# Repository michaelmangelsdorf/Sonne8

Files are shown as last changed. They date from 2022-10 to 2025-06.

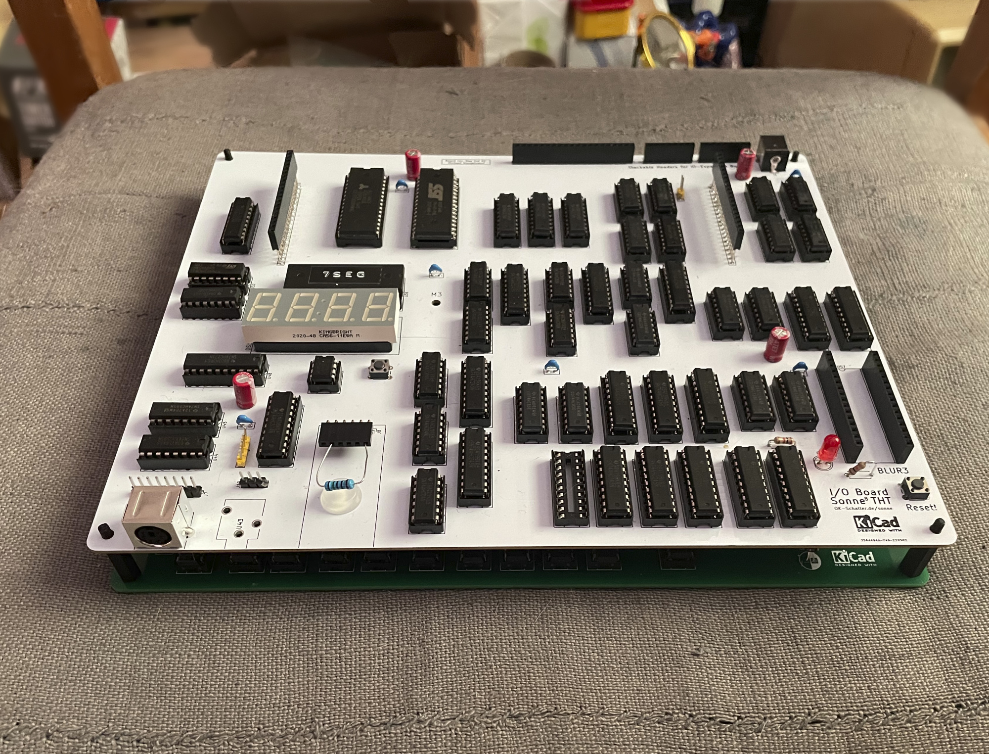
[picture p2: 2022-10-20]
Prototype/board_ready.jpg

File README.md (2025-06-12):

UPDATE: There is now a [successor project](https://github.com/michaelmangelsdorf/myth).

Computer project around an 8-bit microcontroller I've designed.

There are design files for a working single-board computer built around it in the 'Prototype' folder. I've had the PCB for it manufactured by JLCPCB during various revisions. The computer now works fine at 8 MHz system clock, which corresponds to around 1 million instructions per second. The main components are all 74HC-series CMOS chips. I basically wanted to design a CPU I could actually build from parts, not just inside an FPGA like [my previous](https://github.com/Dosflange/Paver) 16-bit machine.

The current reference schematics I'm using are [here](https://github.com/Dosflange/Myth/blob/main/docs/static/myth.pdf).
If I were to build another board, it would probably be based on the KiCad files in the 'Schematics' folder, where I
separated the schematics into functional modules.

So what this image shows is not an application board with an Arduino or anything, it is the actual microcontroller. The current version
has exactly 100 chips.

CPU board

There are two software emulators I've written for this system. The code is very small, hopefully it's a good reference for finding out about the CPU.
The decoder-based [implementation](https://github.com/Dosflange/Myth/blob/main/Dev/src/clox/myth.h) is more high-level, and
the [dispatch table](https://github.com/Dosflange/Myth/blob/main/Dev/src/clox/vtable.c) version better suited to finding out about particular instructions.

[Documentation WIP](https://michaelmangelsdorf.github.io/Sonne8/)

__Update Sep.24__:

I've written a new assembler for this machine in Go(lang). The first thing I ported from the old format was
this multiplication routine. It multiplies two unsigned 8-bit numbers and returns a 16-bit result.
You can try it out with the tools in the 'Dev' folder.

```
Goldie/LOX assembly log
Page.Offset  Object code  Lid Line# Source text

                        048 0062  ;****** ***************************************************************
                        048 0063  P[Mul8]+  (Multiplies R by O, result in R and O)
                        048 0064  ;****** ***************************************************************
                        048 0065  
21.00:  07 5E           043 0066        OWN i6        (Save return pointer in L7/L6)
21.02:  79              043 0067        o1            (Multiplicand into L1, turns into low order result)
21.03:  68              043 0068        r0            (Multiplier into L0)
21.04:  10 6A           043 0069        CLR r2        (Clear high-order result, copy to L2)
21.06:  85 07           043 0070        ni 07h        (Initialise loop counter, 8 bits)
                        043 0071  
                        043 0072      O[Mul8Loop]
                        043 0073   
21.08:  80 01           043 0074        no 01h        (Bit mask for LSB)
21.0A:  61 18           043 0075        1r AND        (Check if multiplicand has LSB set)
21.0C:  8E 12           043 0076        nf >Mul8Skip  (Skip if not)
21.0E:  60 72 1B 6A     043 0077        0r 2o ADD r2  (Add multiplier to high order result)
                        043 0078  
                        043 0079      O[Mul8Skip]
                        043 0080  
21.12:  80 01           043 0081        no 01h        (Bit mask for LSB)
21.14:  62 18 6B        043 0082        2r AND r3     (Prepare flag of whether high order LSB is set)
21.17:  61 16 69        043 0083        1r SRR r1      (Shift low-order result right)
21.1A:  62 16 6A        043 0084        2r SRR r2       (Shift high-order result right)
                        043 0085  
21.1D:  63 8E 25        043 0086        3r nf >Mul8Done  (Check flag from earlier - HO LSB set?)
21.20:  84 80           043 0087        nr 80h          (Bit mask for MSB)
21.22:  71 19 69        043 0088        1o IOR r1     (Handle shift-result carry bit into MSB)
                        043 0089  
                        043 0090      O[Mul8Done]
                        043 0091  
21.25:  8C 08           043 0092        nw <Mul8Loop
21.27:  71              043 0093        1o            (Result low-order)
21.28:  62              043 0094        2r            (Result high-order)
21.29:  56 05           043 0095        6i RET        (Restore return pointer from L7/L6)
```

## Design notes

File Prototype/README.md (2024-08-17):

Welcome to this project!

/* Update: I've presented this at CrashSpace in Culver City (Los Angeles) on October 10th, 2023 and donated my build of the controller, including two spare PCBs. So if you're in the area and would like to work on it / have questions, ask anytime. Thanks to all who where there, physically and online, and for the tour of your premises! */

This repo contains all files you need to build and program an 8-bit CPU that I have designed und built.

It's not even micro-coded, so it's very simple, although I wanted it to be sane and fun to code for instead of minimal. It's easy to create custom instructions, it's got single-cycle trap calls that don't appear different from inbuilt opcodes.

You would need to have the two PCBs fabricated: Firstly, there's the CPU board itself.
It is actually a micro-controller, in that this board implements RAM and an IO interface.
Then secondly, there is an IO expansion board, that fits on top of the CPU board via Arduino type stackable headers.

What can it do? Well, the demo program computes 7 x 13 and shows the result (5B in hexadecimal) on a 7-segment display (see the mul16 movie in the repo)... Behind the scenes, it reads the code for doing that by bit-banging the SPI interface of a serial EEPROM on the IO board. So it's a micro-controller alright.

The two KiCad boards work fine!, I've had them manufactured by JLCPCB. The project files in the repo correspond to what I sent them. The screenshots (jpeg) of the boards show details. I've soldered sockets for all chips to be safe. The quartz oscillator I used is 8MHz, which corresponds to roughly 1 Million instructions per second.

The CPU board looks like this (this is an older version, notice the wire patch):

CPU board

These plastic spacers go between the CPU board and the IO board. The distance/length of the spacer part (without the protruding thread) is 2 cm.

CPU board

Both modules go together like so:

CPU board

The assembled development kit i.e. hardware portion of this project:

CPU board

The entire lower right quarter of the IO board doesn't really need to be populated, but you can of course. The large chip socket on the right
is just a place-holder that connects straight through to the identical EEPROM socket just below it on the CPU board.
That EEPROM is actually the ALU of the CPU. It does via simple look-up tables, what the discrete version on the IO board does with logic chips.

## Address space

The address space of this CPU is unusual. Eight bits give you 256 address places. The first 128 places form a segment, which can be switched to point to another memory segment ("bank switching"). The next 64 places after that are fixed (for global variables). The remaining 64 places form a segment again, which can be switched out to point to another memory segment (for local variables).

### Global segment

This 64 byte segment serves as a global (i.e. persistent during subroutine calls) data repository.
The first eight addresses (128-135) of it are referred to as G0-G7 (G for global) and there are special single-cycle instructions for transfering these values to and from the two accumulator registers. These locations are essentially additional registers.

### Local segment

This 64 byte segment serves as a stack frame, which can be swapped out by the following two instructions.
The first eight addresses (192-199) of it are referred to as L0-L7 (L for local) and there are special single-cycle instructions for transfering these values to and from the two accumulator registers. These locations are essentially additional registers local to the current subroutine!

#### Leave and Enter

The LEAVE signal increments an internal address prefix. This causes the final 64-bytes ("local" segment) of the address space to point to the previous stack frame. The ENTER signal decrements the internal address prefix, causing a new stack frame to appear in the "local" segment.

## Binary Instruction Format

There are four types of instructions. The format is completely regular and you would have no problem hand-coding these opcodes!

SIGNAL
If bit 7 is clear, and bits 0-3 are all zero, the instruction is of type SIGNAL. There are sixteen such instructions, corresponding to each combination of bits 4-6. These instructions trigger internal signals.

RCOPY
If bit 7 is clear, and bits 0-3 are *not* all zero, the instruction is of type RCOPY. In this case, bits 0-3 encode one of eight possible source registers, and bits 4-6 encode one of sixteen possible target registers. Each instruction of type RCOPY copies the value of its source register into its target register.

TRAP
If bit 7 is set, but bit 6 is clear, the instruction is of type TRAP, and bits 0-5 encode the memory bank address of a trap handler function. Each TRAP instruction performs a function call to the first byte of its trap handler bank.

GETPUT
If bits 6-7 are both set, the instruction is of type GETPUT. These instructions copy values between the first eight bytes (G0-G7) of the global segment or the first eight bytes (L0-L7) of the local segment and registers A or B.
Bits 0-5 encode the operation of each such instruction in the following way.
Bit 5 encodes the source or destination register: 0=A, 1=B
Bit 4 encodes the segment: 0=Global, 1=Local
Bit 3 encodes the operation: 0=Read (Get), 1=Write (Put)
Bits 0-2 encode the byte offset within the segment
Example:
The mnemonic "aG3g" ("a G3 get") would mean:
"a": Register A is the target of the operation. "G": Global memory is being used. "3": The third location in global memory is being accessed. "g": Get operation, the value from the specified memory location is being read and loaded into register A. So, "aG3g" instruction gets the value from the third location of global memory and loads it into register A.

### Signal instructions

These are used to trigger specific operations that don't require explicit arguments, such as IO operations or creating/destroying stack frames.

### Register-to-register transfers ("RCOPY")

These instructions copy the content of one register into another. GA for instance copies the value of G into A. Some registers are pseudo registers, such as B (Branch) -- copying a source register into B branches to the location stored in the source register. See the descriptions of individual registers below. 

#### Scrounge instructions

Instructions such as MM or SS that would essentially do nothing ("NOP"), and instructions such as LM which would conflict with the timing requirements and the complexity of the hardware required, are detected (preselected) by a logic module called the scrounger, and they are treated as entirely different instructions -- their opcode is "repurposed". For instance, the opcode with regular mnemonic LM is scrounged and repurposed as opcode for the RET instruction.

Not all such "NOP" opcodes are "scrounged" and could potentially be used as CPU instruction set extensions in future versions.

### Trap calls ("TRAP")

When a TRAP instruction is encountered during program execution, it triggers a transparent subroutine call to a user-defined TRAP handler routine. This handler routine acts as the implementation of the custom instruction, enabling the execution of specialized operations that go beyond the capabilities of the standard built-in instructions.

User-defined instructions implemented through trap handlers are indistinguishable from pre-existing built-in instructions. They allow developers to create new instructions that appear and behave just like native instructions to the processor.

Flexible Byte Lengths:
Custom instructions defined through trap calls can have variable byte lengths. The PULL instruction facilitates this. It allows the custom instruction's handler routine to access subsequent bytes in the instruction stream, enabling the retrieval of data or parameters specific to the functionality of the custom instruction. This flexibility opens up possibilities for instructions with different byte lengths tailored to specific requirements, such as immediate addressing.

In this way, the TRAP mechanism in Sonne architecture allows you to effectively "extend" the instruction set with your own custom operations. By strategically writing and calling these trap handlers, you can enhance the functionality of the processor in ways that go beyond the capabilities of the built-in instructions. 

### Memory-Register-Memory transfers ("GETPUT")

These instructions copy values between the 8 bytes G0-G7 of the global segment or the 8 bytes L0-L7 of the local segment and registers A or Q.

#### Examples

The mnemonic "aG3g" ("a G3 get") would mean:

"a": Register A is the target of the operation.
"G": Global memory is being used.
"3": The third location in global memory is being accessed.
"g": Get operation, the value from the specified memory location is being read and loaded into register A.
So, "aG3g" instruction gets the value from the third location of global memory and loads it into register A.

"aL7p": This instruction would put the value from register A into the seventh location of local memory.
q: Indicates that the data (Q) register is the source or target of the operation.
"qG2g": This instruction would get the value from the second location of global memory and load it into register Q.
"qL5p": This instruction would put the value from register Q into the fifth location of local memory.
Remember that in these mnemonics, the first character ("a" or "q") denotes the register being operated upon, the second character ("G" or "L") specifies the scope of the memory being accessed (Global or Local), the third character (a digit from 0-7) specifies the location in the specified memory, and the last character ("g" or "p") specifies the operation (Get or Put).

## Fetch mechanism

The X register holds the byte offset for instruction fetches. It represents the byte offset within the code branch (frame) from which the next instruction will be fetched.
The X register is incremented by 1 after each instruction, so that the next instruction is pointed to.
Jump instructions reset the X register to 0 (!), jumps are made to first bytes (offset 0) of a target bank.

The Y register holds the pending code branch (high order portion or "bank"). The value stored in the Y register represents the code branch that will be resumed upon executing a RET instruction.

The LID instruction (LID stands for the English word "lid") resets the byte offset for instruction fetches to 0, and increments the current frame by 1.
LID is called "LID" because it effectively closes ("puts a lid on") the currently executed frame.

In the assembler code I provided, a "." assembles to a LID opcode. So a dot in an assembler listing closes the current frame and begins at the next frame, byte offset 0. It is just a shorthand for explicitly writing LID.

## Groups of registers

### L

L stands for literal. It's a pseudo-register that can only be a source in register-register transfers. The value transfered is the next byte in the instruction stream, which is then skipped.

### A, B and M

M is a pseudo-register. Reading or writing it transfers between memory and a register operand.
The last recently used ALU register - A or B - is the implied offset address register that combines with a bank register to give the effective address.

### R

The R register holds the bank prefix of the 128 byte "row" region from 0-127 of the address space. Changing R switches all 128 bytes simultaneously by address mapping.

### J, E, T

These are pseudo-registers, that can only occur as register-targets in transfers. Transfering a value to B does an unconditional jump to that "branch". You can't jump to a byte offset, only to the first byte offset (0) of a branch. E means Else - the branch is taken when the ALU result is zero. T means Then - the branch is taken when the ALU result is not zero.

### C, X, Y

The C register is a pseudo register, that can only occur as a register-target in transfers. Transfering a value to C executes a subroutine call. The "branch" get's stored in Y, the byte offset for instruction fetches within that "branch" gets stored in X. By writing values into X and Y, the return address can be redirected. The RET signal returns from the subroutine, by restoring the "branch" and byte offset from X and Y. The PULL signal transfers the current X into A, and the current Y into R.

### A, B, F

A and B are two accumulator registers. These are the two input operands connected to the ALU (Arithmetic-Logic Unit). F stands for Function. Writing an ALU opcode to F computes the respective function. Reading from F yields the result.

A and B are not readable directly. The intended way is to execute one of the identity functions of the ALU, IDA or IDB.

To prepare ALU input values, program the ALU, and retrieve the result, the following steps are typically involved:

Load Operand Values: The input values for the ALU operation need to be loaded into the A and B registers. This can be done by transferring values from memory or other registers to the A and B registers using appropriate transfer instructions.
Set ALU Opcode: Determine the specific ALU operation you want to perform and set the corresponding ALU opcode. The ALU opcode is written to the F register, which programs the ALU to perform the desired operation.
Execute ALU Operation: Trigger the execution of the ALU operation by performing an ALU instruction that uses the A and B registers as source operands and the F register as the target. The ALU will perform the specified operation on the input operands and store the result in the F register.
Retrieve Result: After the ALU operation is executed, the result will be stored in the F register. Retrieve the result from the F register for further processing or storing in memory if needed.
These steps ensure that the input values are properly prepared, the ALU is programmed with the desired operation, the ALU operation is executed, and the result is retrieved for subsequent use or storage.

In Sonne, the F register functions differently depending on whether it is used as an input register or when it is read from. This distinction is important and can be easily overlooked.

When the F register is used as an input register, it serves as a parameter to program the ALU's operation. The value written to the F register determines the specific ALU opcode, which in turn determines the arithmetic or logical operation to be performed. It essentially configures the ALU's behavior for the subsequent operation.

On the other hand, when the F register is read from, it holds the most recent result produced by the ALU. This result reflects the outcome of the operation executed using the previously programmed ALU opcode. In this context, the F register acts as a storage location for the ALU result, allowing it to be accessed by subsequent instructions or transferred to other registers.

This distinction highlights the dual role of the F register in Sonne: as a configuration parameter for the ALU when written to, and as a storage location for the ALU result when read from. It is important to understand this behavior to properly utilize the ALU and interpret the effects of instructions involving the F register.

### ALU instructions

ALU instruction words (to be written to the F register) are bytes. The low order 4 bits encode the following 16 instructions:

```
|--- | --- | --- |--- |
| 0 |   IDA | Identity A | F := A |
| 1 |   IDB | Identity B | F := B |
| 2 |   OCA | Ones Complement A | F := ~A |
| 3 |  OCB | Ones Complement B | F := ~B |
| 4 |   SLA | Shift left A | F := A<<1 |
| 5 |   SLB | Shift left B | F := B<<1 |
| 6 |   SRA | Shift right A | F := A>>1 |
| 7 |   SRB | Shift right B | F := B>>1 |
| 8 |   AND | Logical A AND B | F := A&B |
| 9 |   IOR | Logical A OR B | F := A\|B |
| 10 |  EOR | Logical A XOR B | F := A\^B |
| 11 |  ADD | Bits 0-7 of A+B | F := (A+B)&255 (ignore carry) |
| 12 |  CYB | Carry bit of A+B | F := A+B; F := (F>255)?1:0 |
| 13 |  ALB | A less than B | F := (A<B)? 0xFF:0 |
| 14 |  AEB |A equals B | F := (A==B)? 0xFF:0 |
| 15 |  AGB |A greater than B | F:= (A>B)? 0xFF:0 |
```

The high order 4 bits hold a signed 3 bit offset which is added to the ALU result. In the assembly language, these mnemonics can be followed by an optional number term, such as IDA+2, SLB+1 etc. The default ALU operation on reset is "IDA+0".
Read ALU results from the F register.

## IO

### D, S, P

The D register selects IO bus devices in an implementation specific way (for example SPI device select etc). Writing to P (Parallel) transfers a byte onto the tri-state IO bus. Reading from P transfers a byte from the IO-bus. Use the OFF signal to tri-state the bus. Writing to P also removes the tri-state.

Writing to the S (Serial) register puts that byte into a shift-register for serialization. The CSO signal ("clock serial out") shifts out one bit on the MOSI line. Reading from S yields the currently deserialized byte in the shift-register. The CSI signal ("clock serial in") shifts in one bit from the MISO line. The SCH and SCL signals respectively toggle the serial master clock high or low.

The serial interface facilitates serial communication between the CPU and external devices.
The S (Serial) register acts as a shift register, allowing data to be transmitted or received bit by bit.
The CSI (Clock Serial In) instruction clocks the serial input shift register, reading in data.
The CSO (Clock Serial Out) instruction clocks the serial output shift register, sending out data.
Device Selection:
The D register is involved in device selection for serial or parallel communication.
By setting specific bit patterns in the D register, the CPU can select specific devices connected to the bus for communication.

### Parallel IO

Parallel Interface:
The parallel interface enables communication between the CPU and external devices using a parallel bus.
The P (Parallel) register is used for data transfer. Reading from the P register retrieves a byte value from the parallel bus, and writing to it sends a byte value onto the bus.
The OFF instruction can be used to tristate the parallel bus, disabling its output when necessary.

### Serial IO

The Serial Peripheral Interface (SPI) protocol can be implemented using the Sonne processor's instructions, including SCL, SCH, CSI, and CSO, along with proper configuration of control signals. Here's a description of how the SPI protocol can be implemented with the Sonne instructions:

In addition to the serial input and output shift registers, the Sonne processor utilizes the U and V registers for device selection and deselection in serial communication.

Here's an expanded summary of the serial communication capabilities of Sonne, including the roles of U and V:

Device Selection: Before communicating with a specific device connected to the serial bus, the corresponding bit pattern representing the device must be set in either the D register. This selection process ensures that the desired device is enabled for communication.
Data Transmission: To transmit data to the selected device, the processor loads the data to be sent into a register or memory location. The CSO (Clock Serial Out) instruction is then executed, which clocks the serial output shift register. As each bit is shifted out, it is sent to the selected device through the serial bus.
Device Deselection: After data transmission is complete, the selected device needs to be deselected to allow other devices to communicate on the bus. This is done by clearing the bit pattern in the D register corresponding to the device. Deselecting the device prevents further communication with it.
Data Reception: To receive data from an external device, the CSI (Clock Serial In) instruction is used. It clocks the serial input shift register, allowing the processor to receive one bit of data at a time from the selected device. The received data can then be processed or stored in registers or memory.
By utilizing the D registers for device selection and deselection, the Sonne processor can communicate with different devices connected to the serial bus in a controlled and synchronized manner. It allows for flexible communication with multiple devices using a serial interface such as SPI, ensuring proper device selection and enabling reliable data transmission and reception.

CPOL (Clock Polarity):
The CPOL parameter determines the idle state of the clock signal.
In Sonne, the SCL (Set Clock Low) and SCH (Set Clock High) instructions can be used to control the clock signal's state.
To configure CPOL=0 (clock idles low), execute SCL to set the clock signal low during the idle state.
To configure CPOL=1 (clock idles high), execute SCH to set the clock signal high during the idle state.
CPHA (Clock Phase):
The CPHA parameter determines the edge of the clock signal where data is captured or changed.
In Sonne, the CSI (Clock Serial In) and CSO (Clock Serial Out) instructions can be used to control data transfer on each clock transition.
To configure CPHA=0 (data captured on the leading edge), execute CSI before the clock transition to capture the incoming data.
To configure CPHA=1 (data captured on the trailing edge), execute CSI after the clock transition to capture the incoming data.
Similarly, to transmit data on the leading or trailing edge, execute CSO before or after the clock transition, respectively.
Slave Select (SS) Signal:
In SPI, a Slave Select signal is used to enable/disable specific devices on the bus during communication.
In Sonne, the U and V registers can be utilized to control the Slave Select (SS) signal.
Before initiating communication with a specific device, set the corresponding bit pattern in the D register to select the device.
After communication, clear the bit pattern in the D register to deselect the device.
By combining the SCL, SCH, CSI, and CSO instructions along with appropriate configuration of the control signals, the Sonne processor can effectively implement the SPI protocol. This allows for synchronized and controlled data transfer with SPI-compatible devices, including the flexibility to configure CPOL, CPHA, and SS signals to meet the specific requirements of the SPI interface.

### Parallel Interface
The P (Parallel) Register: Writing to the P register sends a byte of data onto the parallel bus, and reading from the P register receives a byte of data from the parallel bus.
The OFF instruction: This is used to tristate the parallel bus, disabling its output when necessary.

### Serial Interface
The S (Serial) Register: Writing to this register puts a byte into a shift-register for serialization. Reading from this register yields the currently deserialized byte in the shift register.
The CSO Instruction (Clock Serial Out): This instruction shifts out one bit on the MOSI (Master Out Slave In) line from the byte currently held in the shift register.
The CSI Instruction (Clock Serial In): This instruction shifts in one bit from the MISO (Master In Slave Out) line to the shift register.
The SCH and SCL Instructions: These are used to toggle the serial master clock high or low respectively.

### Device Selection
The D register: Each bit in this register selects a specific I/O device, like an SPI device select. This allows for specific device communication during parallel or serial transmission.
 
### Implementing SPI protocol
Through the appropriate use of the S Register and the CSO, CSI, SCH and SCL instructions, the Sonne CPU can implement Serial Peripheral Interface (SPI) communication with external devices.

# Alternative Write-up

## Sonne Programmer's Overview
## Register Model and Instruction Set

## Preliminaries

Bits are numbered starting from 0 (least significant bit) to 7 (most significant bit). Clearing a bit means setting it to zero. Setting a bit (without giving the explicit value 0) means setting it to 1. A byte is an 8-bit number. A nybble is a 4-bit number. A signed binary number means a number in twos-complement notation, its most significant bit representing the numerical sign.

### Assembler Notation

Comments are introduced by a semicolon (";"). Everything on the same line after the semicolon is ignored.

Commas (",") can be used for grouping "phrases" of instructions that logically belong together. They don't generate code and are just for visual clarity.

A dot (".") is shorthand notation for and produces the same output as the "LID" instruction. The assembler will insert the LID-count at offset 127 of the current bank, and place subsequent code into the next bank at offset 0. The dot can be added after other elements without separating space.

#### Number Literals

Decimal numbers from 0-255 can be included the source text as literals, and be prefixed by an optional minus sign. Hexadecimal numbers must be in two uppercase digits and marked with the suffix "h", for instance: "80h" for 128. Binary numbers must be formatted as two 4-bit groups separated by a dot (".") and have the suffix "b", for instance: "0010.0000b" for 32.

#### Code Labels

Code labels are alphanumeric identifiers, preceded with an at-sign ("@") instead of the conventional colon (":") at the end. Code labels mark the beginning of banks (offset=0), and only one label is allowed per bank. This reflects the fact, that branches or calls are made to banks, rather than offsets.

Code labels that mark the beginning of TRAP handler functions must be unique  and referenced by prefixing their identifier by an asterisk ("*").

Such label references will generate an opcode that will trigger a TRAP and call the handler function referenced by the label.
Other labels are referenced by prefixing their identifier with "<" (for backward references, i.e. the label is defined earlier in the source code than the reference to it), or with ">" (forward reference, i.e. the label is defined later than the reference to it in the source code). If a label is not unique, the reference goes to the nearest occurrence of it.

#### Instruction Mnemonics

Mnemonics for Signal PAIR and ALU instructions generate the opcode they map to, for instance "ENTER" generates opcode 112. For ALU instructions, the signed offset can be omitted and defaults to 0 ("SLA+1", "ADD" = "ADD+0", etc.)

Mnemonics for transfer PAIR instructions are two-letter uppercase words such as "FA" (take F into A). Mnemonics of the form ("Nx") for transferring a literal embedded in the code stream into a target register, must be followed by that number, ALU mnemonic or other value to be transferred. For instance "NF SLA" transfers the ALU opcode corresponding to SLS into the function selector register F. "NA 80h" transfers the number 128 into register A.

#### Get-Put Mnemonics

The format for these mnemonics is register + memory location + offset + operation with no intervening space. Register must be lower case "a" or "b". Memory location is upper case G or L. Offset is in the range 0-7. Operation is lower case "g" (get) or "p" (put). 
So, "aG3g" instruction gets the value from the fourth location of global memory (same as bank G, offset 83h) and loads it into register A.

# Part A. Computation

This part explains the core features of the CPU, and for brevity and clarity is limited in scope to those that are intended for computation and addressing internal memory. Part B explains additional, structurally equivalent features that are dedicated to communication with peripherals and can be listed as  mere extensions to what has already been said.

## Addressing

In Sonne, the primary means of addressing memory are 8-bit numbers called offsets, ranging from 0-255. This offset range is partitioned into three segments. As further explained below, the segment in which a particular offset is located determines, which 8-bit bank prefix register is used in generating the effective address. The notation for this is [bank,offset]. This segmentation mechanism achieves, that an 8-bit offset carries a fully implied bank register, considerably extending the addressable range in an intuitive way.

### Banks

Bank numbers are stored in dedicated bank registers. Which bank register is used in accessing memory depends on the segment (see below) in which a given offset address is located, and also depends on whether the memory access is fetching (reading the code stream), or instead reading or writing other data.

This is much simpler in practice than how it sounds in full technical detail, much like the engineering details of a car can seem overwhelming when in reality driving is quite easy.

As has been said, the 256 offset places are partitioned into three segments. A given offset is located in exactly one of the three segments, and a given offset thus uniquely implies the bank prefix register used to create the effective address used.

#### ROW/EXIT segment

If the offset is in the range 0-127, bank register R (Row) is used during data access and bank register E (EXIT) is used when fetching (reading the code stream).

#### GLOBAL and LOCAL segment

The remaining two offset ranges apply for both data access and instruction fetch.

##### Global segment

If the offset is in the range 128-191, bank register G (Global) is used.

This 64 byte segment serves as a global (i.e. persistent during subroutine calls) data repository. The first eight addresses (128-135) of it are referred to as G0-G7 (G for global) and there are special single-cycle instructions for transferring these values to and from the two accumulator registers. These locations are essentially additional registers.

##### Local segment

If the offset is in the range 192-255, bank register L (Local) is used.

This 64 byte segment serves as a stack frame, which can be swapped out by the ENTER and LEAVE instruction. The first eight addresses (192-199) of this segment are referred to as L0-L7 (L for local) and there are special single-cycle instructions for transferring these values to and from the two accumulator registers. These locations are essentially additional registers local to the current subroutine!

#### CPU Internal Addressing

You may have noticed that, since the ROW segment (and also the GLOBAL+LOCAL segments combined) span only 128 bytes instead of the full range of 256 bytes, incrementing a bank register seems to leave 128 bytes of each bank unused.

In order to utilise all of the memory, only the first 7 bits of the offsets are appended to the bank number. The high order bit is actually used as an indicator of LOCAL/GLOBAL access and *prefixed* to the bank number.

In other words, the ROW/EXIT segment and the combined GLOBAL+LOCAL segments live in two adjacent memory blocks of 256 banks each with only 128 bytes per bank instead of 256.

Please see the schematics of the CPU to see how this works in detail to avoid "holes" in the address space.

### Offsets

During instruction fetch, the implied offset is retrieved from the program counter (PC).

During data access, the implied offset is retrieved from the working register W. W is a construct that refers to the last recently written-to accumulator register, A or B. Rather than being a separate register, W is simply a mechanism to point to either of the two accumulator registers.

Whenever a transfer instruction is executed to load data into A or B, "W" is updated to point to that register. For example, if the instruction xA is executed, then the source value is transferred into register A, and W is set to A. Similarly, if the instruction xB is executed, the source value is transferred into register B, and W is set to B.

### Memory access

During instruction fetch, an instruction is fetched from [E, PC].

All other memory operations are achieved by transferring register values into or out of the M (Memory) pseudo-register. The implied memory location is always [R/G/L, W]. In this notation, R/G/L stands for the bank prefix register corresponding to the offset segment in which the offset stored in the working register W is located.

For example, if A is the working register and contains the number 20, the effective address will be the concatenation of the bank address prefix in register R (since the offset 20 lies in that segment) and the offset 20 itself. Therefore, the instruction FM for instance will store the ALU result F into [R, 20].

There is also a dedicated instruction type (Get-Put) which allows transferring values in and out of the accumulator registers into the first 8 locations of the global and local segment, respectively. This is identical to addressing offsets 80-87h (first 8 bytes of global segment) and C0-C7h (first 8 bytes of local segment) but requires only a single instruction and no overhead for setting up address offsets.

## Arithmetic-Logic Computations

The Sonne model includes an Arithmetic-Logic Unit (ALU) connected to the two accumulator registers A and B. The ALU can perform a set of 16 operations on the contents of A and B, controlled by writing an ALU opcode to the function register (F). Results are retrieved by reading from register F. A zero flag used in conditional branching (see below) is computed together with the result. Writing an ALU opcode to F computes the respective function. Reading from F yields the result.

Writing into registers A or B sets that register to be the new working register (W), and sets a HOLD flag (H) which freezes the result in F, until another ALU opcode is written into F which frees the hold (resets H).

This mechanism is required so that the working register (A or B) can be used as destination offset for storing the ALU result. Without it, altering A or B to contain an address offset for storing the ALU result, would generally trigger an additional ALU operation that could modify the result, which is still in F, before it's even stored. By activating HOLD, the ALU freezes its current state, allowing for modifications to A or B for addressing purposes without triggering a new, potentially result-altering, ALU operation. The HOLD is released when the next ALU opcode is written, allowing for the resumption of regular ALU operations. In essence, HOLD ensures the proper sequence and integrity of computational and memory operations.

### ALU opcodes

An ALU opcode is a byte, in which bits 0-4 encode one of the following 16 instructions, and bits 5-7 encode a signed 3-bit binary number which is added to the result. 

Opcode bits 0-3 to the left, followed by mnemonic, description, and pseudo-code

|--- | --- | --- |--- |
| 0 |   IDA | Identity A | F := A |
| 1 |   IDB | Identity B | F := B |
| 2 |   OCA | Ones Complement A | F := ~A |
| 3 |  OCB | Ones Complement B | F := ~B |
| 4 |   SLA | Shift left A | F := A<<1 |
| 5 |   SLB | Shift left B | F := B<<1 |
| 6 |   SRA | Shift right A | F := A>>1 |
| 7 |   SRB | Shift right B | F := B>>1 |
| 8 |   AND | Logical A AND B | F := A&B |
| 9 |   IOR | Logical A OR B | F := A\|B |
| 10 |  EOR | Logical A XOR B | F := A\^B |
| 11 |  ADD | Bits 0-7 of A+B | F := (A+B)&255 (ignore carry) |
| 12 |  CYB | Carry bit of A+B | F := A+B; F := (F>255)?1:0 |
| 13 |  ALB | A less than B | F := (A<B)? 0xFF:0 |
| 14 |  AEB |A equals B | F := (A==B)? 0xFF:0 |
| 15 |  AGB |A greater than B | F:= (A>B)? 0xFF:0 |

## Exit Instructions

The term EXIT instruction refers to any instruction that overwrites register E (EXIT), which contains the currently active bank prefix for fetching instructions.  EXIT instructions are either transfer instructions into J, E, T (JUMPS) or into C (CALLS), the RET instruction (RETURN from subroutine) or TRAP instructions.

### Branching

Branching is done to banks, not offsets. During a branch, the program counter (PC) register holding the current instruction offset is set to zero, and the EXIT bank register is loaded with the target bank to which control control is transferred.

Even though it might seem limiting to only be able to branch to the start of a bank, this can actually lead to clean and well-structured code, as each bank can be thought of as a self-contained part of code that does one specific task within a function.

#### Registers J, E, T

These are pseudo-registers, that can only occur as register-targets in transfers. Transferring a value to J does an unconditional jump to that "branch". You can't jump to a byte offset, only to the first byte offset (0) of a branch. E means Else - the branch is taken when the ALU result is zero. T means Then - the branch is taken when the ALU result is not zero.

The LID instruction (see below) is an implicit jump to offset 0 of next bank. LID resets PC to 0 and increments the bank register by 1.

### Calling and TRAP mechanism

#### Registers C, X, Y

Transferring a value to C executes a subroutine call.  Executing a TRAP instruction has the same effect, except that with C, TRAP destinations can be calculated and provided by a source register at run-time.

During a call or TRAP (see below), the "branch" (register E) get's stored in Y, and the byte offset (register PC) of the instruction gets stored in X. Following that, register E is overwritten with the target bank number, and PC is set to zero.  By altering these values in X and Y, the return address can be redirected, for example in coding custom control-flow instructions.

Registers PC and E can be restored from X and Y by executing RET. This "undoes" the call and returns to the point just after the instruction which triggered the call. Unlike other CPU's, only one call-level is retained. Sonne does not manage a dedicated return stack, and you must save X and Y (see above) into the local segment yourself when implementing nested calls. These return coordinates then essentially become local variables.

#### Local Variables

The local segment can be used as a stack frame for local variables such as the subroutine return address. Executing ENTER decrements the L bank register, and LEAVE increments this register. Since bank registers are used implicitly, any subsequent memory access to the local offset segment will "see" whatever frame is mediated by L.

## TRAP instructions

TRAP instructions are otherwise indistinguishable from other instruction types, except they have bit 7 set and bit 6 cleared. The target bank number is encoded in the remaining lower 6 bits (0-5), hence banks 0-63 can be used to store trap handler functions. These are typically thought of as instruction set extensions stored in ROM.

## Get-Put Instructions

These instructions copy values between the first eight bytes (G0-G7) of the global segment or the first eight bytes (L0-L7) of the local segment and registers A or B.

Example:

The mnemonic "aG3g" ("a G3 get") would mean: "a": Register A is the target of the operation. "G": the global segment is being used. "3": The third location of the global segment is being accessed. "g": Get operation, the value from the specified memory location is being read and loaded into register A.

So, "aG3g" instruction gets the value from the third location of global memory and loads it into register A.

### Opcode Format

Get-Put instructions are those in which bits 6-7 are both set. Bits 0-5 encode the operation of each such instruction in the following way.
Bit 5 encodes the source or destination register: 0=A, 1=B.
Bit 4 encodes the segment: 0=Global, 1=Local.
Bit 3 encodes the operation: 0=Read (Get), 1=Write (Put).
Bits 0-2 encode the byte offset within the segment.

## PAIR Instructions

### Opcode Format

Instructions of type PAIR have bit 7 set to 0. There are two subtypes. If bits 0-3 are all zero, bits 4-6 encode a signal. If bits 0-3 are not all zero, the instruction is a register-to-register transfer, where bits 0-3 encode the target register and bits 4-6 encode the source register.

### Signals (bits 0-3 all zero)

These instructions trigger hardware functions.
NOP: No Operation

<Communication signals, see part B below>

LEAVE: Decrement bank register L
ENTER: Increment bank register L

### Register Transfers (bits 0-3 not all zero)

These instructions are mnemonically represented as "ST", where S represents one of the 8 source registers, and T represents one of the 15 target registers (target register 0 being SIG, a special case used only as a marker to identify SIGNAL instructions, see above). They copy the value of the source register into the target register, or in the case of pseudo-registers, interpreting the source value in a specific way for operations such as branching.

Note regarding register X and Y:  Once these registers are saved to local variables for instance, they can be used as a general purpose registers within the current function.

#### TARGET registers:

To name a target register without a source register attached in mnemonic form, prefix it with an "x" that stands for any source register.

xR (Set ROW bank prefix register)

xM (Store into [R/L/G, W])

xX (Set PC offset value that RET jumps to). If this register is saved to a local variable, for instance, it can be used as a general purpose register within the current function.

xY (Set EXIT bank value that RET jumps to)

<Communication target registers, see part B below>

xF (Set ALU opcode, deactivate ALU hold)

xA (Set accumulator register A, and set A as working register, activate ALU hold)

xB (Set accumulator register B, and set B as working register, activate ALU hold)

xJ (Unconditional jump, set EXIT bank register to the transferred value)

xT (Jump and set EXIT bank register to the transferred value, if ALU result not zero)

xE (Jump and set EXIT bank register to the transferred value, if ALU result zero)

xC (Call subroutine, save EXIT bank register to Y, save PC into X, set PC to 0, overwrite EXIT bank with transferred value)

xG (Set GLOBAL bank prefix register)

#### SOURCE registers:

To name a source register without any target register attached in mnemonic form, add an "x" to it that represents any target register.

Nx (Take number literal from [EXIT,PC], then increment PC)

Rx (Take value of ROW bank prefix register)

Mx (Load memory value from [R/L/G, W])

Xx (Take value of register X)

Yx (Take value of register Y)

Fx (Take ALU result value)

<Communication source registers, see part B below>

### Scrounging

Transfer instructions such as MM, XX, YY etc, which would essentially do nothing ("NOP") or conflict with the timing requirements and hardware complexity, are detected (preselected) by a logic module called the scrounger, and they are treated as entirely different instructions -- their opcode is "repurposed". For instance, the opcode with regular mnemonic NM is scrounged and repurposed as opcode for the RET instruction, because to allow fetching a byte from the code stream and storing it into memory within the same instruction cycle would unreasonably complicate the CPU hardware.

Not all such "NOP" opcodes are "scrounged", and the others could potentially be used as CPU instruction set extensions in future versions.

MM => LID (Close current bank): increment EXIT, set PC to 0
NM => RET (Return): restore PC, EXIT from registers X, Y respectively

# Part B. Communication

Sonne comes with a built-in communication subsystem that can handle both serial and parallel communication. These additional features are for controlling device selection, serial input/output, and parallel input/output.

For instance, there are additional SIGNAL instructions for controlling the serial clock line and putting the parallel bus into a tristate mode, and also dedicated registers for transferring data bytes into and out of the CPU in parallel or serial form.

## Communication Registers

On the hardware side, communication is done using the following implements:

### D

An 8-bit write-only device select register D. The bit pattern stored in this register is intended to be used for enabling/disabling devices attached to the serial/parallel buses. Writing a device select pattern is done by transferring values into register D.

In the reference implementation, the device select byte logically consists of two four-bit halves (nybbles). Each nybble selects one of 16 enable signals via an attached 4-bit decoder. For instance, the lower nybble could generate an enable signal for an input (listening) device on the bus, while the higher nybble could generate a similar signal that enables the transmitting output device required for a particular data bus transfer.

By convention, the value zero selects a null device (not connected), or some initialisation logic, since both nybbles of the D register will typically be zero upon power-up or reset.

### SOR

A write-only parallel-to-serial shift register for serialising an output byte (SOR, serial output register).

Writing an output value for serialisation is done by writing to register S.

### SIR

A read-only serial-to-parallel shift register for deserialising an input byte (SIR, serial input register).

Reading a deserialised input byte is done by reading register S.

### POR

A write-only tri-state register with 8-bit parallel output (POR, parallel output register)

Writing an output byte onto the parallel bus is done by writing to register P. If the parallel bus is in tri-state mode (OFF instruction), a write-operation will end tri-state mode.

### PIR

A read-only 8-bit parallel input register (PIR, parallel input register).

Reading the current 8-bit value on the parallel bus is done by reading register P.

## Communication Instructions

The following additional SIGNAL instructions (see part A above) operate on communication registers:

CSI: shift in one bit from serial data input line into SIR

CSO: shift out one bit from SOR onto serial data output line

SCL: set serial clock line high

SCH: set serial clock line low

OFF: put parallel bus into tristate mode

## Serial IO and implementing SPI

The Serial Peripheral Interface (SPI) protocol can be implemented using the Sonne processor's instructions, including SCL, SCH, CSI, and CSO, along with proper configuration of control signals. Here's a description of how the SPI protocol can be implemented with the Sonne instructions:

In addition to the serial input and output shift registers, the Sonne processor utilises the D register for device selection and deselection in serial communication.

Device Selection: Before communicating with a specific device connected to the serial bus, the corresponding bit pattern representing the device must be set in the D register. This selection process ensures that the desired device is enabled for communication. Data Transmission: To transmit data to the selected device, the processor loads the data to be sent into a register or memory location. The CSO (Clock Serial Out) instruction is then executed, which clocks the serial output shift register. As each bit is shifted out, it is sent to the selected device through the serial bus. Device Deselection: After data transmission is complete, the selected device needs to be deselected to allow other devices to communicate on the bus. This is done by clearing the bit pattern in the U or V register corresponding to the device. Deselecting the device prevents further communication with it. Data Reception: To receive data from an external device, the CSI (Clock Serial In) instruction is used. It clocks the serial input shift register, allowing the processor to receive one bit of data at a time from the selected device. The received data can then be processed or stored in registers or memory. By utilising the U and V registers for device selection and deselection, the Sonne processor can communicate with different devices connected to the serial bus in a controlled and synchronised manner. It allows for flexible communication with multiple devices using a serial interface such as SPI, ensuring proper device selection and enabling reliable data transmission and reception.

CPOL (Clock Polarity): The CPOL parameter determines the idle state of the clock signal. In Sonne, the SCL (Set Clock Low) and SCH (Set Clock High) instructions can be used to control the clock signal's state. To configure CPOL=0 (clock idles low), execute SCL to set the clock signal low during the idle state. To configure CPOL=1 (clock idles high), execute SCH to set the clock signal high during the idle state. CPHA (Clock Phase): The CPHA parameter determines the edge of the clock signal where data is captured or changed. In Sonne, the CSI (Clock Serial In) and CSO (Clock Serial Out) instructions can be used to control data transfer on each clock transition. To configure CPHA=0 (data captured on the leading edge), execute CSI before the clock transition to capture the incoming data. To configure CPHA=1 (data captured on the trailing edge), execute CSI after the clock transition to capture the incoming data. Similarly, to transmit data on the leading or trailing edge, execute CSO before or after the clock transition, respectively. Slave Select (SS) Signal: In SPI, a Slave Select signal is used to enable/disable specific devices on the bus during communication. In Sonne, the U and V registers can be utilised to control the Slave Select (SS) signal. Before initiating communication with a specific device, set the corresponding bit pattern in the U or V register to select the device. After communication, clear the bit pattern in the U or V register to deselect the device. By combining the SCL, SCH, CSI, and CSO instructions along with appropriate configuration of the control signals, the Sonne processor can effectively implement the SPI protocol. This allows for synchronised and controlled data transfer with SPI-compatible devices, including the flexibility to configure CPOL, CPHA, and SS signals to meet the specific requirements of the SPI interface.

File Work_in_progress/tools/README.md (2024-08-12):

This folder contains tools for creating a controller firmware.
The software is based on the KiCad schematics in the Schematics folder.

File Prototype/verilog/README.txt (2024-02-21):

The design has changed considerably, without changing hardware complexity too much. The attached KiCad schematics haven't been tested, but should be faithful to the new design, with few changes required for producing a working board.
The Verilog runs fine on a Terasic DE1Soc board at 50 MHz.

Sonne Microcontroller rev. Myth

This is a CPU design for an 8-bit microcontroller. Addresses are formed by concatenating an 8-bit "page" address prefix and a 7-bit address "offset" byte (of which the MSB selects a paging register), see below. The resulting memory layout consists of 256 pages of 128 bytes each, thus 32 kilobytes of memory.

For byte offsets below 128:
During fetch operations, the C (Code) register provides the page index. When in data context, the D register provides the page index.
For byte offsets above 127:
During instruction or literal fetch operations, the page index is in the G register (GLOBAL).
When in data context (not fetching), the L register provides the page index.

Special instructions called GET-PUT involve the G (GLOBAL) and L (Local) registers. These instructions allow register values A, B, R and I to be copied to and from a four-byte GET-PUT region in both the global and local page. Incrementing and decrementing the L register can be used to implement subroutine stack frames (each of one page).

Accumulator Registers

	There are three accumulator registers, A, B and R. A and B or the ALU input operands. R receives the result of all ALU instructions. R can also be incremented/decremented by small numbers.

Address Registers

	Accumulator registers A and B are address registers. Whenever one of these three is written to, it becomes the active one. The active address register provides the implied address offset for every memory load/store operation.

Register M

	The value in the active address register is the implied offset for all memory transfers. Reading from the M register (instructions of type Mx) combines the implied page index and the implied offset into an effective address.

	The memory value of that address is then copied into the target register of the instruction. For instance the instruction "MA" transfers the memory content stored at the implied address into the A register. Writing to the M register (instructions of type xM) does as before, put replaces the memory content at the effective address with the value of the source register of the instruction. For instance "RM" stores the ALU result into the implied effective memory address.

Instruction Word Format

(Starting from the most significant bit of the instruction opcode)

	Pair Instructions

	If bit 7 of the opcode is 1, the opcode represents a Pair instruction. This name indicates that the remaining low-order bits are composed of two logical bit groups, called Source (bits 4-6) and Target (bits 0-3). These instructions all copy register values from the source register to the target register.
	("Scrounge" instructions re-purpose redundant or impractical combinations such as MM or NM. The instruction NM is scrounged (does not exist) and its opcode gives RET, MM is scrounged and gives REA, RR is scrounged and gives REB, WW gives RER.)

	GET-PUT Instructions

	If bits 7-6 of the opcode are 01, the opcode represents a GET-PUT instruction. Opcodes for Get-Put instructions encode the Register in bits 0-1, mapped as follows: 00=A, 01=B, 10=R, 11=W. Bit 3 selects one of two page bytes. If bit 3 is 0, the global page (255) is used. If bit 3 is 1, the page byte in the L register is used. Bit 2 encodes whether the register value is retrieved from the Get-Put location (GET, bit=0), or written into it (PUT, bit=1).
	Bits 5-4 encode a numeric offset which is added to the page address to obtain the effective Get-Put location.

	Trap Instructions

	If bits 7-5 of the opcode are 001, the opcode represents a Trap instruction.
	The remaining bits 0-4 directly encode the destination address for the corresponding Trap call. When a Trap instruction is encountered during program execution, it triggers a transparent subroutine call to a user-defined Trap handler routine. Since they are single-byte, these calls are indistinguishable from built-in instruction opcodes.

	ALU Instructions

	If bits 7-4 of the opcode are 0001, the opcode represents an ALU instruction.
	There are 16 Function instructions, corresponding to the possible values of bits 0-3, mapped as follows: 0000=IDA, 0001=IDB, 0010=OCA, 0011=OCB, 0100=SLA, 0101=SLB, 0110=SRA, 0111=SRB, 1000=AND, 1001=IOR, 1010=EOR, 1011=ADD, 1100=CYF, 1101=ALB, 1110=AEB, 1111=AGB.

	Result adjustment instructions

	If bits 7-3 of the opcode are 0000_1, the opcode represents an adjustment instruction. The instructions add or subtract a small integer number from R. The mnemonic form is: "P" + decimal value for positive values, and "M" + decimal value for negative values.

	"SYSTEM" Instructions (SYS)

	If bits 7-2 of the  opcode are 0000_0, the opcode represents a SYS instruction. The SYS instructions are NOP, SSI, SSO, SCL, SCH, RDY, NEW, OLD.

Control Flow

In this architecture, calls and traps go to page heads (offset zero). Other branches (jumps) go to offsets within a page.

Branching

	Registers J, F, T, I

	These are pseudo-registers, that can only occur as target registers of transfer instructions. Transferring an offset value into J (Jump) does an unconditional branch to that offset within the current code page.
	F means FALSE: Transferring an offset value into F branches only if R is FALSE (zero).
	T means TRUE: Transferring an offset value into T branches only if R is TRUE (not zero).
	I means iterate: Transferring an offset value into I decrements the loop counter register, and then branches, if that register is zero.

Calling and TRAP mechanism

	Trap instructions jump to offset 0 of the page encoded in the opcode. They also save the return page index in D. The current address offset is saved into the W register, making it the active address register. The offset is then set to 0 and control is transferred to the new page. Storing a page index into pseudo register C has the same effect.

	The RET instruction ("Return") overwrites the current code page index by the value in D, and overwrites the current code offset by the value in W, conceptually reversing a preceding CALL or Trap instruction.

Arithmetic-Logic Unit (ALU)

The instructions compute mathematical functions using one or both of A and B as input arguments. The results are stored into R (Result). R can also be written using register transfers. R has an associated bias register. When reading R, the signed bias is transparently added to the result. The ALU instructions do the following, results are stored in R.

IDA Identity of A
IDB Identity of B
OCA One's complement of A
OCB One's complement of B
SLA Shift left A
SLB Shift left B
SRA Shift right logical A
SRB Shift right logical B
AND Bitwise AND between A and B
IOR Bitwise inclusive OR between A and B
EOR Bitwise exclusive OR between A and B
ADD 8-bit Addition result of A plus B
CAR Carry bit of addition result of A plus B, zero or one
ALB Logical flag (TRUE=255, FALSE=0) A less than B
AEB Logical flag (TRUE=255, FALSE=0) A equals B
AGB Logical flag (TRUE=255, FALSE=0) A greater than B

Review of Source and Target Registers

N (Number Literal as Nx)

Register N is a pseudo-register. When used as a source register, it copies then skips the following opcode into the target register. NM is scrounged, RET is executed instead. When used as a target register, the source register value is copied into the iteration register.

M (Memory)

Register M is a pseudo-register. It can be used as Source or Target of a Transfer instruction.
It is used to transfer values from/to an implied memory cell from/into a register.

I (Iteration register)

The iteration register can be accessed using Get-Put operations, and is used in the xX jump instruction: This instruction decrements I and branches, if I is not zero.

D (Data page index)

It can be used as Source or Target of a Transfer instruction. During Trap and Call instructions, the current code page index is saved into D, and during RET instructions, the current code page index is restored from D.

G (Global page index)

Register G contains the page index for byte indices above 127 during instruction or literal fetch.

L (Local page index)

Register L contains the page index for GET-PUT instructions, and also for byte indices above 127 during data access. The NEW instruction decrements L by 1. The OLD instruction increments L by 1.

S (Serial)

Register S is a pseudo-register. It can be used as Source or Target of a Transfer instruction.
Reading a deserialised input byte is done by reading register S as source.
Writing an output value for serialisation is done by writing to register S as target.

P (Parallel)

Register P is a pseudo-register. It can be used as Source or Target of a Transfer instruction.
Reading the current 8-bit value on the parallel bus is done by reading register P as source.
Writing an output byte onto the parallel bus is done by writing to register P as target.

R (Result)

It can be used as Source or Target of a Transfer instruction. R received the result of ALU instructions.
R has an associated bias register, which is transparently added or subtracted when reading R.

E (Enable)

It can only by the Source of a Transfer instruction.
This register is used for device selection (SPI "Slave Select", latch/output enable pins etc).

J (JUMP), T (TRUE), F (FALSE), I (Iterate)
These can only be Targets of Transfer instructions.
The semantics of these instructions are discussed above under "Control Flow".

C (CALL)
Like trap, but with a source register. DC and WC are scrounged (not available).

O (Origin register)
During call or trap instructions, the address offset of the next instruction to execute upon return is saved into O. During RET, the return offset is restored from O. After a successful branch instruction, the O register receives the origin byte index of where the jump originated.

A, B, R (Accumulator Registers)
The ALU functions IDA (=A) and IDB (=B) as well as corresponding GET-PUT instructions can be used to read A and B.
The values in these registers are the implied arguments for ALU function instructions. Writing a new value into A, B or R copies the previous value into the cache register associated with the respective register. The instructions REA, REB and RER copy the previous value back into the corresponding register. 

Communication

The controller has a communication system for interfacing to serial/parallel devices.

Communication Registers

E

An 8-bit write-only device select register E (Enable). The bit pattern stored in this register is intended to be used for enabling/disabling devices attached to the serial/parallel buses. Writing a device select pattern is done by transferring values into E.

In the reference implementation, the device select byte logically consists of two four-bit halves (nybbles). Each nybble selects one of 16 enable signals via an attached 4-bit decoder. For instance, the lower nybble could generate an enable signal for an input (listening) device on the bus, while the higher nybble could generate a similar signal that enables the transmitting output device required for a particular data bus transfer.

By convention, the value 1 selects a null device (not connected), or some initialisation logic, since both nybbles of the D register will typically be zero (4-to-16 decoding to 1) upon power-up or reset.

SOR (Serial Output Register)

A write-only parallel-to-serial shift register for serialising an output byte.
Writing an output value for serialisation is done by writing to register S.

SIR (Serial Input Register)

A read-only serial-to-parallel shift register for deserialising an input byte.
Reading a deserialised input byte is done by reading register S.

POR (Parallel Output Register)

A write-only tri-state register with 8-bit parallel output.
Writing an output byte onto the parallel bus is done by writing to register P. If the parallel bus is in tri-state mode (HIZ instruction), a write-operation will end tri-state mode.

PIR (Parallel Input Register)

A read-only 8-bit parallel input register.
Reading the current 8-bit value on the parallel bus is done by reading register P.

Communication Instructions

The following Signal instructions operate on the communication registers:

SSI (Shift Serial In): Shift in one bit from serial data input line into SIR (at LSB position)

SSO (Shift Serial Out): Shift out one bit from SOR onto serial data output line (from MSB position)

SCL: Set serial clock line high

SCH: Set serial clock line low

RDY: Put POR into tristate mode (writing to SOR deactivates tristate mode, reading from SIR is equivalent to RDY).

Serial IO and implementing SPI

The Serial Peripheral Interface (SPI) protocol can be implemented using the device select register E, serial register S, and instructions SCL, SCH, SSI, and SSO.

Device Selection: Before communicating with a specific device connected to the serial bus, the corresponding bit pattern representing the device must be set in the E register.

Data Transmission: To transmit data to the selected device, the processor loads the data to be sent into a SOR register.
The SSO (Serial Shift Out) instruction is then executed repeatedly, which clocks the serial output shift register. As each bit is shifted out, it is sent to the selected device through the serial bus.

Device Deselection: After data transmission is complete, the selected device needs to be deselected to allow other devices to communicate on the bus. This is done by clearing the bit pattern corresponding to the device in the D register.

Data Reception: To receive data from an external device, the SSI (Serial Shift In) instruction is used. It clocks the serial input shift register, allowing the processor to receive one bit of data at a time from the selected device. The received data can then be read from the S register.

CPOL (Clock Polarity): The CPOL parameter determines the idle state of the clock signal.
In Sonne, the SCL (Serial Clock Low) and SCH (Serial Clock High) instructions can be used to control the clock signal's state. To configure CPOL=0 (clock idles low), execute SCL to set the clock signal low during the idle state. To configure CPOL=1 (clock idles high), execute SCH to set the clock signal high during the idle state.

CPHA (Clock Phase): The CPHA parameter determines the edge of the clock signal where data is captured or changed. In Sonne, the SSI (Serial shift in) and SSO (Serial shift out) instructions can be used to control data transfer on each clock transition. To configure CPHA=0 (data captured on the leading edge), execute SSI before the clock transition to capture the incoming data. To configure CPHA=1 (data captured on the trailing edge), execute SSI after the clock transition to capture the incoming data. Similarly, to transmit data on the leading or trailing edge, execute SSO before or after the clock transition, respectively.

Assembler syntax

Comments are introduced by a semicolon (";"). Everything on the same line after the semicolon is ignored.

Commas ("," and ".") can be used for grouping "phrases" of instructions that logically belong together. They don't generate code and are just for visual clarity.

The assembler directive CLOSE "closes" the current page for object code placement. Subsequent code is placed from offset zero of the following page.

Number Literals

Decimal numbers from 0-255 can be included the source text as literals, and be prefixed by an optional minus sign. Hexadecimal numbers must be in two uppercase digits and marked with the suffix "h", for instance: "80h" for 128. Binary numbers must be formatted as two 4-bit groups separated by an underscore ("_") and have the suffix "b", for instance: "0010_0000b" for 32.

Page Labels

Page labels are alphanumeric identifiers, preceded with an at-sign ("@xyz"). Page labels mark the beginning of pages (offset=0), and only one page label is allowed per page. Only page labels can be targets of CALL and TRAP instructions.

Offset Labels

Offset labels are identifiers *ending* with an at-sign ("xyz@"). Offset labels can be targets of xJ, xI, xT, xF instructions, or be used to reference data locations within a page.

Asterisk

An asterisk placed before a page label encodes a trap call to that address.
Such label references will generate an opcode that will trigger a TRAP and call the handler function referenced by the label.

Label References

Bank and offset labels are referenced by prefixing their identifier with "<" (for backward references, i.e. the label is defined earlier in the source code than the reference to it), or with ">" (forward reference, i.e. the label is defined later than the reference to it in the source code). If a label is not unique, the reference goes to the nearest occurrence of it.
A label reference is just a numerical value and can be used as such, too.

Instruction Mnemonics

Mnemonics for transfer pair instructions are two-letter uppercase words such as "RA" (take R into A). Mnemonics of the form ("Nx") for transferring a literal embedded in the code stream into a target register, must be followed by that number, reference or other value to be transferred. Example: "na 80h" transfers the number 128 into register A.

GET-PUT Mnemonics

Get operation: Precede the lower case target register name by the upper case Get-Put location, like so: G3a (get A register from location G3).
Put operation: Precede the upper case Get-Put location with the lower case source register name, like so: rG0 (put R register into location G3).

R-Adjustment Mnemonics

P2 is the mnemonic for the opcode that adds 1 to R. M1 is the mnemonic for the opcode that subtracts 1 from R.

Instructions of type Nx (fetch literal value and place in register) have an alternative syntax:
9A place 9 into A, generates NA 9
<LABEL:J generates NJ <LABEL
33hR and 33h:R both generate NR 33h

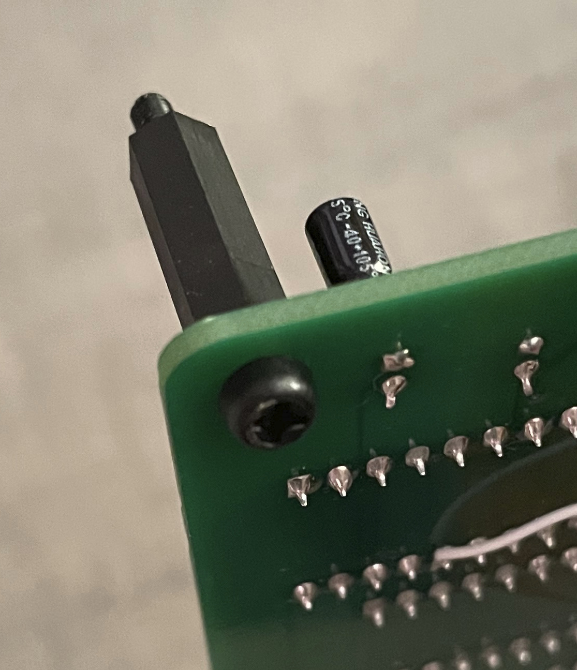
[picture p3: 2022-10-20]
Prototype/board_screws.jpg

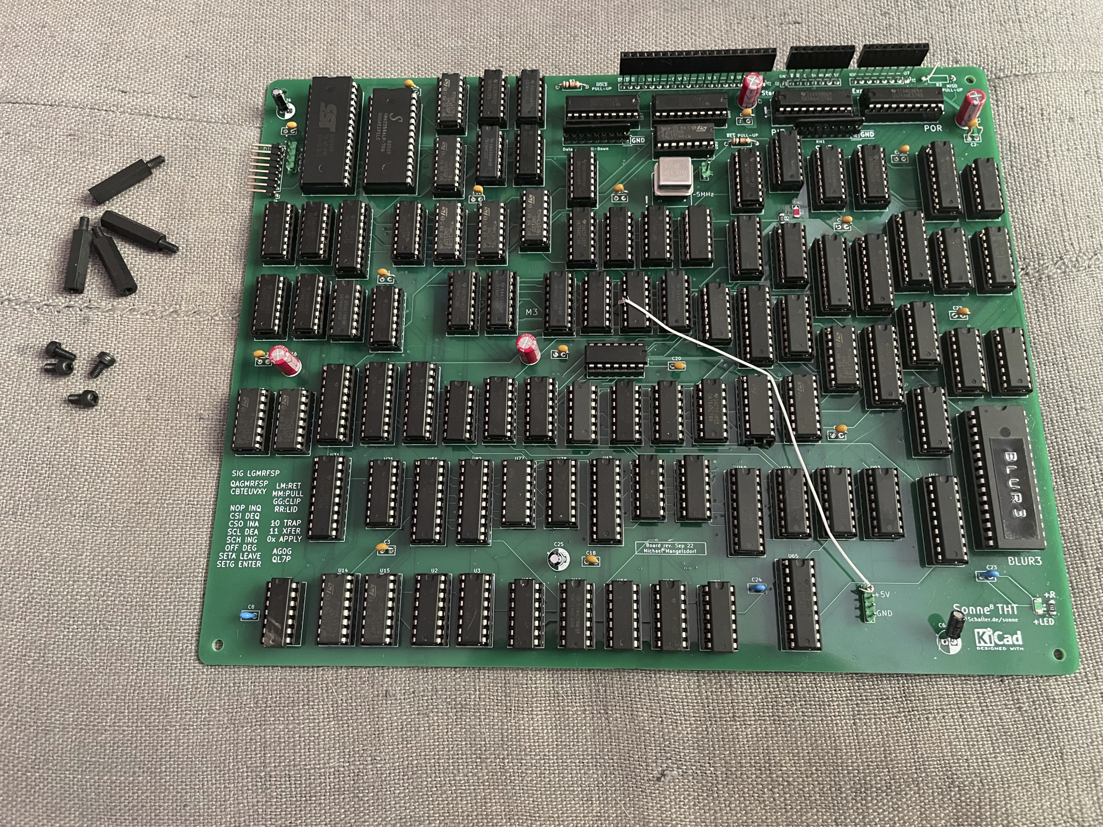
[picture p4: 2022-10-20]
Prototype/board_and_screws.jpg

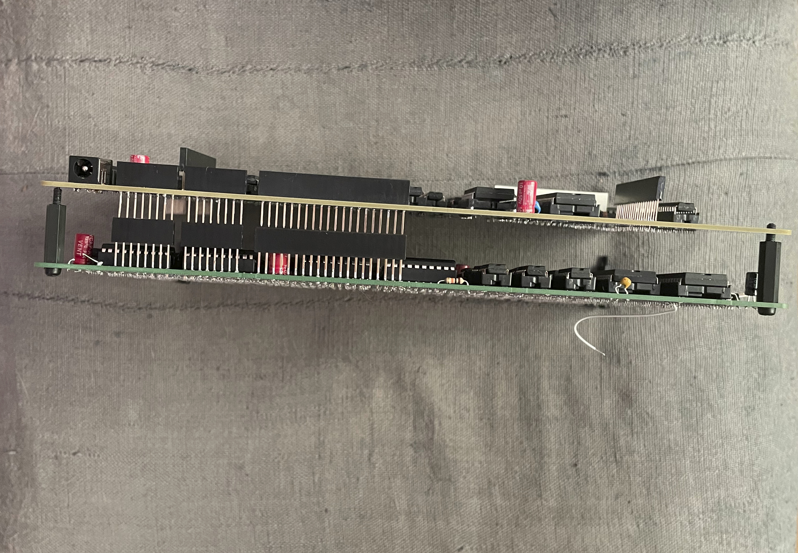
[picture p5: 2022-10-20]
Prototype/board_sandwich.jpg

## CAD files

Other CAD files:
Prototype/blur3.obj

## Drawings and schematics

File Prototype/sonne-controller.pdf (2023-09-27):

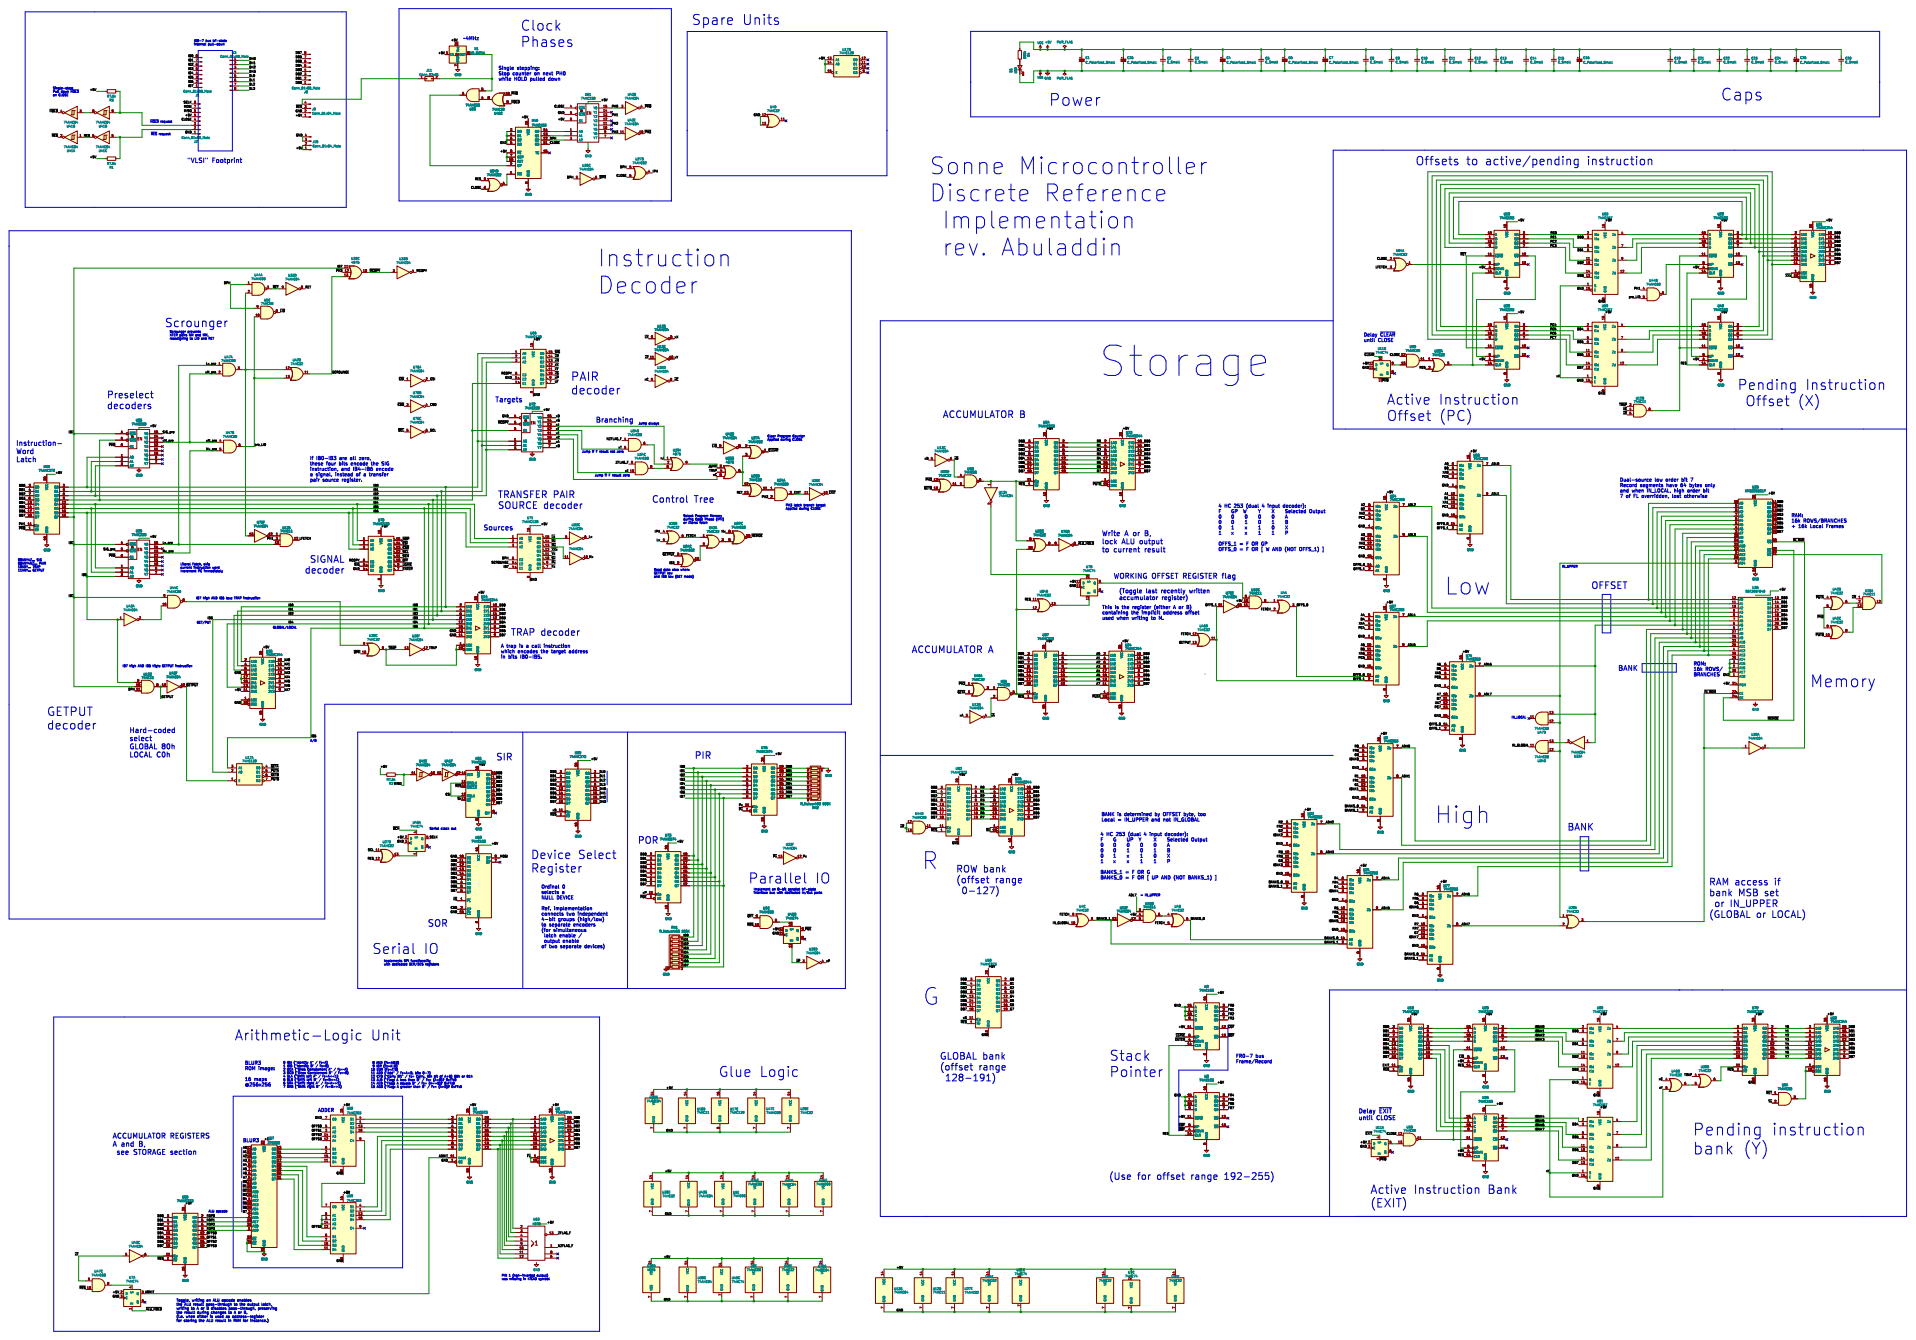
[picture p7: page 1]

Single stepping:
Stop counter on next PH0
while HOLD pulled down

Single-step: Pull down ~{HOLD} on CLOSE
+5V RES

Jump if F result not zero

these four bits encode the SIG

a signal, instead of a transfer
pair source register.

Record segments have 64 bytes only
and when IN_LOCAL, high order bit
9 GND GND GND

used when writing to M. 00ANY4Z... SIG
00ANY4NZ... PAIR
10ANY... TRAP

Read data also when: GETPUT low

WORKING OFFSET REGISTER flag

and IB3 low (GET mode)

(Toggle last recently written

This is the register (either A or B)

A trap is a call instruction
which encodes the target address
in bits IB0-IB5.

BANKS_1 = F OR G
BANKS_0 = F OR [ UP AND (NOT BANKS_1) ]

(for simultaneous
latch enable /
output enable
of two separate devices)

8 AND (F:=A&B) 9 IOR (F:=A|B) 10 EOR (F:=A^B) 11 ADD ("Add" / F:=A+B, bits 0-7) 12 CYB ("Carry Bit" / F:= Carry, 9th bit of A+B) 00h or 01h

13 ALB ("Flag: A less than B" / F:= (A<B)? 0xFF:0
15 AGB ("Flag: A greater than B" / F:= (A>B)? 0xFF:0

(Use for offset range 192-255)

Toggle, writing an ALU opcode enables
the result during changes to A or B,
(i.e. when either is used as address-register
for storing the ALU result in RAM for instance.)

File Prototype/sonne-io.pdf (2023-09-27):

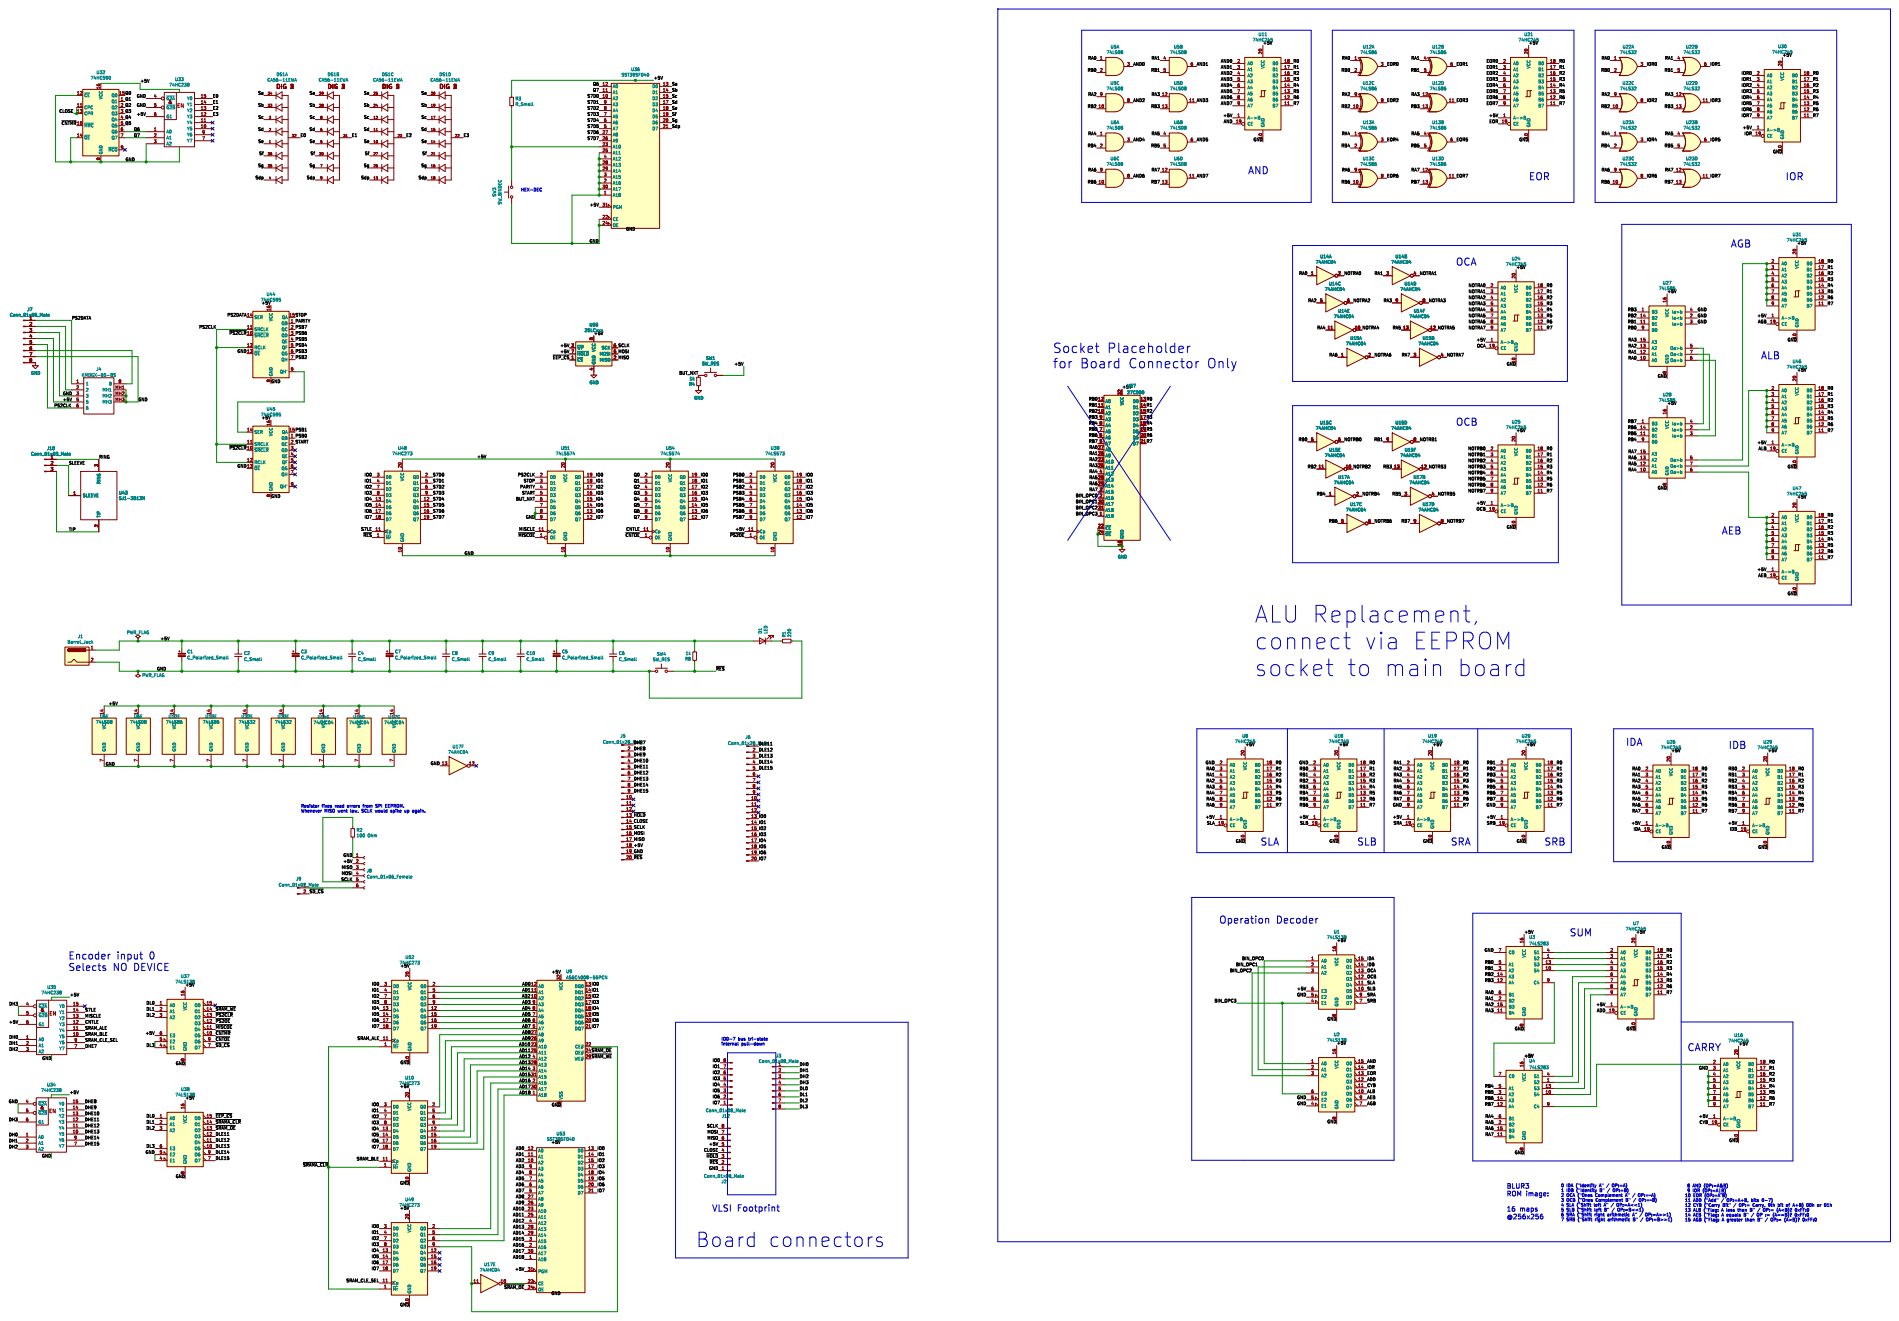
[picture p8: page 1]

SeSc SdSf E0 SgSf Sdp

4 MOSI 5 SCK 6 ~{HOLD} 7 VCC

ALU Replacement,
connect via EEPROM
socket to main board

Resistor fixes read errors from SPI EEPROM. Whenever MISO went low, SCLK would spike up again.

8 AND (OP:=A&B) 9 IOR (OP:=A|B) 10 EOR (OP:=A^B) 11 ADD ("Add" / OP:=A+B, bits 0-7) 12 CYB ("Carry Bit" / OP:= Carry, 9th bit of A+B) 00h or 01h

13 ALB ("Flag: A less than B" / OP:= (A<B)? 0xFF:0
15 AGB ("Flag: A greater than B" / OP:= (A>B)? 0xFF:0

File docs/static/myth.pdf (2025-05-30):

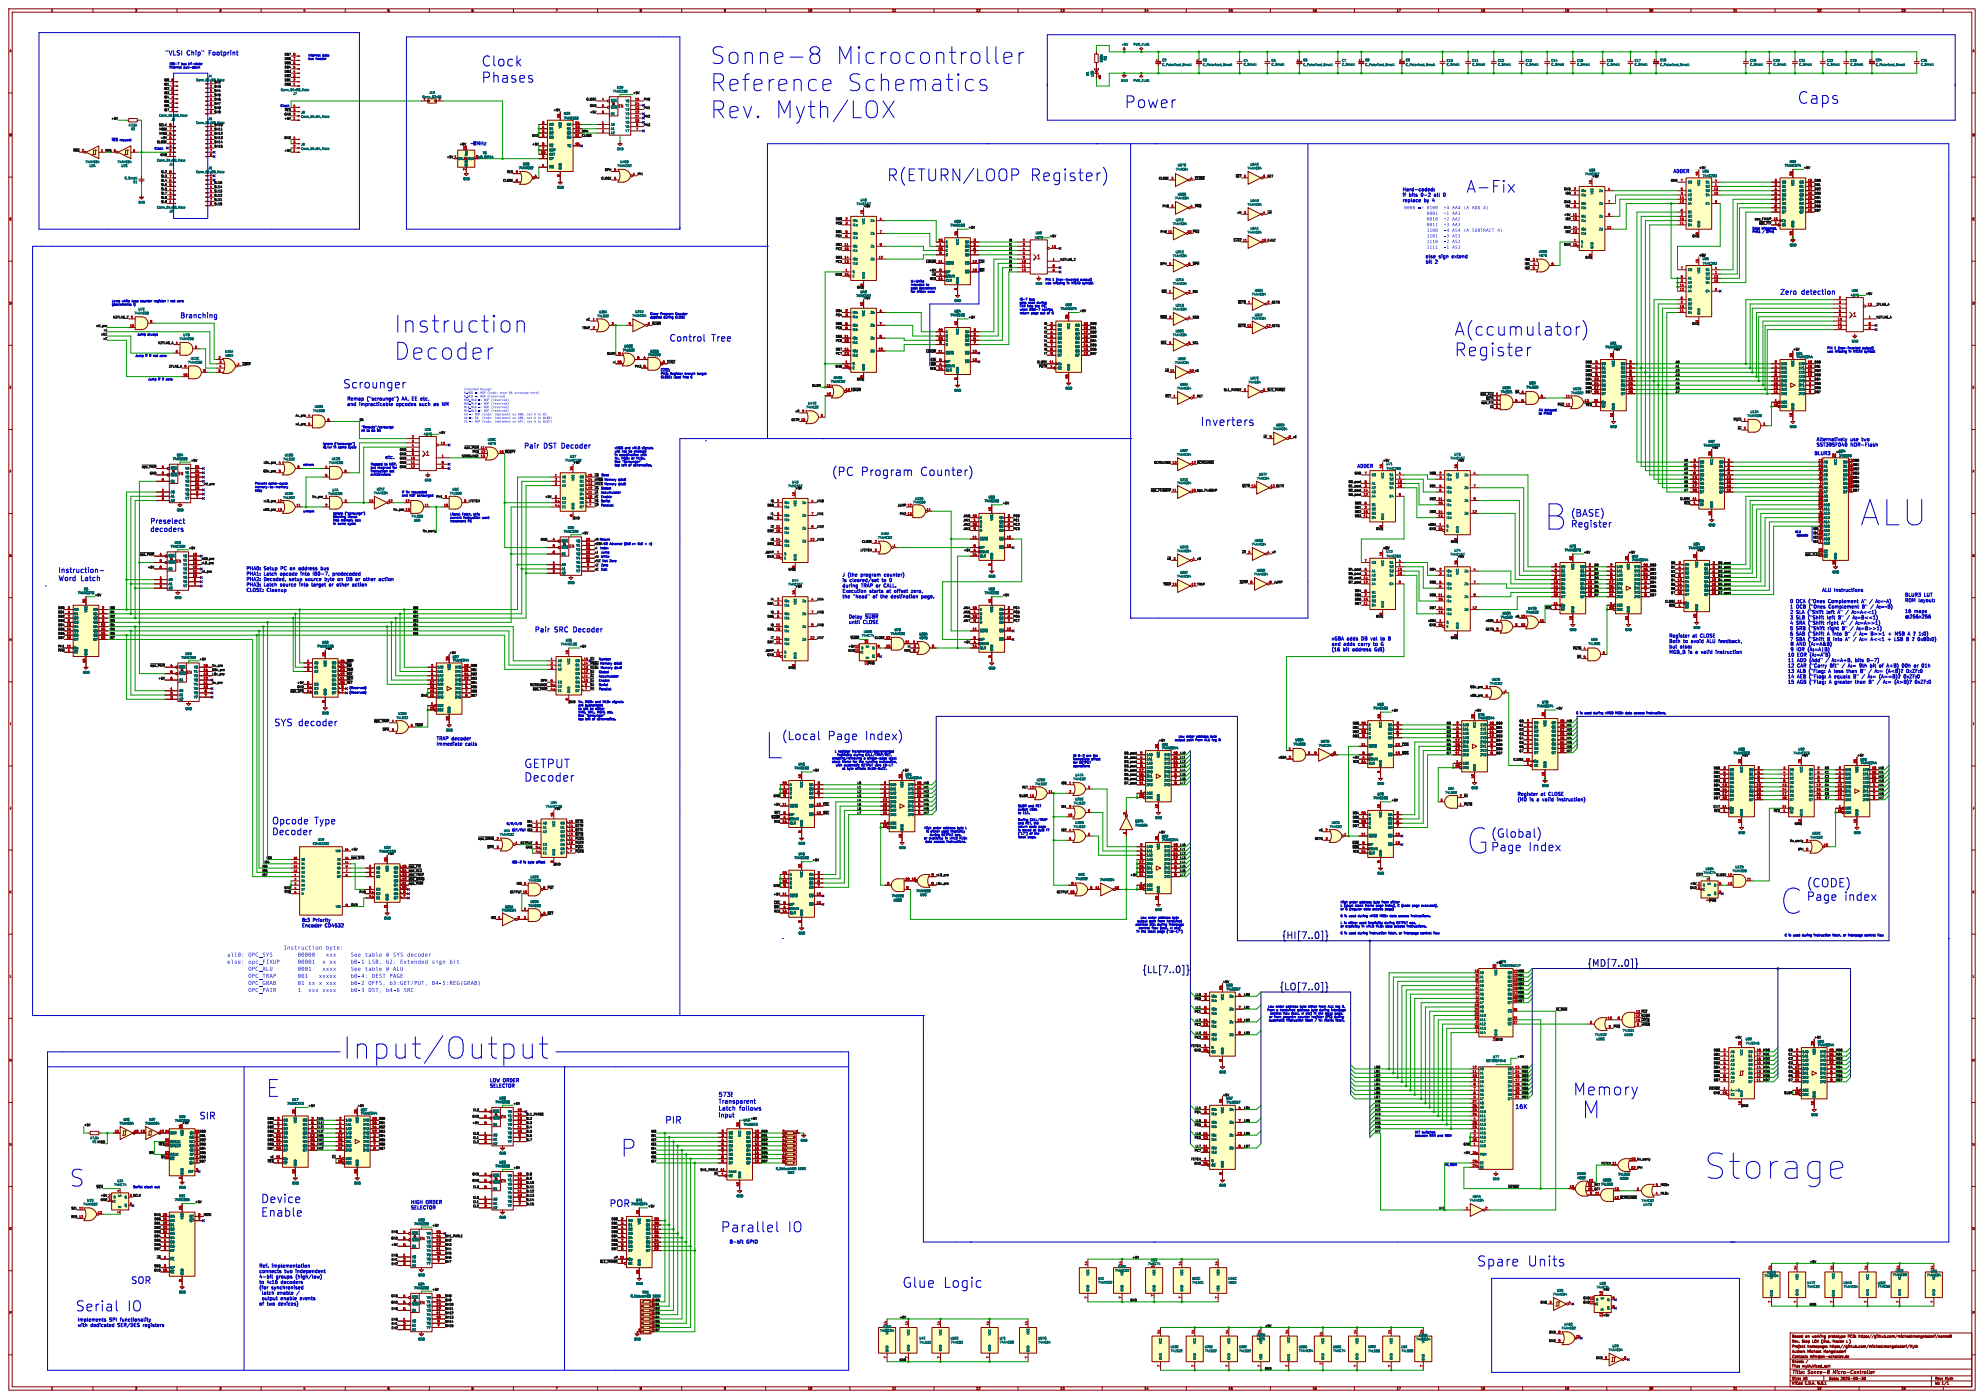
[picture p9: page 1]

7 ~{CO}12 ~{BO}13 GND GND

Clear Program Counter applied during CLOSE PHA0: Setup PC on address bus

return page out of G SYS decoder

Jump if R not zero

~{ExNZ}: PH3: Register branch target CLOSE: Load into C

"Reroute"/scrounge AA to do BA Scrounger

xMGB and xMLB signals will not be enabled
74AHC138

Mapped to NOP, but reserved for

top left of schematics.
Serial Base
Memory @G:B
Jump Return GB Advance (G:B := G:B + n) Accumulator Memory @L:B

PHA2: Decoded, setup source byte on DB or other action
PHA3: Latch source into target or other action
CLOSE: Cleanup

during TRAP or CALL.
Execution starts at offset zero,

5 SRB ("Shift right B" / A:=B>>1)
6 SAB ("Shift A into B" / A:= B>>1 + MSB A ? 1:0)

Register at CLOSE
Both to avoid ALU feedback,
but also:
MGB_B is a valid instruction

and adds carry to G
(16 bit address G:B)

8 AND (A:=A&B)
9 IOR (A:=A|B)
10 EOR (A:=A^B)
11 ADD (Add" / A:=A+B, bits 0-7)
12 CAR ("Carry Bit" / A:= 9th bit of A+B) 00h or 01h
13 ALB ("Flag: A less than B" / A:= (A<B)? 0xZF:0
15 AGB ("Flag: A greater than B" / A:= (A>B)? 0xZF:0

Accumulator Parallel Nx, MGBx and MLBx signals are guaranteed

to not be either NMG, NML, MGML etc. See "Scrounger"

G is used during xMGB MGBx data access instructions.

at byte offsets 0xZ8-0xZF. (Local Page Index) L

(MD is a valid instruction)

SUBR and RET
switch LSBs
to 111. During CALL/TRAP

and RET, the
return code page
is saved at byte FF
local page.

High order address byte L
is either used implicitly

Low order address byte
output path from hardwired
address bits during interpage
in the local page ("L0-L7")

Low order address byte either from ALU reg B,

74AHC04

HI7 switches between RAM and ROM
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

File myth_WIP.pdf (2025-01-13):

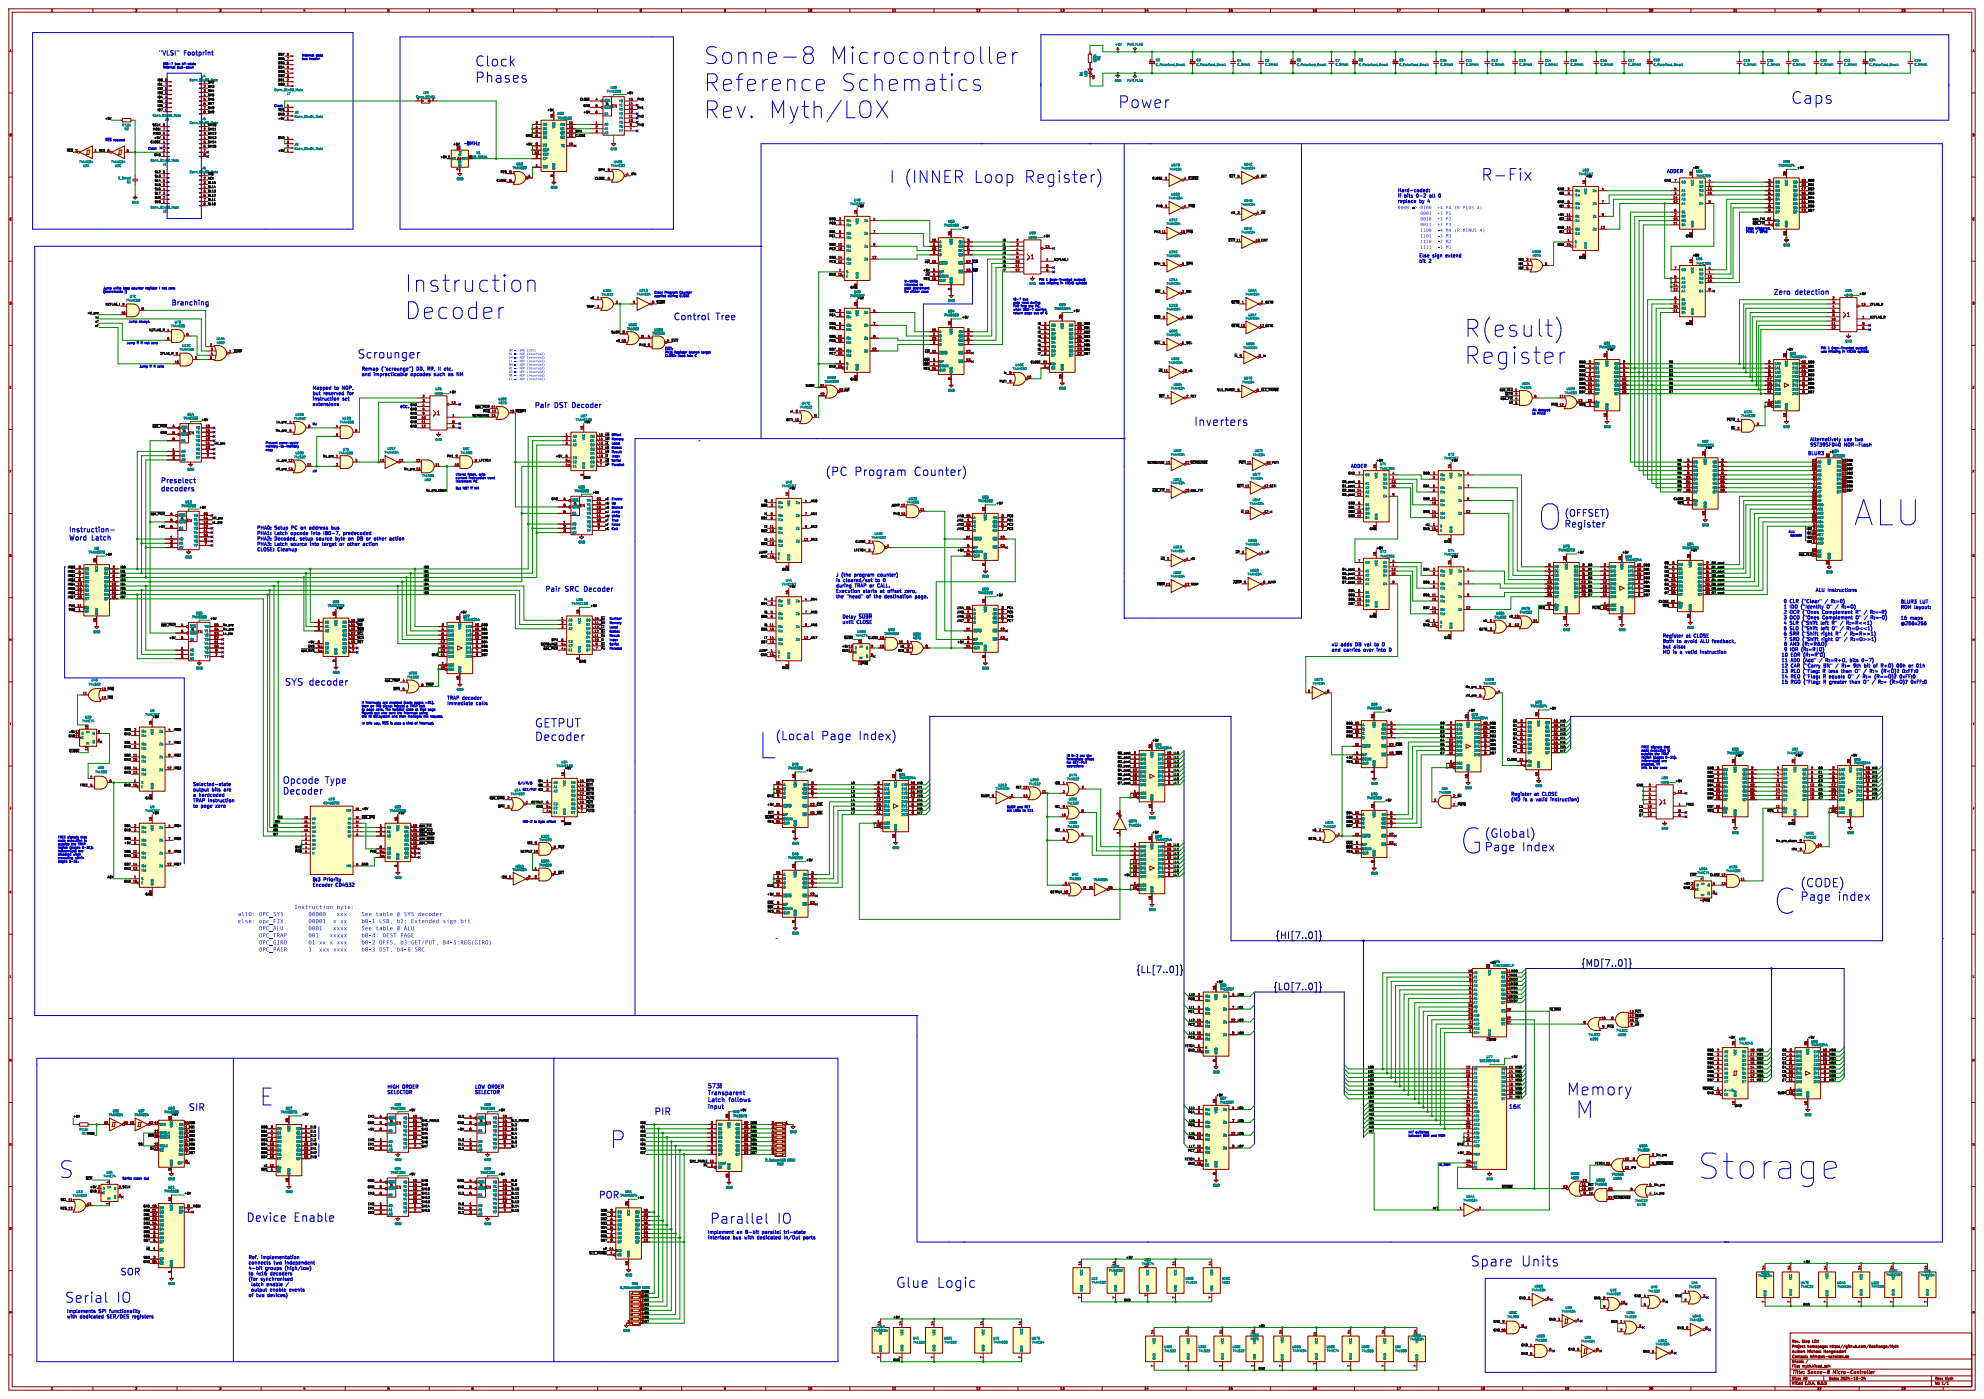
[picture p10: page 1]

ADDER I (INNER Loop Register)

Clear Program Counter applied during CLOSE

return page out of G

NM => END (LOX) NL => NOP (reserved) LM => NOP (reserved) LL => NOP (reserved) MM => NOP (reserved) ML => NOP (reserved) DD => NOP (reserved) RR => NOP (reserved)

Prevent same-cycle memory-to-memory

xM PHA0: Setup PC on address bus

But NOT if NM

Call False TRAP decoder

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

during TRAP or CALL.

Memory Local Number Pair SRC Decoder

Execution starts at offset zero,

Register at CLOSE
Both to avoid ALU feedback,
but also:

xU adds DB val to O
and carries over into D

MO is a valid instruction

9 IOR (R:=R|O)
10 EOR (R:=R^O)
11 ADD (Add" / R:=R+O, bits 0-7)
12 CAR ("Carry Bit" / R:= 9th bit of R+O) 00h or 01h
13 RLO ("Flag: R less than O" / R:= (R<O)? 0xFF:0
15 RGO ("Flag: R greater than O" / R:= (R>O)? 0xFF:0

then an IRQ signal injects a TRAP call to page zero. The handler code at that page

the IO B2Lsystem and then manages the request.

In this way, ~{RES}is also a kind of interrupt.

region (pages 0-31).
enabled, iff
this is the case

(MD is a valid instruction)

HI7 switches between RAM and ROM
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

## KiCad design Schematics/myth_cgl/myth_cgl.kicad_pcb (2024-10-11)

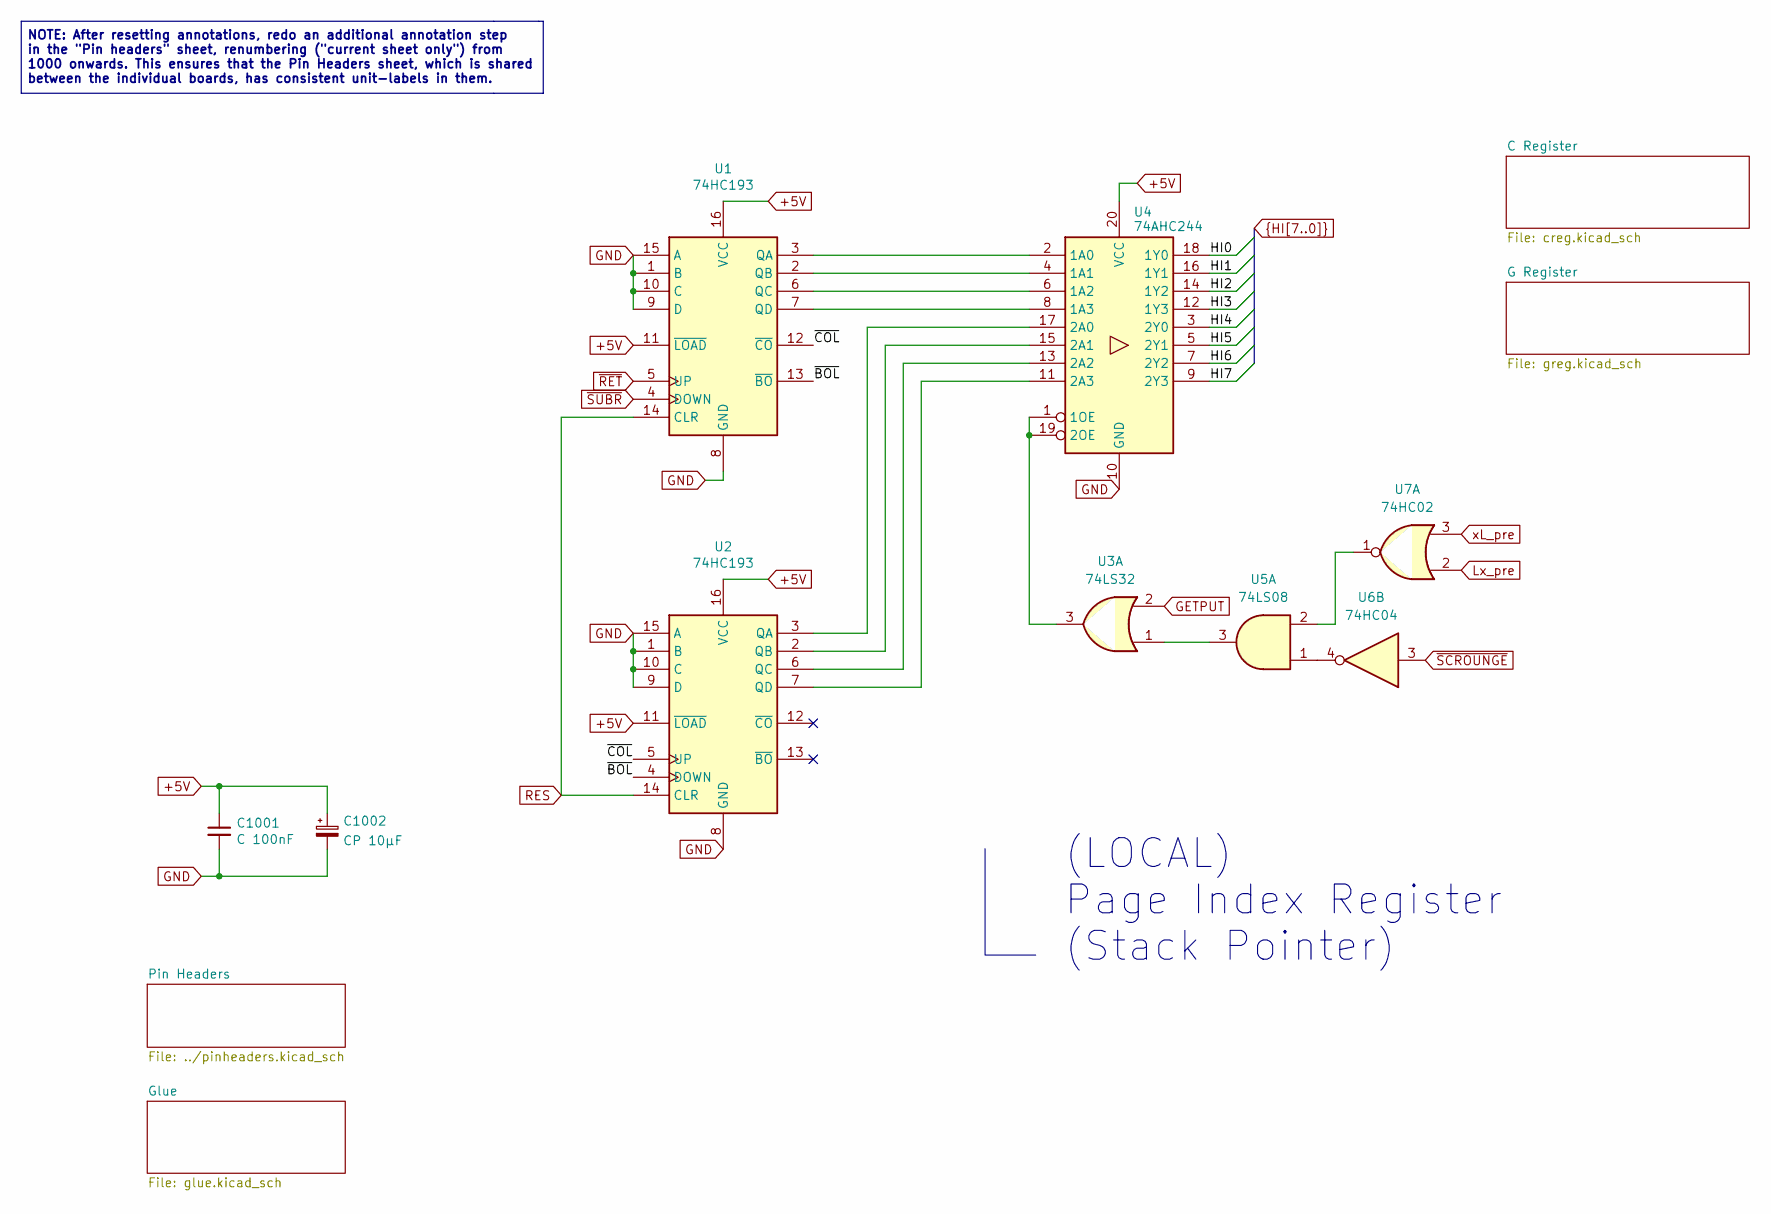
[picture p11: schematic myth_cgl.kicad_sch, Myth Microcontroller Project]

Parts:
C1001: C 100nF; C_Disc_D5.0mm_W2.5mm_P2.50mm
C1002: CP 10μF; CP_Radial_D6.3mm_P2.50mm
U1, U2: 74HC193; DIP-16_W7.62mm_Socket_LongPads
U3: 74LS32; DIP-14_W7.62mm_LongPads
U4: 74AHC244; DIP-20_W7.62mm_Socket_LongPads
U5: 74LS08; DIP-14_W7.62mm_LongPads
U6: 74HC04; DIP-14_W7.62mm_LongPads
U7: 74HC02; DIP-14_W7.62mm_LongPads

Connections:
+5V: C1001.1, C1002.1, U1.11 (~LOAD), U1.16 (VCC), U2.11 (~LOAD), U2.16 (VCC), U4.20 (VCC); also elsewhere on the board
/~BOL: U1.13 (~BO), U2.4 (DOWN)
/~COL: U1.12 (~CO), U2.5 (UP)
GETPUT: U3.2; also elsewhere on the board
HI0: U4.18 (1Y0); also elsewhere on the board
HI1: U4.16 (1Y1); also elsewhere on the board
HI2: U4.14 (1Y2); also elsewhere on the board
HI3: U4.12 (1Y3); also elsewhere on the board
HI4: U4.3 (2Y0); also elsewhere on the board
HI5: U4.5 (2Y1); also elsewhere on the board
HI6: U4.7 (2Y2); also elsewhere on the board
HI7: U4.9 (2Y3); also elsewhere on the board
Lx_pre: U7.2; also elsewhere on the board
unnamed: U1.3 (QA), U4.2 (1A0)
unnamed: U1.2 (QB), U4.4 (1A1)
unnamed: U1.6 (QC), U4.6 (1A2)
unnamed: U1.7 (QD), U4.8 (1A3)
unnamed: U2.3 (QA), U4.17 (2A0)
unnamed: U2.2 (QB), U4.15 (2A1)
unnamed: U2.6 (QC), U4.13 (2A2)
unnamed: U2.7 (QD), U4.11 (2A3)
unnamed: U3.1, U5.3
unnamed: U3.3, U4.1 (1OE), U4.19 (2OE)
unnamed: U5.1, U6.4
unnamed: U5.2, U7.1
RES: U1.14 (CLR), U2.14 (CLR); also elsewhere on the board
xL_pre: U7.3; also elsewhere on the board
~RET: U1.5 (UP); also elsewhere on the board
~SCROUNGE: U6.3
~SUBR: U1.4 (DOWN), U6.2; also elsewhere on the board

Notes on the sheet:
NOTE: After resetting annotations, redo an additional annotation step in the "Pin headers" sheet, renumbering ("current sheet only") from 1000 onwards. This ensures that the Pin Headers sheet, which is shared between the individual boards, has consistent unit-labels in them.
(LOCAL) Page Index Register (Stack Pointer)

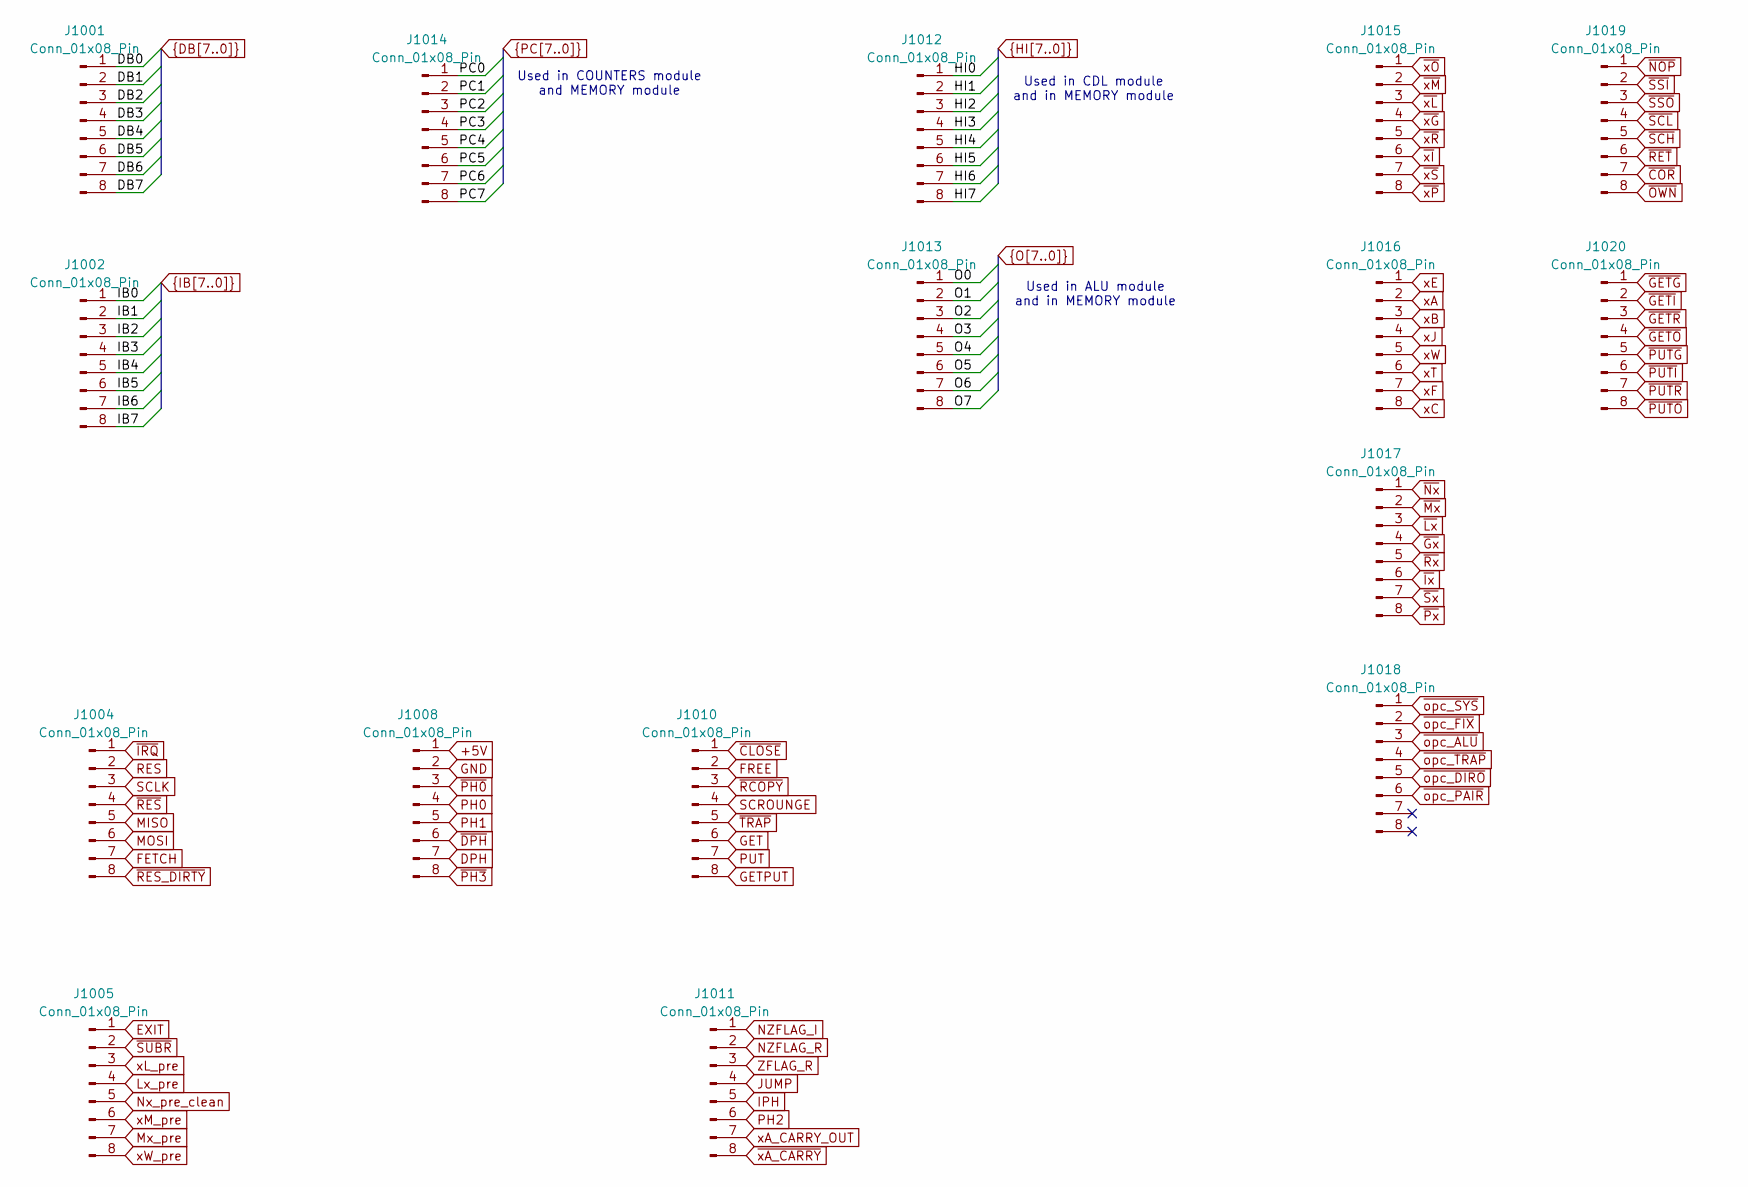
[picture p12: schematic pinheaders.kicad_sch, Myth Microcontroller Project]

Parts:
J1001, J1002, J1004, J1005, J1008, J1010, J1011, J1012, J1013, J1014, J1015, J1016, J1017, J1018, J1019, J1020: Conn_01x08_Pin; PinHeader_1x08_P2.54mm_Vertical

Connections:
+5V: J1008.1; also elsewhere on the board
DB0: J1001.1; also elsewhere on the board
DB1: J1001.2; also elsewhere on the board
DB2: J1001.3; also elsewhere on the board
DB3: J1001.4; also elsewhere on the board
DB4: J1001.5; also elsewhere on the board
DB5: J1001.6; also elsewhere on the board
DB6: J1001.7; also elsewhere on the board
DB7: J1001.8; also elsewhere on the board
DPH: J1008.7
EXIT: J1005.1; also elsewhere on the board
FETCH: J1004.7
FREE: J1010.2; also elsewhere on the board
GET: J1010.6
GETPUT: J1010.8; also elsewhere on the board
HI0: J1012.1; also elsewhere on the board
HI1: J1012.2; also elsewhere on the board
HI2: J1012.3; also elsewhere on the board
HI3: J1012.4; also elsewhere on the board
HI4: J1012.5; also elsewhere on the board
HI5: J1012.6; also elsewhere on the board
HI6: J1012.7; also elsewhere on the board
HI7: J1012.8; also elsewhere on the board
IB0: J1002.1
IB1: J1002.2
IB2: J1002.3
IB3: J1002.4
IB4: J1002.5
IB5: J1002.6
IB6: J1002.7
IB7: J1002.8
IPH: J1011.5; also elsewhere on the board
JUMP: J1011.4
Lx_pre: J1005.4; also elsewhere on the board
MISO: J1004.5
MOSI: J1004.6
Mx_pre: J1005.7; also elsewhere on the board
NZFLAG_I: J1011.1
NZFLAG_R: J1011.2
Nx_pre_clean: J1005.5; also elsewhere on the board
O0: J1013.1
O1: J1013.2
O2: J1013.3
O3: J1013.4
O4: J1013.5
O5: J1013.6
O6: J1013.7
O7: J1013.8
PC0: J1014.1
PC1: J1014.2
PC2: J1014.3
PC3: J1014.4
PC4: J1014.5
PC5: J1014.6
PC6: J1014.7
PC7: J1014.8
PH0: J1008.4
PH1: J1008.5
PH2: J1011.6
PUT: J1010.7
RES: J1004.2; also elsewhere on the board
SCLK: J1004.3
SCROUNGE: J1010.4
ZFLAG_R: J1011.3
xA: J1016.2
xA_CARRY_OUT: J1011.7
xB: J1016.3
xC: J1016.8; also elsewhere on the board
xE: J1016.1
xF: J1016.7
xJ: J1016.4
xL_pre: J1005.3; also elsewhere on the board
xM_pre: J1005.6; also elsewhere on the board
xT: J1016.6
xW: J1016.5
xW_pre: J1005.8
~CLOSE: J1010.1
~COR: J1019.7; also elsewhere on the board
~DPH: J1008.6
~Dx: J1017.4; also elsewhere on the board
~GETD: J1020.1
~GETI: J1020.2
~GETO: J1020.4
~GETR: J1020.3
~IRQ: J1004.1
~Ix: J1017.6
~Lx: J1017.3
~Mx: J1017.2
~NOP: J1019.1
~Nx: J1017.1
~OWN: J1019.8; also elsewhere on the board
~PH0: J1008.3; also elsewhere on the board
~PH3: J1008.8
~PUTD: J1020.5; also elsewhere on the board
~PUTI: J1020.6
~PUTO: J1020.8
~PUTR: J1020.7
~Px: J1017.8
~RCOPY: J1010.3
~RES_DIRTY: J1004.8
~RES: J1004.4; also elsewhere on the board
~RET: J1019.6; also elsewhere on the board
~Rx: J1017.5
~SCH: J1019.5
~SCL: J1019.4
~SSI: J1019.2
~SSO: J1019.3
~SUBR: J1005.2; also elsewhere on the board
~Sx: J1017.7
~TRAP: J1010.5
~opc_ALU: J1018.3
~opc_DIRO: J1018.5
~opc_FIX: J1018.2
~opc_PAIR: J1018.6
~opc_SYS: J1018.1
~opc_TRAP: J1018.4
~xA_CARRY: J1011.8; also elsewhere on the board
~xD: J1015.4
~xI: J1015.6
~xL: J1015.3
~xM: J1015.2
~xO: J1015.1
~xP: J1015.8
~xR: J1015.5
~xS: J1015.7

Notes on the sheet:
Used in COUNTERS module and MEMORY module
Used in CDL module and in MEMORY module
Used in ALU module and in MEMORY module

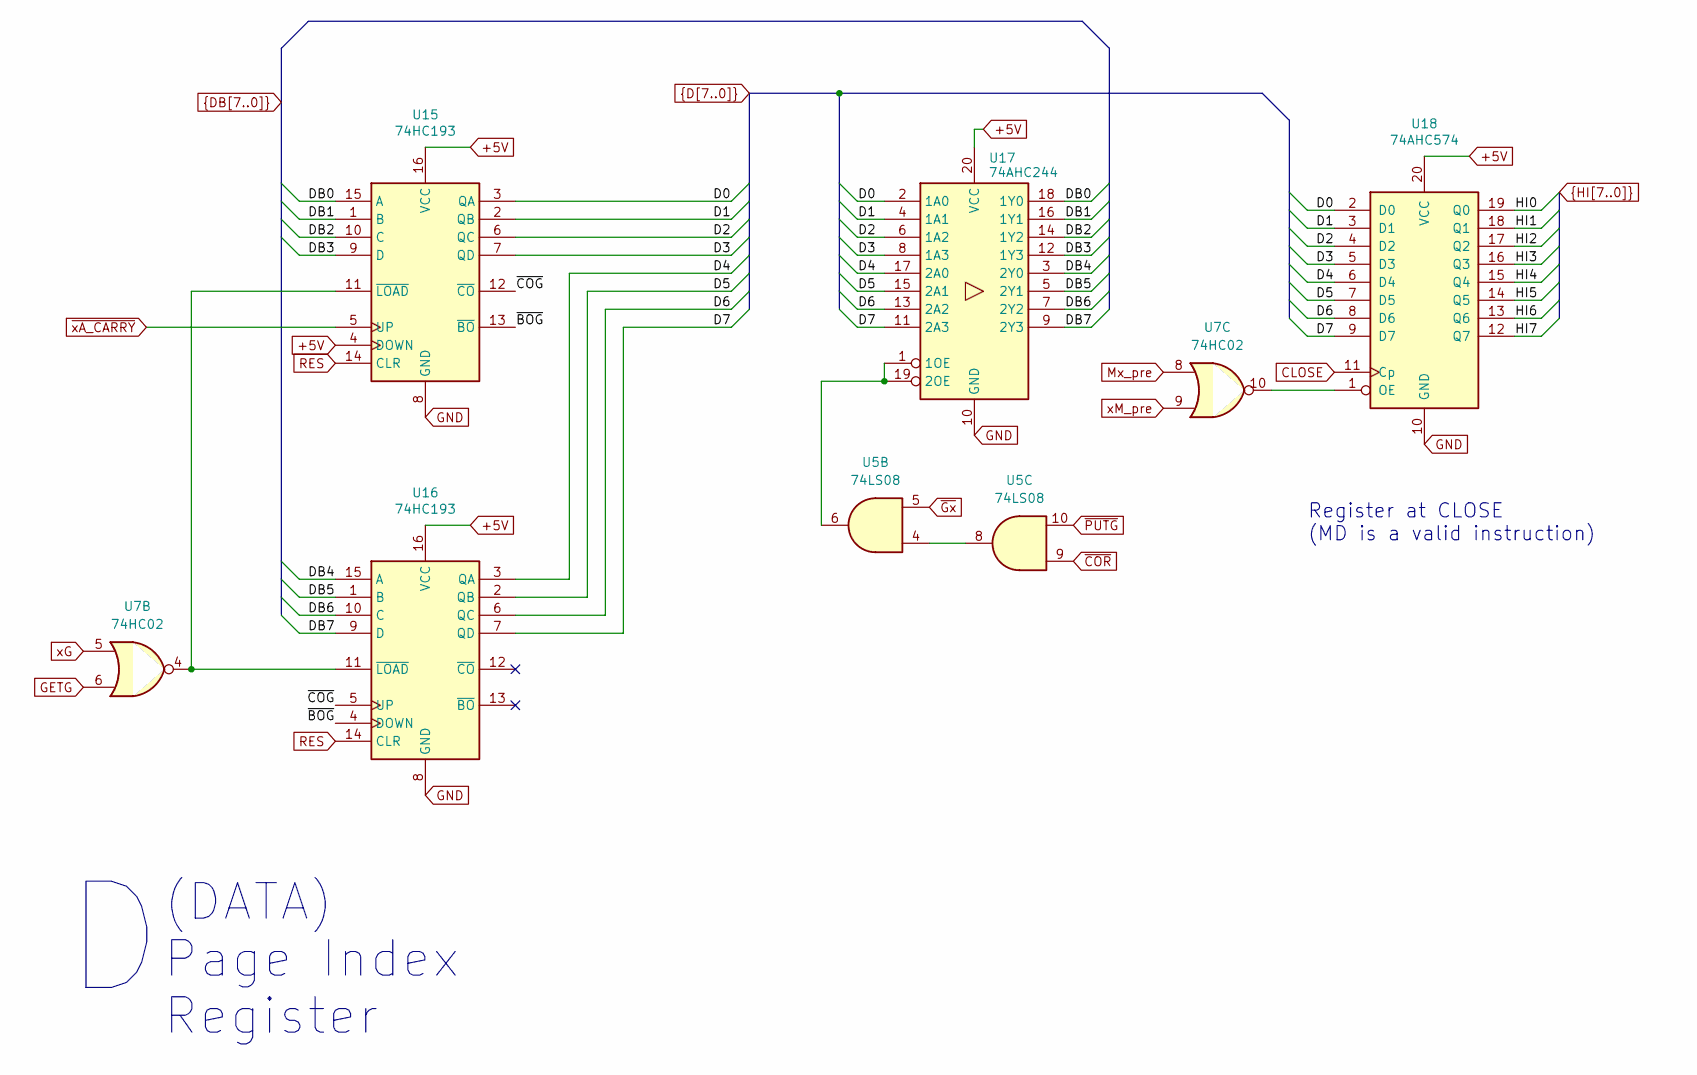
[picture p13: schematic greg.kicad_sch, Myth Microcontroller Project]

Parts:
U5: 74LS08; DIP-14_W7.62mm_LongPads
U7: 74HC02; DIP-14_W7.62mm_LongPads
U15, U16: 74HC193; DIP-16_W7.62mm_Socket_LongPads
U17: 74AHC244; DIP-20_W7.62mm_Socket_LongPads
U18: 74AHC574; DIP-20_W7.62mm_Socket_LongPads

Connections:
+5V: U15.4 (DOWN), U15.16 (VCC), U16.16 (VCC), U17.20 (VCC), U18.20 (VCC); also elsewhere on the board
/D Register/~BOD: U15.13 (~BO), U16.4 (DOWN)
/D Register/~COD: U15.12 (~CO), U16.5 (UP)
CLOSE: U18.11 (Cp); also elsewhere on the board
D0: U15.3 (QA), U17.2 (1A0), U18.2 (D0)
D1: U15.2 (QB), U17.4 (1A1), U18.3 (D1)
D2: U15.6 (QC), U17.6 (1A2), U18.4 (D2)
D3: U15.7 (QD), U17.8 (1A3), U18.5 (D3)
D4: U16.3 (QA), U17.17 (2A0), U18.6 (D4)
D5: U16.2 (QB), U17.15 (2A1), U18.7 (D5)
D6: U16.6 (QC), U17.13 (2A2), U18.8 (D6)
D7: U16.7 (QD), U17.11 (2A3), U18.9 (D7)
DB0: U15.15 (A), U17.18 (1Y0); also elsewhere on the board
DB1: U15.1 (B), U17.16 (1Y1); also elsewhere on the board
DB2: U15.10 (C), U17.14 (1Y2); also elsewhere on the board
DB3: U15.9 (D), U17.12 (1Y3); also elsewhere on the board
DB4: U16.15 (A), U17.3 (2Y0); also elsewhere on the board
DB5: U16.1 (B), U17.5 (2Y1); also elsewhere on the board
DB6: U16.10 (C), U17.7 (2Y2); also elsewhere on the board
DB7: U16.9 (D), U17.9 (2Y3); also elsewhere on the board
GETD: U7.6
HI0: U18.19 (Q0); also elsewhere on the board
HI1: U18.18 (Q1); also elsewhere on the board
HI2: U18.17 (Q2); also elsewhere on the board
HI3: U18.16 (Q3); also elsewhere on the board
HI4: U18.15 (Q4); also elsewhere on the board
HI5: U18.14 (Q5); also elsewhere on the board
HI6: U18.13 (Q6); also elsewhere on the board
HI7: U18.12 (Q7); also elsewhere on the board
Mx_pre: U7.8; also elsewhere on the board
unnamed: U5.4, U5.8
unnamed: U7.4, U15.11 (~LOAD), U16.11 (~LOAD)
unnamed: U5.6, U17.1 (1OE), U17.19 (2OE)
unnamed: U7.10, U18.1 (OE)
RES: U15.14 (CLR), U16.14 (CLR); also elsewhere on the board
xD: U7.5
xM_pre: U7.9; also elsewhere on the board
~COR: U5.9; also elsewhere on the board
~Dx: U5.5; also elsewhere on the board
~PUTD: U5.10; also elsewhere on the board
~xA_CARRY: U15.5 (UP); also elsewhere on the board

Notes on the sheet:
(DATA) Page Index Register
Register at CLOSE (MD is a valid instruction)

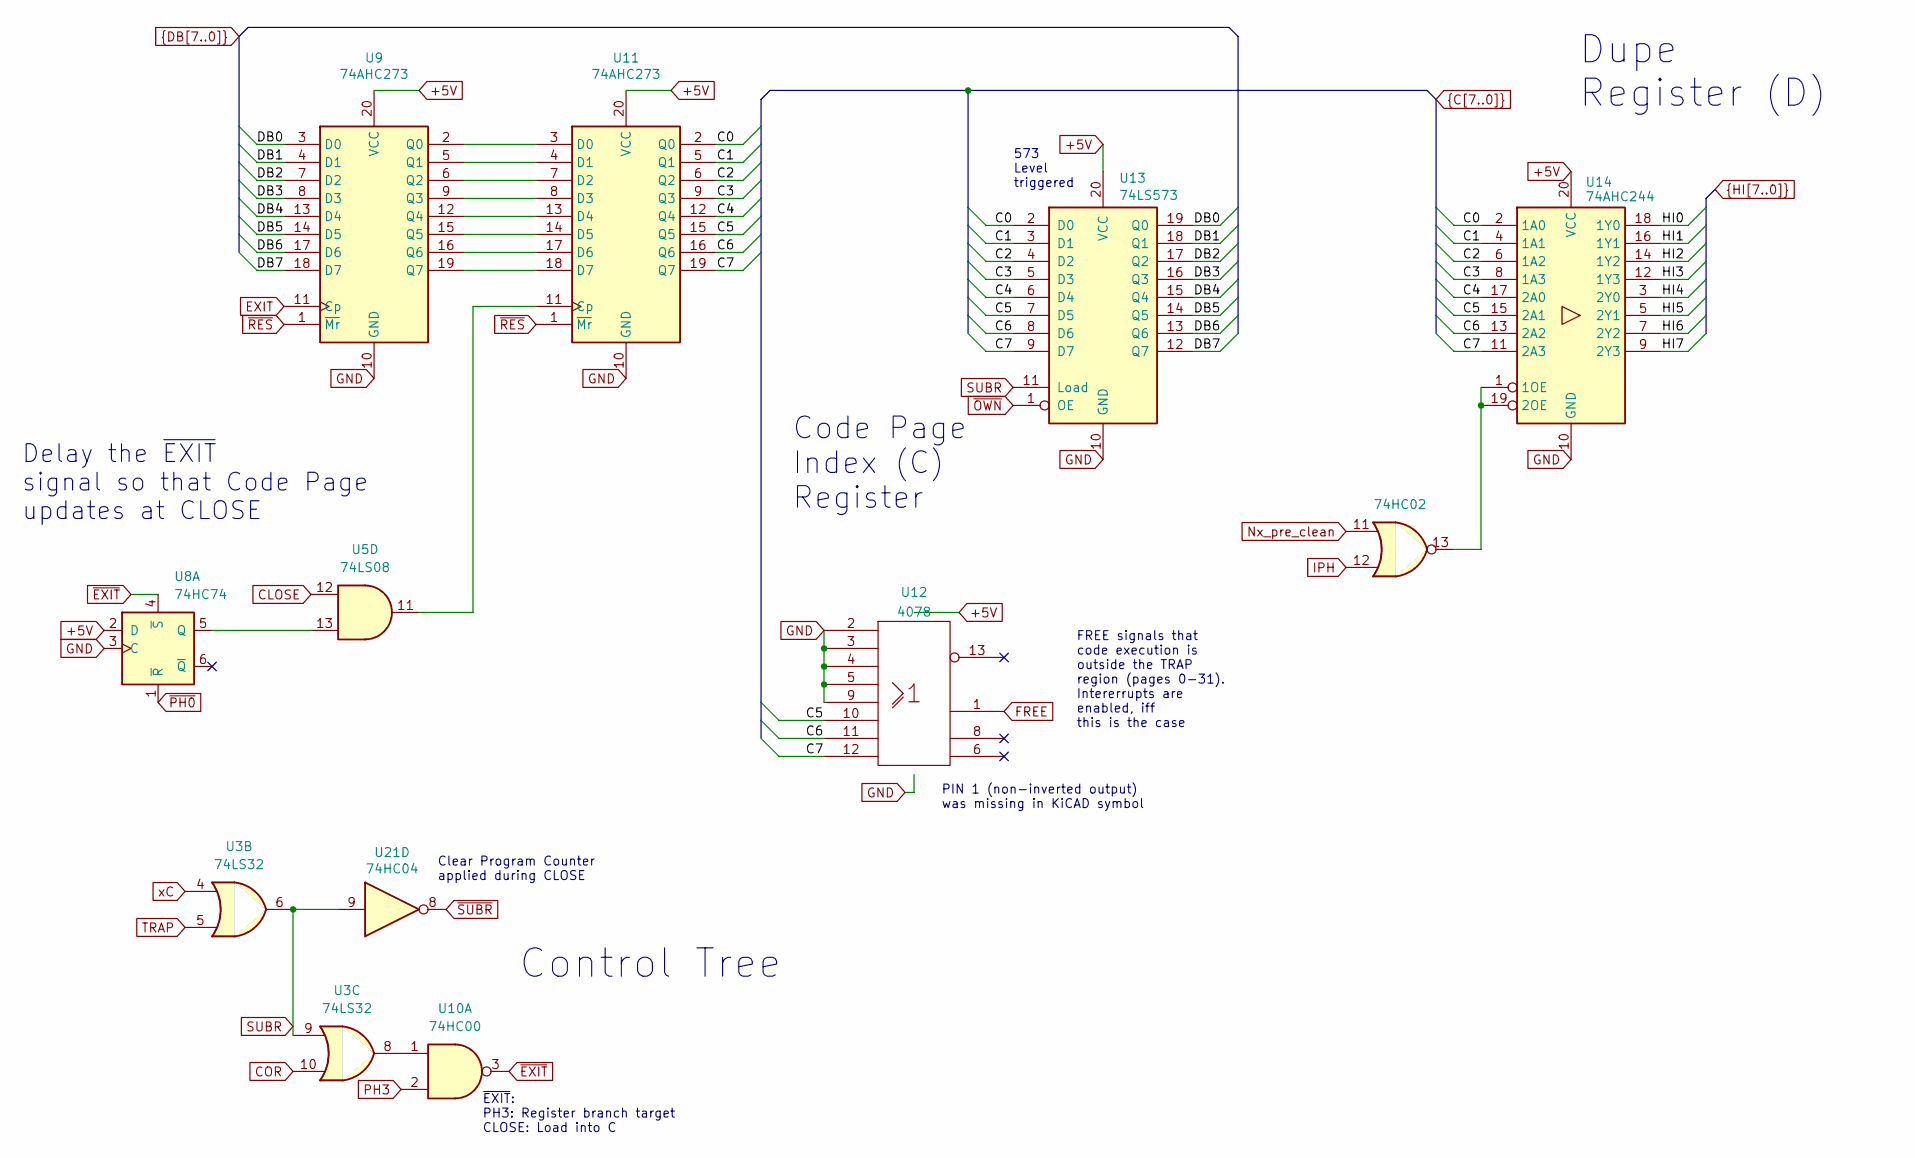
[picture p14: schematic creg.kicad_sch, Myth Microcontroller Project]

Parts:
U3: 74LS32; DIP-14_W7.62mm_LongPads
U5: 74LS08; DIP-14_W7.62mm_LongPads
U7: 74HC02; DIP-14_W7.62mm_LongPads
U8: 74HC74; DIP-14_W7.62mm_LongPads
U9, U11: 74AHC273; DIP-20_W7.62mm_Socket_LongPads
U10: 74HC00; DIP-14_W7.62mm_LongPads
U12: 4078; DIP-14_W7.62mm_Socket_LongPads
U13: 74LS573; DIP-20_W7.62mm_Socket_LongPads
U14: 74AHC244; DIP-20_W7.62mm_Socket_LongPads
U21: 74HC04; DIP-14_W7.62mm_LongPads

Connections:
+5V: U8.2 (D), U9.20 (VCC), U11.20 (VCC), U12.14 (Vdd), U13.20 (VCC), U14.20 (VCC); also elsewhere on the board
C0: U11.2 (Q0), U13.2 (D0), U14.2 (1A0)
C1: U11.5 (Q1), U13.3 (D1), U14.4 (1A1)
C2: U11.6 (Q2), U13.4 (D2), U14.6 (1A2)
C3: U11.9 (Q3), U13.5 (D3), U14.8 (1A3)
C4: U11.12 (Q4), U13.6 (D4), U14.17 (2A0)
C5: U11.15 (Q5), U12.10, U13.7 (D5), U14.15 (2A1)
C6: U11.16 (Q6), U12.11, U13.8 (D6), U14.13 (2A2)
C7: U11.19 (Q7), U12.12, U13.9 (D7), U14.11 (2A3)
CLOSE: U5.12; also elsewhere on the board
COR: U3.10
DB0: U9.3 (D0), U13.19 (Q0); also elsewhere on the board
DB1: U9.4 (D1), U13.18 (Q1); also elsewhere on the board
DB2: U9.7 (D2), U13.17 (Q2); also elsewhere on the board
DB3: U9.8 (D3), U13.16 (Q3); also elsewhere on the board
DB4: U9.13 (D4), U13.15 (Q4); also elsewhere on the board
DB5: U9.14 (D5), U13.14 (Q5); also elsewhere on the board
DB6: U9.17 (D6), U13.13 (Q6); also elsewhere on the board
DB7: U9.18 (D7), U13.12 (Q7); also elsewhere on the board
EXIT: U9.11 (Cp); also elsewhere on the board
FREE: U12.1; also elsewhere on the board
HI0: U14.18 (1Y0); also elsewhere on the board
HI1: U14.16 (1Y1); also elsewhere on the board
HI2: U14.14 (1Y2); also elsewhere on the board
HI3: U14.12 (1Y3); also elsewhere on the board
HI4: U14.3 (2Y0); also elsewhere on the board
HI5: U14.5 (2Y1); also elsewhere on the board
HI6: U14.7 (2Y2); also elsewhere on the board
HI7: U14.9 (2Y3); also elsewhere on the board
IPH: U7.12; also elsewhere on the board
unnamed: U5.13, U8.5 (Q)
unnamed: U3.8, U10.1
unnamed: U5.11, U11.11 (Cp)
unnamed: U9.2 (Q0), U11.3 (D0)
unnamed: U9.5 (Q1), U11.4 (D1)
unnamed: U9.6 (Q2), U11.7 (D2)
unnamed: U9.9 (Q3), U11.8 (D3)
unnamed: U9.12 (Q4), U11.13 (D4)
unnamed: U9.15 (Q5), U11.14 (D5)
unnamed: U9.16 (Q6), U11.17 (D6)
unnamed: U9.19 (Q7), U11.18 (D7)
unnamed: U7.13, U14.1 (1OE), U14.19 (2OE)
Nx_pre_clean: U7.11; also elsewhere on the board
PH3: U10.2
TRAP: U3.5
xC: U3.4; also elsewhere on the board
~EXIT: U8.4 (~S), U10.3
~OWN: U13.1 (OE); also elsewhere on the board
~PH0: U8.1 (~R); also elsewhere on the board
~RES: U9.1 (~Mr), U11.1 (~Mr); also elsewhere on the board

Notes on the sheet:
Code Page Index (C) Register
Clear Program Counter applied during CLOSE
PIN 1 (non-inverted output) was missing in KiCAD symbol
Dupe Register (D)
FREE signals that code execution is outside the TRAP region (pages 0-31). Intererrupts are enabled, iff this is the case
573 Level triggered
~{EXIT}: PH3: Register branch target CLOSE: Load into C
Delay the ~{EXIT} signal so that Code Page updates at CLOSE
Control Tree

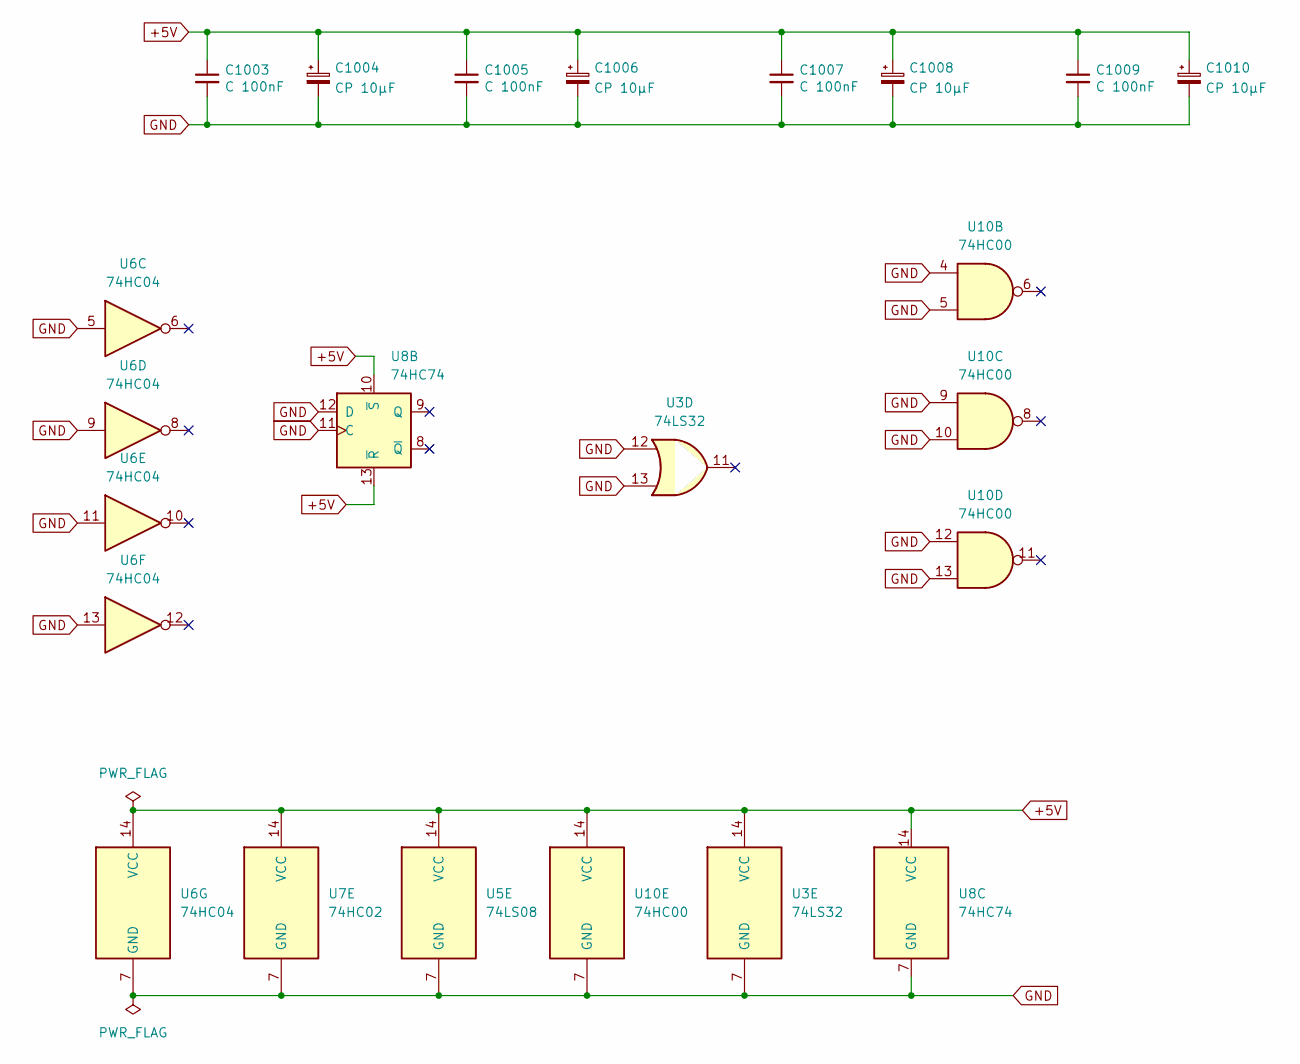
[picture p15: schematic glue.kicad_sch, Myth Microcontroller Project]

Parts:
C1003, C1005, C1007, C1009: C 100nF; C_Disc_D5.0mm_W2.5mm_P2.50mm
C1004, C1006, C1008, C1010: CP 10μF; CP_Radial_D6.3mm_P2.50mm
U3: 74LS32; DIP-14_W7.62mm_LongPads
U5: 74LS08; DIP-14_W7.62mm_LongPads
U6: 74HC04; DIP-14_W7.62mm_LongPads
U7: 74HC02; DIP-14_W7.62mm_LongPads
U8: 74HC74; DIP-14_W7.62mm_LongPads
U10: 74HC00; DIP-14_W7.62mm_LongPads

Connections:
+5V: C1003.1, C1004.1, C1005.1, C1006.1, C1007.1, C1008.1, C1009.1, C1010.1, U3.14 (VCC), U5.14 (VCC), U6.14 (VCC), U7.14 (VCC), U8.10 (~S), U8.13 (~R), U8.14 (VCC), U10.14 (VCC); also elsewhere on the board
~SUBR: U6.2; also elsewhere on the board

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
Board: 2 copper layers, 44 parts (0 on the bottom side), 89 nets, no tracks yet.

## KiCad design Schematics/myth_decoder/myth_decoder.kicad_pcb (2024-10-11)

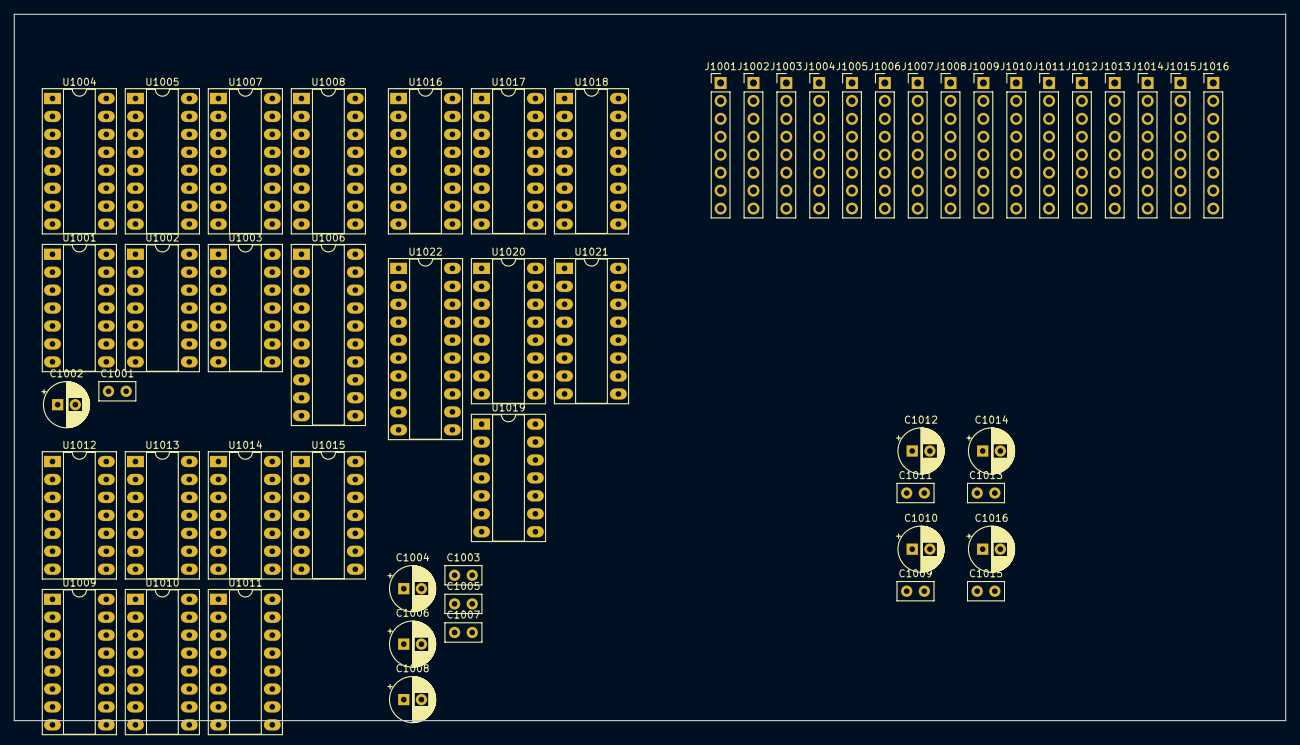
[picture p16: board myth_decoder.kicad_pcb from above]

Board: 2 copper layers, 180.0 x 100.0 mm, 54 parts (0 on the bottom side), 107 nets, no tracks yet.

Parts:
C1001, C1003, C1005, C1007, C1009, C1011, C1013, C1015: C 100nF; C_Disc_D5.0mm_W2.5mm_P2.50mm
C1002, C1004, C1006, C1008, C1010, C1012, C1014, C1016: CP 10μF; CP_Radial_D6.3mm_P2.50mm
J1001, J1002, J1003, J1004, J1005, J1006, J1007, J1008, J1009, J1010, J1011, J1012, J1013, J1014, J1015, J1016: Conn_01x08_Pin; PinHeader_1x08_P2.54mm_Vertical
U1001: 74HC74; DIP-14_W7.62mm_Socket_LongPads
U1002, U1012: 74LS08; DIP-14_W7.62mm_Socket_LongPads
U1003: 74LS32; DIP-14_W7.62mm_Socket_LongPads
U1004, U1005: 74HC157; DIP-16_W7.62mm_Socket_LongPads
U1006: 74AHC273; DIP-20_W7.62mm_Socket_LongPads
U1007: 74LS148; DIP-16_W7.62mm_Socket_LongPads
U1008, U1016, U1018, U1020, U1021: 74AHC138; DIP-16_W7.62mm_Socket_LongPads
U1009, U1010, U1011, U1017: 74HC238; DIP-16_W7.62mm_Socket_LongPads
U1013: 74AHC04; DIP-14_W7.62mm_Socket_LongPads
U1014: 4078; DIP-14_W7.62mm_Socket_LongPads
U1015: 4075; DIP-14_W7.62mm_Socket_LongPads
U1019: 74HC02; DIP-14_W7.62mm_Socket_LongPads
U1022: 74AHC244; DIP-20_W7.62mm_Socket_LongPads

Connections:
+5V: C1001.1, C1002.1, C1003.1, C1004.1, C1005.1, C1006.1, C1007.1, C1008.1, C1009.1, C1010.1, C1011.1, C1012.1, C1013.1, C1014.1, C1015.1, C1016.1, J1005.1, U1001.2 (D), U1001.10 (~S), U1001.13 (~R), U1001.14 (VCC), U1002.14 (VCC), U1003.14 (VCC), U1004.16 (VCC), U1005.6 (I1b), U1005.16 (VCC), U1006.20 (VCC), U1007.16 (VCC), U1008.16 (VCC), U1009.6 (E3), U1009.16 (VCC), U1010.16 (VCC), U1011.6 (E3), U1011.16 (VCC), U1012.14 (VCC), U1013.14 (VCC), U1014.14 (Vdd), U1015.14 (VDD), U1016.16 (VCC), U1017.16 (VCC), U1018.6 (E3), U1018.16 (VCC), U1019.14 (VCC), U1020.6 (E3), U1020.16 (VCC), U1021.16 (VCC), U1022.20 (VCC)
/IW0: U1004.4 (Za), U1006.3 (D0)
/IW1: U1004.7 (Zb), U1006.4 (D1)
/IW2: U1004.9 (Zc), U1006.7 (D2)
/IW3: U1004.12 (Zd), U1006.8 (D3)
/IW4: U1005.4 (Za), U1006.13 (D4)
/IW5: U1005.7 (Zb), U1006.14 (D5)
/IW6: U1005.9 (Zc), U1006.17 (D6)
/IW7: U1005.12 (Zd), U1006.18 (D7)
DB0: J1001.1, U1004.2 (I0a), U1022.18 (1Y0)
DB1: J1001.2, U1004.5 (I0b), U1022.16 (1Y1)
DB2: J1001.3, U1004.11 (I0c), U1022.14 (1Y2)
DB3: J1001.4, U1004.14 (I0d), U1022.12 (1Y3)
DB4: J1001.5, U1005.2 (I0a), U1022.3 (2Y0)
DB5: J1001.6, U1005.5 (I0b), U1022.5 (2Y1)
DB6: J1001.7, U1005.11 (I0c), U1022.7 (2Y2)
DB7: J1001.8, U1005.14 (I0d), U1022.9 (2Y3)
DPH: J1005.7, U1016.6 (E3)
FREE: J1007.2, U1002.2
GET: J1007.6, U1002.8
GETPUT: J1007.8, U1002.5, U1002.9, U1019.1, U1021.6 (E3)
GND: C1001.2, C1002.2, C1003.2, C1004.2, C1005.2, C1006.2, C1007.2, C1008.2, C1009.2, C1010.2, C1011.2, C1012.2, C1013.2, C1014.2, C1015.2, C1016.2, J1005.2, U1001.3 (C), U1001.7 (GND), U1001.11 (C), U1001.12 (D), U1002.7 (GND), U1002.12, U1002.13, U1003.7 (GND), U1004.3 (I1a), U1004.6 (I1b), U1004.8 (GND), U1004.10 (I1c), U1004.13 (I1d), U1004.15 (E), U1005.3 (I1a), U1005.8 (GND), U1005.10 (I1c), U1005.13 (I1d), U1005.15 (E), U1006.10 (GND), U1007.2 (I5), U1007.3 (I6), U1007.4 (I7), U1007.8 (GND), U1008.4 (E1), U1008.8 (GND), U1009.8 (GND), U1010.5 (~E2), U1010.8 (GND), U1011.8 (GND), U1012.7 (GND), U1013.5, U1013.7 (GND), U1013.9, U1013.11, U1013.13, U1014.4, U1014.5, U1014.7 (Vss), U1014.9, U1014.10, U1014.11, U1014.12, U1015.3, U1015.4, U1015.5, U1015.7 (VSS), U1015.11, U1015.12, U1015.13, U1016.8 (GND), U1017.4 (~G2A), U1017.8 (GND), U1018.8 (GND), U1019.5, U1019.6, U1019.7 (GND), U1019.8, U1019.9, U1019.11, U1019.12, U1020.5 (E2), U1020.8 (GND), U1021.4 (E1), U1021.5 (E2), U1021.8 (GND), U1022.10 (GND), U1022.11 (2A3), U1022.13 (2A2), U1022.15 (2A1)
IB0: J1002.1, U1006.2 (Q0), U1009.1 (A0), U1010.1 (A0), U1017.1 (A0), U1018.1 (A0), U1020.1 (A0), U1022.2 (1A0)
IB1: J1002.2, U1006.5 (Q1), U1009.2 (A1), U1010.2 (A1), U1017.2 (A1), U1018.2 (A1), U1020.2 (A1), U1022.4 (1A1)
IB2: J1002.3, U1006.6 (Q2), U1009.3 (A2), U1010.3 (A2), U1017.3 (A2), U1018.3 (A2), U1020.3 (A2), U1022.6 (1A2)
IB3: J1002.4, U1002.4, U1006.9 (Q3), U1007.10 (IO), U1009.5 (~E2), U1010.6 (E3), U1011.5 (~E2), U1013.3, U1017.6 (G1), U1018.4 (E1), U1021.3 (A2), U1022.8 (1A3)
IB4: J1002.5, U1006.12 (Q4), U1007.11 (I1), U1011.1 (A0), U1016.1 (A0), U1021.1 (A0), U1022.17 (2A0)
IB5: J1002.6, U1006.15 (Q5), U1007.12 (I2), U1011.2 (A1), U1016.2 (A1), U1021.2 (A1)
IB6: J1002.7, U1006.16 (Q6), U1007.13 (I3), U1011.3 (A2), U1016.3 (A2)
IB7: J1002.8, U1006.19 (Q7), U1007.1 (I4)
Lx_pre: J1004.4, U1003.1, U1011.13 (Y2)
Mx_pre: J1004.7, U1003.2, U1011.14 (Y1)
unnamed: U1001.5 (Q), U1002.1
unnamed: U1001.4 (~S), U1003.8
unnamed: U1002.10, U1013.4
unnamed: U1003.3, U1012.1
unnamed: U1003.6, U1012.2, U1012.5
unnamed: U1002.3, U1004.1 (S), U1005.1 (S)
unnamed: U1007.14 (GS), U1008.6 (E3)
unnamed: U1007.9 (S0), U1008.1 (A0)
unnamed: U1007.7 (S1), U1008.2 (A1)
unnamed: U1007.6 (S2), U1008.3 (A2)
unnamed: U1012.3, U1014.2
unnamed: U1012.6, U1013.1, U1014.3
unnamed: U1012.9, U1013.2
Nx_pre: U1011.15 (Y0), U1012.4, U1012.10
Nx_pre_clean: J1004.5, U1012.8, U1012.13
PH0: J1005.4, U1008.5 (E2)
PH1: J1005.5, U1006.11 (Cp), U1012.12
PUT: J1007.7, U1002.6
SCROUNGE: J1007.4, U1014.1, U1015.8, U1016.5 (E2)
xA: J1012.2, U1017.14 (Y1)
xB: J1012.3, U1017.13 (Y2)
xC: J1012.8, U1017.7 (Y7)
xE: J1012.1, U1017.15 (Y0)
xF: J1012.7, U1017.9 (Y6)
xJ: J1012.4, U1017.12 (Y3)
xL_pre: J1004.3, U1003.4, U1009.13 (Y2)
xM_pre: J1004.6, U1003.5, U1009.14 (Y1)
xT: J1012.6, U1017.10 (Y5)
xW: J1012.5, U1017.11 (Y4)
xW_pre: J1004.8, U1010.11 (Y4)
~CLOSE: J1007.1, U1001.1 (~R)
~COR: J1015.7, U1020.9 (O6)
~DPH: J1005.6, U1003.13, U1019.3
~Dx: J1013.4, U1016.12 (O3)
~GETD: J1016.1, U1021.15 (O0)
~GETI: J1016.2, U1021.14 (O1)
~GETO: J1016.4, U1021.12 (O3)
~GETR: J1016.3, U1021.13 (O2)
~IRQ: J1003.1, U1003.9
~Ix: J1013.6, U1016.10 (O5)
~Lx: J1013.3, U1016.13 (O2)
~Mx: J1013.2, U1016.14 (O1)
~NOP: J1015.1, U1020.15 (O0)
~Nx: J1013.1, U1016.15 (O0)
~OWN: J1015.8, U1020.7 (O7)
~PH0: J1005.3, U1003.10, U1006.1 (~Mr), U1007.5 (EI)
~PH3: J1005.8, U1015.2
~PUTD: J1016.5, U1021.11 (O4)
~PUTI: J1016.6, U1021.10 (O5)
~PUTO: J1016.8, U1021.7 (O7)
~PUTR: J1016.7, U1021.9 (O6)
~Px: J1013.8, U1016.7 (O7)
~RCOPY: J1007.3, U1015.9, U1017.5 (~G2B), U1018.5 (E2)
~RET: J1015.6, U1020.10 (O5)
~Rx: J1013.5, U1016.11 (O4)
~SCH: J1015.5, U1020.11 (O4)
~SCL: J1015.4, U1020.12 (O3)
~SSI: J1015.2, U1020.14 (O1)
~SSO: J1015.3, U1020.13 (O2)
~Sx: J1013.7, U1016.9 (O6)
~TRAP: J1007.5, U1003.11, U1022.1 (1OE), U1022.19 (2OE)
~opc_ALU: J1014.3, U1008.14 (O1)
~opc_DIRO: J1014.5, U1008.12 (O3), U1019.2
~opc_FIX: J1014.2, U1008.15 (O0)
~opc_PAIR: J1014.6, U1008.11 (O4), U1009.4 (~E1), U1010.4 (~E1), U1011.4 (~E1), U1015.1, U1016.4 (E1)
~opc_SYS: J1014.1, U1007.15 (EO), U1020.4 (E1)
~opc_TRAP: J1014.4, U1003.12, U1008.13 (O2)
~xD: J1011.4, U1018.12 (O3)
~xI: J1011.6, U1018.10 (O5)
~xL: J1011.3, U1018.13 (O2)
~xM: J1011.2, U1018.14 (O1)
~xO: J1011.1, U1018.15 (O0)
~xP: J1011.8, U1018.7 (O7)
~xR: J1011.5, U1018.11 (O4)
~xS: J1011.7, U1018.9 (O6)

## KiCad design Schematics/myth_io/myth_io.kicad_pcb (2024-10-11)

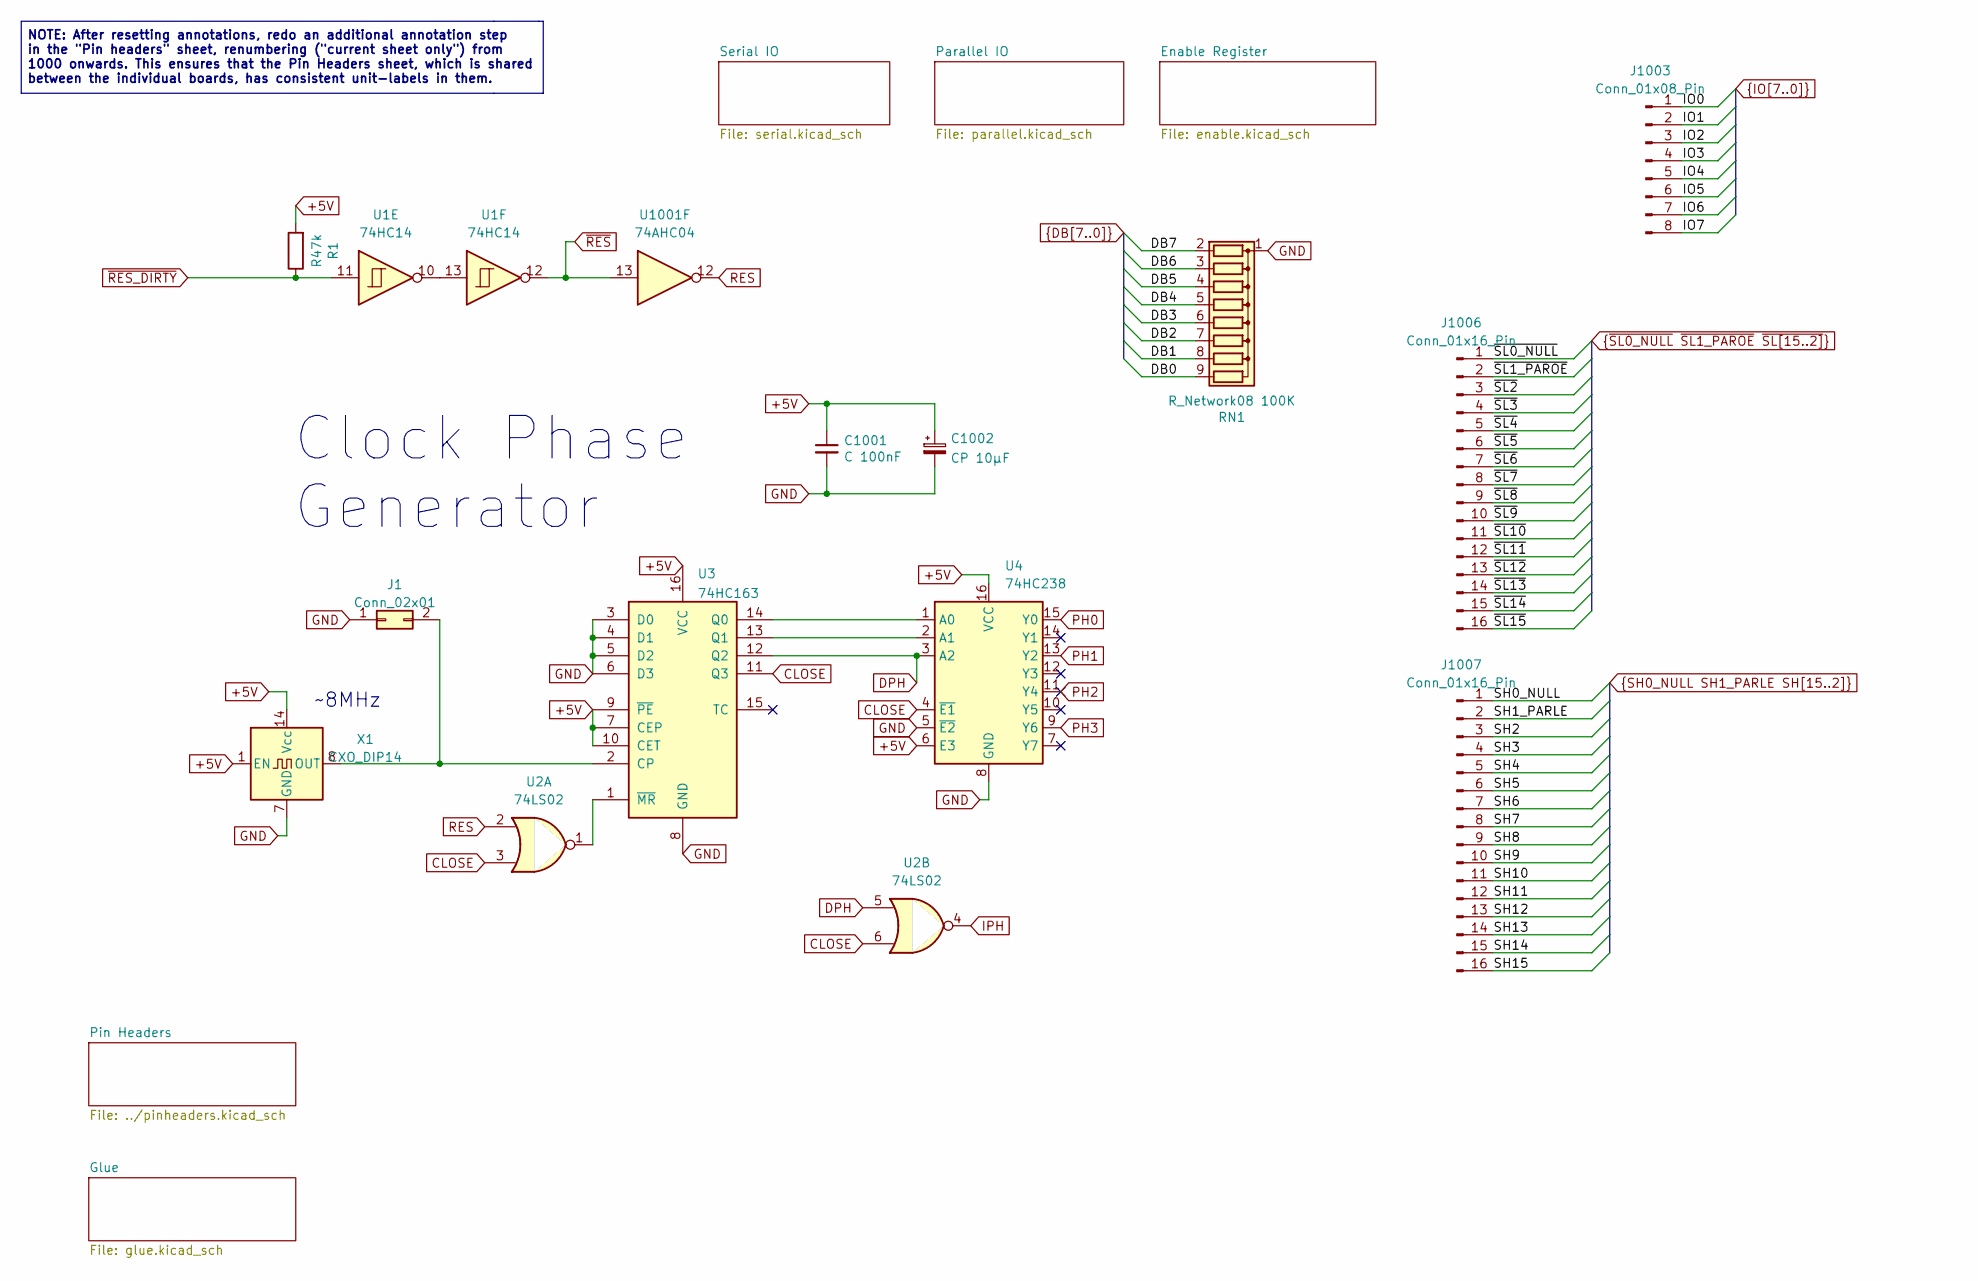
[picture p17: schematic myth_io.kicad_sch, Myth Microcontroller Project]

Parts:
C1001: C 100nF; C_Disc_D5.0mm_W2.5mm_P2.50mm
C1002: CP 10μF; CP_Radial_D6.3mm_P2.50mm
J1: Conn_02x01; PinHeader_2x01_P2.54mm_Vertical
J1003: Conn_01x08_Pin
J1006, J1007: Conn_01x16_Pin; PinHeader_1x16_P2.54mm_Vertical
R1: R47k; R_Axial_DIN0207_L6.3mm_D2.5mm_P10.16mm_Horizontal
RN1: R_Network08 100K; R_Array_SIP9
U1: 74HC14; DIP-14_W7.62mm_Socket_LongPads
U2: 74LS02; DIP-14_W7.62mm_Socket_LongPads
U3: 74HC163; DIP-16_W7.62mm_Socket_LongPads
U4: 74HC238; DIP-16_W7.62mm_Socket_LongPads
U1001: 74AHC04; DIP-14_W7.62mm_Socket_LongPads
X1: CXO_DIP14; Oscillator_DIP-14

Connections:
+5V: C1001.1, C1002.1, R1.2, U3.7 (CEP), U3.9 (~PE), U3.10 (CET), U3.16 (VCC), U4.6 (E3), U4.16 (VCC), X1.1 (EN), X1.14 (Vcc); also elsewhere on the board
CLOSE: U2.3, U2.6, U3.11 (Q3), U4.4 (~E1)
DB0: RN1.9 (R8); also elsewhere on the board
DB1: RN1.8 (R7); also elsewhere on the board
DB2: RN1.7 (R6); also elsewhere on the board
DB3: RN1.6 (R5); also elsewhere on the board
DB4: RN1.5 (R4); also elsewhere on the board
DB5: RN1.4 (R3); also elsewhere on the board
DB6: RN1.3 (R2); also elsewhere on the board
DB7: RN1.2 (R1); also elsewhere on the board
DPH: U2.5, U3.12 (Q2), U4.3 (A2); also elsewhere on the board
GND: C1001.2, C1002.2, J1.1, RN1.1 (common), U3.3 (D0), U3.4 (D1), U3.5 (D2), U3.6 (D3), U3.8 (GND), U4.5 (~E2), U4.8 (GND), X1.7 (GND); also elsewhere on the board
IPH: U2.4; also elsewhere on the board
unnamed: J1.2, U3.2 (CP), X1.8 (OUT)
unnamed: U1.10, U1.13
unnamed: U3.14 (Q0), U4.1 (A0)
unnamed: U3.13 (Q1), U4.2 (A1)
unnamed: U2.1, U3.1 (~MR)
PH0: U4.15 (Y0); also elsewhere on the board
PH1: U4.13 (Y2); also elsewhere on the board
PH2: U4.11 (Y4); also elsewhere on the board
PH3: U4.9 (Y6)
RES: U2.2, U1001.12; also elsewhere on the board
SH0_NULL: J1007.1; also elsewhere on the board
SH1_PARLE: J1007.2; also elsewhere on the board
SH2: J1007.3; also elsewhere on the board
SH3: J1007.4; also elsewhere on the board
SH4: J1007.5; also elsewhere on the board
SH5: J1007.6; also elsewhere on the board
SH6: J1007.7; also elsewhere on the board
SH7: J1007.8; also elsewhere on the board
SH8: J1007.9; also elsewhere on the board
SH9: J1007.10; also elsewhere on the board
SH10: J1007.11; also elsewhere on the board
SH11: J1007.12; also elsewhere on the board
SH12: J1007.13; also elsewhere on the board
SH13: J1007.14; also elsewhere on the board
SH14: J1007.15; also elsewhere on the board
SH15: J1007.16; also elsewhere on the board
~RES_DIRTY: R1.1, U1.11; also elsewhere on the board
~RES: U1.12, U1001.13; also elsewhere on the board
~SL0_NULL: J1006.1; also elsewhere on the board
~SL1_PAROE: J1006.2; also elsewhere on the board
~SL2: J1006.3; also elsewhere on the board
~SL3: J1006.4; also elsewhere on the board
~SL4: J1006.5; also elsewhere on the board
~SL5: J1006.6; also elsewhere on the board
~SL6: J1006.7; also elsewhere on the board
~SL7: J1006.8; also elsewhere on the board
~SL8: J1006.9; also elsewhere on the board
~SL9: J1006.10; also elsewhere on the board
~SL10: J1006.11; also elsewhere on the board
~SL11: J1006.12; also elsewhere on the board
~SL12: J1006.13; also elsewhere on the board
~SL13: J1006.14; also elsewhere on the board
~SL14: J1006.15; also elsewhere on the board
~SL15: J1006.16; also elsewhere on the board

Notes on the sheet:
NOTE: After resetting annotations, redo an additional annotation step in the "Pin headers" sheet, renumbering ("current sheet only") from 1000 onwards. This ensures that the Pin Headers sheet, which is shared between the individual boards, has consistent unit-labels in them.
~8MHz
Clock Phase Generator

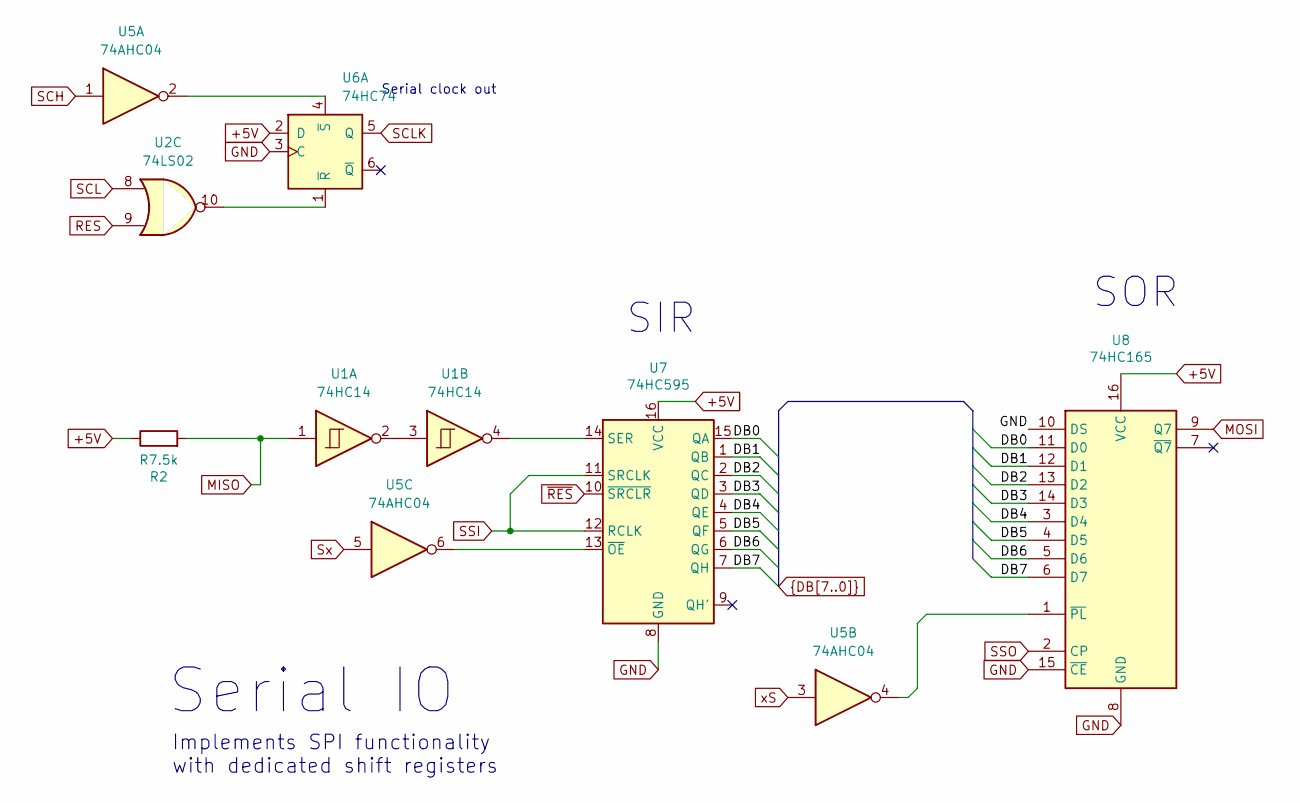
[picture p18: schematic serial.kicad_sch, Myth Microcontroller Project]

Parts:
R2: R7.5k; R_Axial_DIN0207_L6.3mm_D2.5mm_P10.16mm_Horizontal
U1: 74HC14; DIP-14_W7.62mm_Socket_LongPads
U2: 74LS02; DIP-14_W7.62mm_Socket_LongPads
U5: 74AHC04; DIP-14_W7.62mm_Socket_LongPads
U6: 74HC74; DIP-14_W7.62mm_Socket_LongPads
U7: 74HC595; DIP-16_W7.62mm_Socket_LongPads
U8: 74HC165; DIP-16_W7.62mm_Socket_LongPads

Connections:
+5V: R2.1, U6.2 (D), U7.16 (VCC), U8.16 (VCC); also elsewhere on the board
DB0: U7.15 (QA), U8.11 (D0); also elsewhere on the board
DB1: U7.1 (QB), U8.12 (D1); also elsewhere on the board
DB2: U7.2 (QC), U8.13 (D2); also elsewhere on the board
DB3: U7.3 (QD), U8.14 (D3); also elsewhere on the board
DB4: U7.4 (QE), U8.3 (D4); also elsewhere on the board
DB5: U7.5 (QF), U8.4 (D5); also elsewhere on the board
DB6: U7.6 (QG), U8.5 (D6); also elsewhere on the board
DB7: U7.7 (QH), U8.6 (D7); also elsewhere on the board
GND: U6.3 (C), U7.8 (GND), U8.8 (GND), U8.10 (DS), U8.15 (~CE); also elsewhere on the board
MISO: R2.2, U1.1; also elsewhere on the board
MOSI: U8.9 (Q7); also elsewhere on the board
unnamed: U1.2, U1.3
unnamed: U2.10, U6.1 (~R)
unnamed: U5.2, U6.4 (~S)
unnamed: U1.4, U7.14 (SER)
unnamed: U5.6, U7.13 (~OE)
unnamed: U5.4, U8.1 (~PL)
RES: U2.9; also elsewhere on the board
SCH: U5.1
SCL: U2.8
SCLK: U6.5 (Q); also elsewhere on the board
SSI: U7.11 (SRCLK), U7.12 (RCLK)
SSO: U8.2 (CP)
Sx: U5.5
xS: U5.3
~RES: U7.10 (~SRCLR); also elsewhere on the board

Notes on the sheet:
SOR
Serial IO
Implements SPI functionality with dedicated shift registers
SIR
Serial clock out

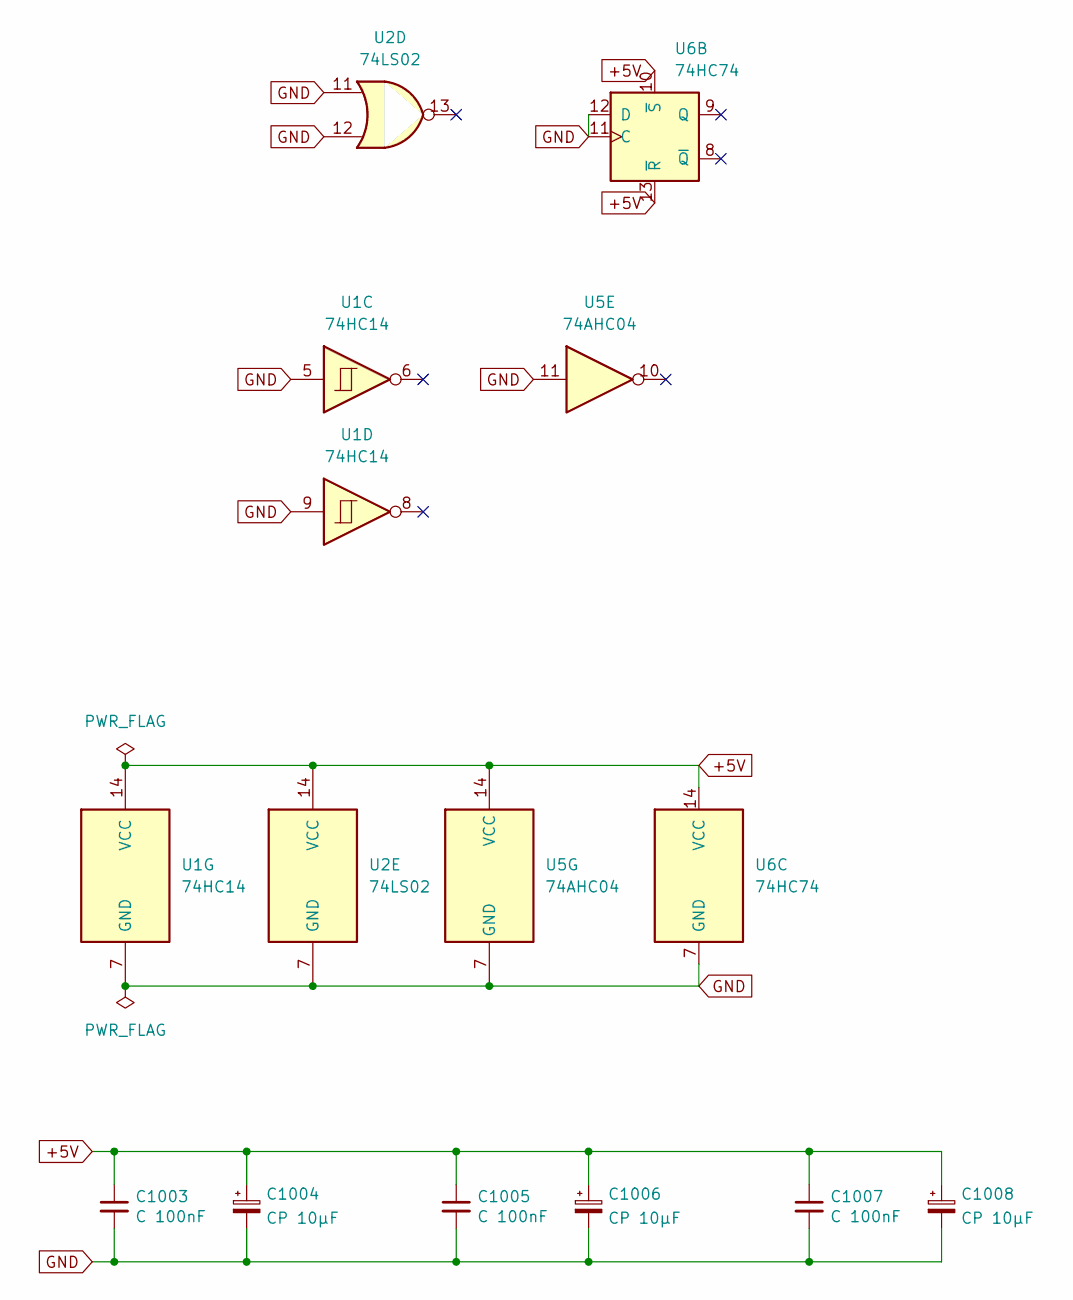
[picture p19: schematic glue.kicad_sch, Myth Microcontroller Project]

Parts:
C1003, C1005, C1007: C 100nF; C_Disc_D5.0mm_W2.5mm_P2.50mm
C1004, C1006, C1008: CP 10μF; CP_Radial_D6.3mm_P2.50mm
U1: 74HC14; DIP-14_W7.62mm_Socket_LongPads
U2: 74LS02; DIP-14_W7.62mm_Socket_LongPads
U5: 74AHC04; DIP-14_W7.62mm_Socket_LongPads
U6: 74HC74; DIP-14_W7.62mm_Socket_LongPads

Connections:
+5V: C1003.1, C1004.1, C1005.1, C1006.1, C1007.1, C1008.1, U1.14 (VCC), U2.14 (VCC), U5.14 (VCC), U6.10 (~S), U6.13 (~R), U6.14 (VCC); also elsewhere on the board
GND: C1003.2, C1004.2, C1005.2, C1006.2, C1007.2, C1008.2, U1.5, U1.7 (GND), U1.9, U2.7 (GND), U2.11, U2.12, U5.7 (GND), U5.11, U6.7 (GND), U6.11 (C), U6.12 (D); also elsewhere on the board

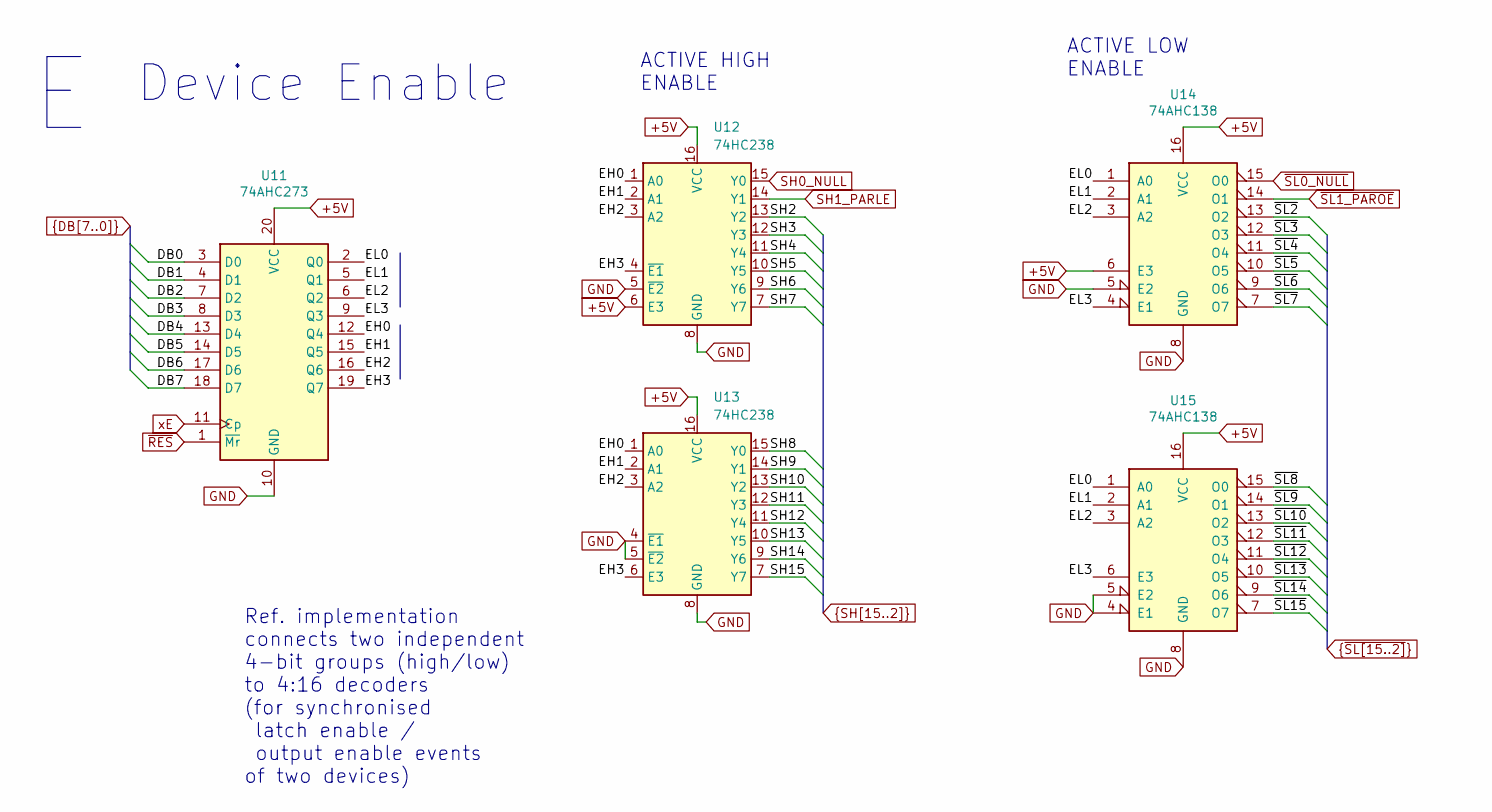
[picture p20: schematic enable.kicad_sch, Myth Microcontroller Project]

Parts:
U11: 74AHC273; DIP-20_W7.62mm_Socket_LongPads
U12, U13: 74HC238; DIP-16_W7.62mm_Socket_LongPads
U14, U15: 74AHC138; DIP-16_W7.62mm_Socket_LongPads

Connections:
+5V: U11.20 (VCC), U12.6 (E3), U12.16 (VCC), U13.16 (VCC), U14.6 (E3), U14.16 (VCC), U15.16 (VCC); also elsewhere on the board
/Enable Register/EH0: U11.12 (Q4), U12.1 (A0), U13.1 (A0)
/Enable Register/EH1: U11.15 (Q5), U12.2 (A1), U13.2 (A1)
/Enable Register/EH2: U11.16 (Q6), U12.3 (A2), U13.3 (A2)
/Enable Register/EH3: U11.19 (Q7), U12.4 (~E1), U13.6 (E3)
/Enable Register/EL0: U11.2 (Q0), U14.1 (A0), U15.1 (A0)
/Enable Register/EL1: U11.5 (Q1), U14.2 (A1), U15.2 (A1)
/Enable Register/EL2: U11.6 (Q2), U14.3 (A2), U15.3 (A2)
/Enable Register/EL3: U11.9 (Q3), U14.4 (E1), U15.6 (E3)
DB0: U11.3 (D0); also elsewhere on the board
DB1: U11.4 (D1); also elsewhere on the board
DB2: U11.7 (D2); also elsewhere on the board
DB3: U11.8 (D3); also elsewhere on the board
DB4: U11.13 (D4); also elsewhere on the board
DB5: U11.14 (D5); also elsewhere on the board
DB6: U11.17 (D6); also elsewhere on the board
DB7: U11.18 (D7); also elsewhere on the board
GND: U11.10 (GND), U12.5 (~E2), U12.8 (GND), U13.4 (~E1), U13.5 (~E2), U13.8 (GND), U14.5 (E2), U14.8 (GND), U15.4 (E1), U15.5 (E2), U15.8 (GND); also elsewhere on the board
SH0_NULL: U12.15 (Y0); also elsewhere on the board
SH1_PARLE: U12.14 (Y1); also elsewhere on the board
SH2: U12.13 (Y2); also elsewhere on the board
SH3: U12.12 (Y3); also elsewhere on the board
SH4: U12.11 (Y4); also elsewhere on the board
SH5: U12.10 (Y5); also elsewhere on the board
SH6: U12.9 (Y6); also elsewhere on the board
SH7: U12.7 (Y7); also elsewhere on the board
SH8: U13.15 (Y0); also elsewhere on the board
SH9: U13.14 (Y1); also elsewhere on the board
SH10: U13.13 (Y2); also elsewhere on the board
SH11: U13.12 (Y3); also elsewhere on the board
SH12: U13.11 (Y4); also elsewhere on the board
SH13: U13.10 (Y5); also elsewhere on the board
SH14: U13.9 (Y6); also elsewhere on the board
SH15: U13.7 (Y7); also elsewhere on the board
xE: U11.11 (Cp); also elsewhere on the board
~RES: U11.1 (~Mr); also elsewhere on the board
~SL0_NULL: U14.15 (O0); also elsewhere on the board
~SL1_PAROE: U14.14 (O1); also elsewhere on the board
~SL2: U14.13 (O2); also elsewhere on the board
~SL3: U14.12 (O3); also elsewhere on the board
~SL4: U14.11 (O4); also elsewhere on the board
~SL5: U14.10 (O5); also elsewhere on the board
~SL6: U14.9 (O6); also elsewhere on the board
~SL7: U14.7 (O7); also elsewhere on the board
~SL8: U15.15 (O0); also elsewhere on the board
~SL9: U15.14 (O1); also elsewhere on the board
~SL10: U15.13 (O2); also elsewhere on the board
~SL11: U15.12 (O3); also elsewhere on the board
~SL12: U15.11 (O4); also elsewhere on the board
~SL13: U15.10 (O5); also elsewhere on the board
~SL14: U15.9 (O6); also elsewhere on the board
~SL15: U15.7 (O7); also elsewhere on the board

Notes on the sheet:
ACTIVE LOW ENABLE
Ref. implementation connects two independent 4-bit groups (high/low) to 4:16 decoders (for synchronised latch enable / output enable events of two devices)
Device Enable
ACTIVE HIGH ENABLE


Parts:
J1001, J1002, J1004, J1005, J1008, J1010, J1011, J1012, J1013, J1014, J1015, J1016, J1017, J1018, J1019, J1020: Conn_01x08_Pin; PinHeader_1x08_P2.54mm_Vertical

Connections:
+5V: J1008.1; also elsewhere on the board
DB0: J1001.1; also elsewhere on the board
DB1: J1001.2; also elsewhere on the board
DB2: J1001.3; also elsewhere on the board
DB3: J1001.4; also elsewhere on the board
DB4: J1001.5; also elsewhere on the board
DB5: J1001.6; also elsewhere on the board
DB6: J1001.7; also elsewhere on the board
DB7: J1001.8; also elsewhere on the board
DPH: J1008.7; also elsewhere on the board
EXIT: J1005.1
FETCH: J1004.7
FREE: J1010.2
GET: J1010.6
GETPUT: J1010.8
GND: J1008.2; also elsewhere on the board
HI0: J1012.1
HI1: J1012.2
HI2: J1012.3
HI3: J1012.4
HI4: J1012.5
HI5: J1012.6
HI6: J1012.7
HI7: J1012.8
IB0: J1002.1
IB1: J1002.2
IB2: J1002.3
IB3: J1002.4
IB4: J1002.5
IB5: J1002.6
IB6: J1002.7
IB7: J1002.8
IPH: J1011.5; also elsewhere on the board
JUMP: J1011.4
Lx_pre: J1005.4
MISO: J1004.5; also elsewhere on the board
MOSI: J1004.6; also elsewhere on the board
Mx_pre: J1005.7
NZFLAG_I: J1011.1
NZFLAG_R: J1011.2
Nx_pre_clean: J1005.5
O0: J1013.1
O1: J1013.2
O2: J1013.3
O3: J1013.4
O4: J1013.5
O5: J1013.6
O6: J1013.7
O7: J1013.8
PC0: J1014.1
PC1: J1014.2
PC2: J1014.3
PC3: J1014.4
PC4: J1014.5
PC5: J1014.6
PC6: J1014.7
PC7: J1014.8
PH0: J1008.4; also elsewhere on the board
PH1: J1008.5; also elsewhere on the board
PH2: J1011.6; also elsewhere on the board
PUT: J1010.7
RES: J1004.2; also elsewhere on the board
SCLK: J1004.3; also elsewhere on the board
SCROUNGE: J1010.4
ZFLAG_R: J1011.3
xA: J1016.2
xA_CARRY_OUT: J1011.7
xB: J1016.3
xC: J1016.8
xE: J1016.1; also elsewhere on the board
xF: J1016.7
xJ: J1016.4
xL_pre: J1005.3
xM_pre: J1005.6
xT: J1016.6
xW: J1016.5
xW_pre: J1005.8
~CLOSE: J1010.1
~COR: J1019.7
~DPH: J1008.6
~Dx: J1017.4
~GETD: J1020.1
~GETI: J1020.2
~GETO: J1020.4
~GETR: J1020.3
~IRQ: J1004.1
~Ix: J1017.6
~Lx: J1017.3
~Mx: J1017.2
~NOP: J1019.1
~Nx: J1017.1
~OWN: J1019.8
~PH0: J1008.3
~PH3: J1008.8
~PUTD: J1020.5
~PUTI: J1020.6
~PUTO: J1020.8
~PUTR: J1020.7
~Px: J1017.8
~RCOPY: J1010.3
~RES_DIRTY: J1004.8; also elsewhere on the board
~RES: J1004.4; also elsewhere on the board
~RET: J1019.6
~Rx: J1017.5
~SCH: J1019.5
~SCL: J1019.4
~SSI: J1019.2
~SSO: J1019.3
~SUBR: J1005.2
~Sx: J1017.7
~TRAP: J1010.5
~opc_ALU: J1018.3
~opc_DIRO: J1018.5
~opc_FIX: J1018.2
~opc_PAIR: J1018.6
~opc_SYS: J1018.1
~opc_TRAP: J1018.4
~xA_CARRY: J1011.8
~xD: J1015.4
~xI: J1015.6
~xL: J1015.3
~xM: J1015.2
~xO: J1015.1
~xP: J1015.8
~xR: J1015.5
~xS: J1015.7

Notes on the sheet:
Used in COUNTERS module and MEMORY module
Used in CDL module and in MEMORY module
Used in ALU module and in MEMORY module

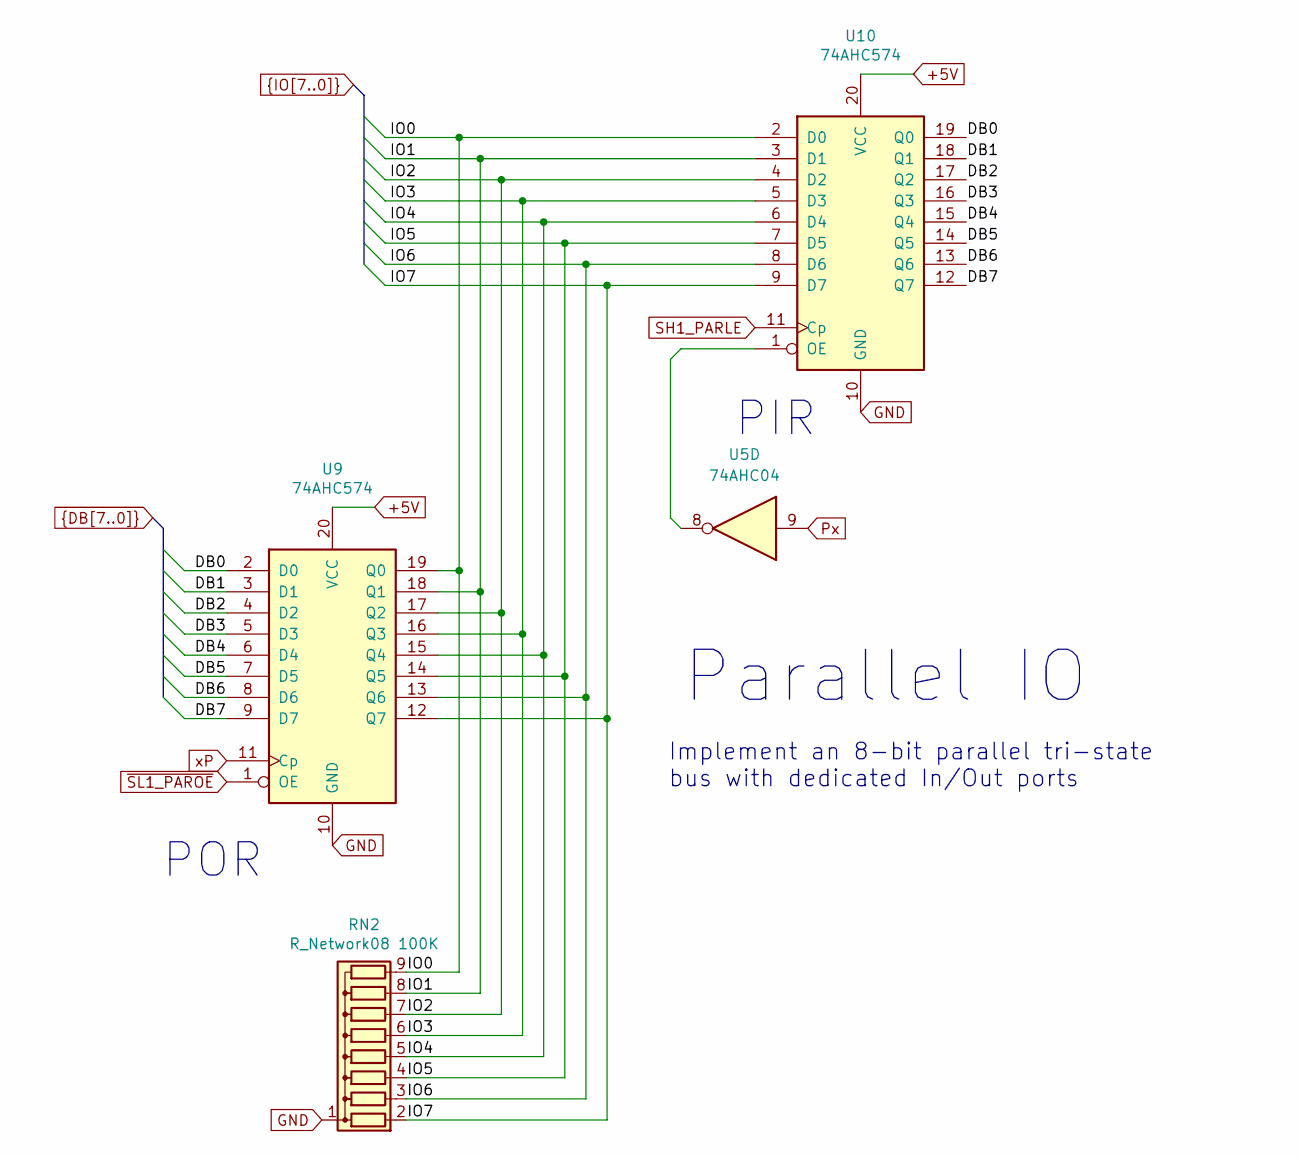
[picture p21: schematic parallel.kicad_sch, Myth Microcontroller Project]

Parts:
RN2: R_Network08 100K; R_Array_SIP9
U5: 74AHC04; DIP-14_W7.62mm_Socket_LongPads
U9, U10: 74AHC574; DIP-20_W7.62mm_Socket_LongPads

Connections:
+5V: U9.20 (VCC), U10.20 (VCC); also elsewhere on the board
DB0: U9.2 (D0), U10.19 (Q0); also elsewhere on the board
DB1: U9.3 (D1), U10.18 (Q1); also elsewhere on the board
DB2: U9.4 (D2), U10.17 (Q2); also elsewhere on the board
DB3: U9.5 (D3), U10.16 (Q3); also elsewhere on the board
DB4: U9.6 (D4), U10.15 (Q4); also elsewhere on the board
DB5: U9.7 (D5), U10.14 (Q5); also elsewhere on the board
DB6: U9.8 (D6), U10.13 (Q6); also elsewhere on the board
DB7: U9.9 (D7), U10.12 (Q7); also elsewhere on the board
GND: RN2.1 (common), U9.10 (GND), U10.10 (GND); also elsewhere on the board
IO0: RN2.9 (R8), U9.19 (Q0), U10.2 (D0)
IO1: RN2.8 (R7), U9.18 (Q1), U10.3 (D1)
IO2: RN2.7 (R6), U9.17 (Q2), U10.4 (D2)
IO3: RN2.6 (R5), U9.16 (Q3), U10.5 (D3)
IO4: RN2.5 (R4), U9.15 (Q4), U10.6 (D4)
IO5: RN2.4 (R3), U9.14 (Q5), U10.7 (D5)
IO6: RN2.3 (R2), U9.13 (Q6), U10.8 (D6)
IO7: RN2.2 (R1), U9.12 (Q7), U10.9 (D7)
unnamed: U5.8, U10.1 (OE)
Px: U5.9
SH1_PARLE: U10.11 (Cp); also elsewhere on the board
xP: U9.11 (Cp)
~SL1_PAROE: U9.1 (OE); also elsewhere on the board

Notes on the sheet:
Implement an 8-bit parallel tri-state bus with dedicated In/Out ports
PIR
POR
Parallel IO

Board: 2 copper layers, 46 parts (0 on the bottom side), 84 nets, no tracks yet.

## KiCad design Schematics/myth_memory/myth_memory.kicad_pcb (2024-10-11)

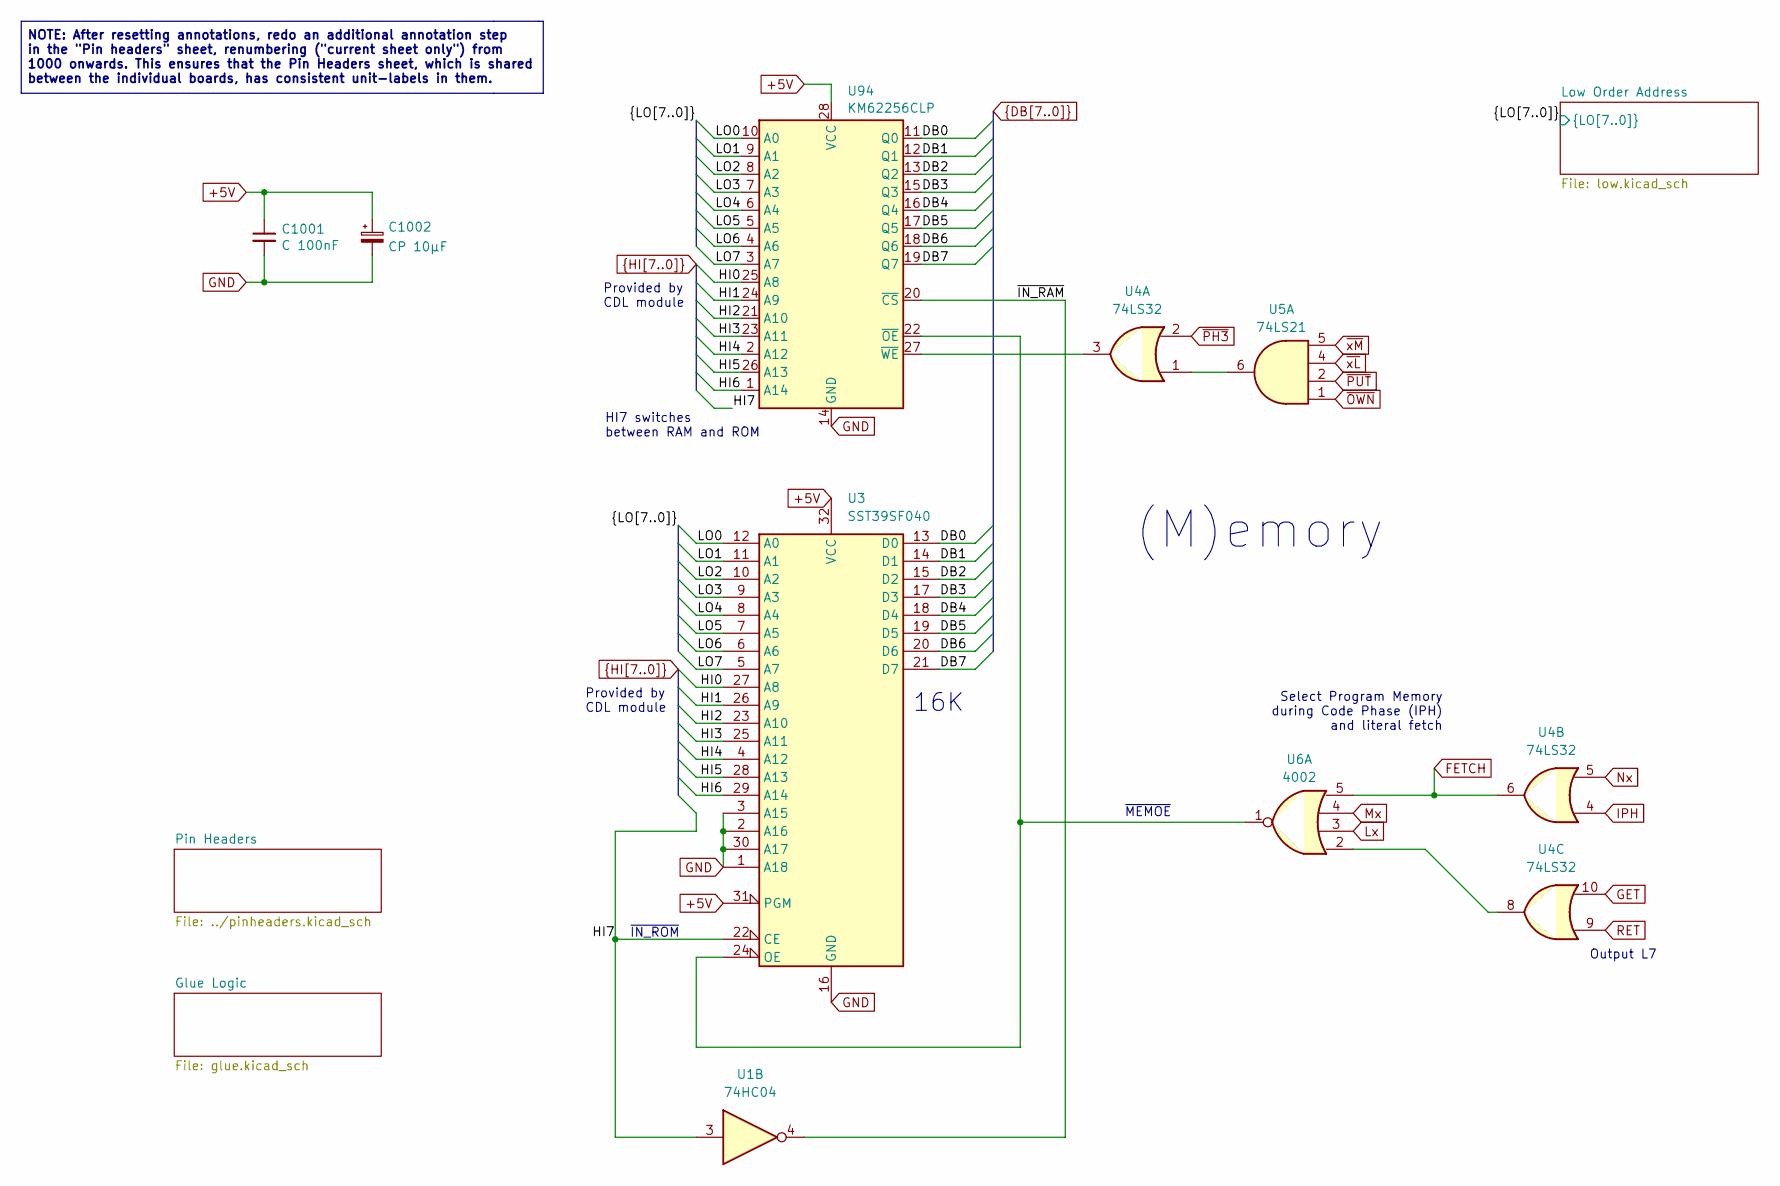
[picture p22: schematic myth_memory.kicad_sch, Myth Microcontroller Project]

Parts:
C1001: C 100nF; C_Disc_D5.0mm_W2.5mm_P2.50mm
C1002: CP 10μF; CP_Radial_D6.3mm_P2.50mm
U1: 74HC04; DIP-14_W7.62mm_LongPads
U3: SST39SF040; DIP-32_W15.24mm_LongPads
U4: 74LS32; DIP-14_W7.62mm_LongPads
U5: 74LS21; DIP-14_W7.62mm_LongPads
U6: 4002; DIP-14_W7.62mm_LongPads
U94: KM62256CLP; DIP-28_W15.24mm_LongPads

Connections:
+5V: C1001.1, C1002.1, U3.31 (PGM), U3.32 (VCC); also elsewhere on the board
/LO0: U3.12 (A0); also elsewhere on the board
/LO1: U3.11 (A1); also elsewhere on the board
/LO2: U3.10 (A2); also elsewhere on the board
/LO3: U3.9 (A3); also elsewhere on the board
/LO4: U3.8 (A4); also elsewhere on the board
/LO5: U3.7 (A5); also elsewhere on the board
/LO6: U3.6 (A6); also elsewhere on the board
/LO7: U3.5 (A7); also elsewhere on the board
/~IN_RAM: U1.4; also elsewhere on the board
DB0: U3.13 (D0); also elsewhere on the board
DB1: U3.14 (D1); also elsewhere on the board
DB2: U3.15 (D2); also elsewhere on the board
DB3: U3.17 (D3); also elsewhere on the board
DB4: U3.18 (D4); also elsewhere on the board
DB5: U3.19 (D5); also elsewhere on the board
DB6: U3.20 (D6); also elsewhere on the board
DB7: U3.21 (D7); also elsewhere on the board
FETCH: U4.6, U6.5; also elsewhere on the board
GET: U4.10; also elsewhere on the board
GND: C1001.2, C1002.2, U3.1 (A18), U3.2 (A16), U3.3 (A15), U3.16 (GND), U3.30 (A17); also elsewhere on the board
HI0: U3.27 (A8); also elsewhere on the board
HI1: U3.26 (A9); also elsewhere on the board
HI2: U3.23 (A10); also elsewhere on the board
HI3: U3.25 (A11); also elsewhere on the board
HI4: U3.4 (A12); also elsewhere on the board
HI5: U3.28 (A13); also elsewhere on the board
HI6: U3.29 (A14); also elsewhere on the board
HI7: U1.3, U3.22 (CE); also elsewhere on the board
IPH: U4.4; also elsewhere on the board
Lx: U6.3
Mx: U6.4
unnamed 55: U3.24 (OE), U6.1; also elsewhere on the board
unnamed 56: U4.3; also elsewhere on the board
unnamed: U4.1, U5.6
unnamed: U4.8, U6.2
Nx: U4.5
RET: U4.9; also elsewhere on the board
~OWN: U5.1; also elsewhere on the board
~PH3: U4.2; also elsewhere on the board
~PUT: U5.2
~xL: U5.4; also elsewhere on the board
~xM: U5.5; also elsewhere on the board

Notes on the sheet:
Output L7
~{MEMOE}
Provided by CDL module
16K
HI7 switches between RAM and ROM
Select Program Memory during Code Phase (IPH) and literal fetch
NOTE: After resetting annotations, redo an additional annotation step in the "Pin headers" sheet, renumbering ("current sheet only") from 1000 onwards. This ensures that the Pin Headers sheet, which is shared between the individual boards, has consistent unit-labels in them.
(M)emory
~{IN_ROM}

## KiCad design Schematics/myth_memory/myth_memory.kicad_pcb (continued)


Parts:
C1003, C1005, C1007, C1009: C 100nF; C_Disc_D5.0mm_W2.5mm_P2.50mm
C1004, C1006, C1008, C1010: CP 10μF; CP_Radial_D6.3mm_P2.50mm
U1: 74HC04; DIP-14_W7.62mm_LongPads
U4, U12: 74LS32; DIP-14_W7.62mm_LongPads
U5: 74LS21; DIP-14_W7.62mm_LongPads
U6: 4002; DIP-14_W7.62mm_LongPads
U8: 4075; DIP-14_W7.62mm_LongPads

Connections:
+5V: C1003.1, C1004.1, C1005.1, C1006.1, C1007.1, C1008.1, C1009.1, C1010.1, U1.14 (VCC), U4.14 (VCC), U5.14 (VCC), U6.7 (VSS), U8.14 (VDD), U12.14 (VCC); also elsewhere on the board
GND: C1003.2, C1004.2, C1005.2, C1006.2, C1007.2, C1008.2, C1009.2, C1010.2, U1.5, U1.7 (GND), U1.9, U1.11, U1.13, U4.7 (GND), U5.7 (GND), U5.9, U5.10, U5.12, U5.13, U6.9, U6.10, U6.11, U6.12, U6.14 (VDD), U8.3, U8.4, U8.5, U8.7 (VSS), U8.11, U8.12, U8.13, U12.7 (GND), U12.12, U12.13; also elsewhere on the board

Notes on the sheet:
Decoupling pairs


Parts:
U1: 74HC04; DIP-14_W7.62mm_LongPads
U4, U12: 74LS32; DIP-14_W7.62mm_LongPads
U7: 74AHC273; DIP-20_W7.62mm_Socket_LongPads
U8: 4075; DIP-14_W7.62mm_LongPads
U9, U10: 74LS257; DIP-16_W7.62mm_Socket_LongPads
U11: 74AHC244; DIP-20_W7.62mm_Socket_LongPads

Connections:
+5V: U7.20 (VCC), U9.16 (VCC), U10.16 (VCC), U11.8 (1A3), U11.11 (2A3), U11.13 (2A2), U11.15 (2A1), U11.17 (2A0), U11.20 (VCC); also elsewhere on the board
/LO0: U10.4 (Za), U11.18 (1Y0); also elsewhere on the board
/LO1: U10.7 (Zb), U11.16 (1Y1); also elsewhere on the board
/LO2: U10.12 (Zc), U11.14 (1Y2); also elsewhere on the board
/LO3: U10.9 (Zd), U11.12 (1Y3); also elsewhere on the board
/LO4: U9.4 (Za), U11.3 (2Y0); also elsewhere on the board
/LO5: U9.7 (Zb), U11.5 (2Y1); also elsewhere on the board
/LO6: U9.12 (Zc), U11.7 (2Y2); also elsewhere on the board
/LO7: U9.9 (Zd), U11.9 (2Y3); also elsewhere on the board
CLOSE: U7.11 (Cp)
FETCH: U9.1 (S), U10.1 (S); also elsewhere on the board
GETPUT: U8.8; also elsewhere on the board
GND: U7.10 (GND), U9.8 (GND), U10.8 (GND), U11.10 (GND); also elsewhere on the board
GP0: U11.2 (1A0), U12.3
GP1: U11.4 (1A1), U12.6
GP2: U11.6 (1A2), U12.8
IB0: U12.1; also elsewhere on the board
IB1: U12.4; also elsewhere on the board
IB2: U12.9; also elsewhere on the board
unnamed: U7.12 (Q4), U9.2 (I0a)
unnamed: U7.15 (Q5), U9.5 (I0b)
unnamed: U7.16 (Q6), U9.14 (I0c)
unnamed: U7.19 (Q7), U9.11 (I0d)
unnamed: U7.2 (Q0), U10.2 (I0a)
unnamed: U7.5 (Q1), U10.5 (I0b)
unnamed: U7.6 (Q2), U10.14 (I0c)
unnamed: U7.9 (Q3), U10.11 (I0d)
unnamed: U1.1, U8.9, U9.15 (OE), U10.15 (OE)
unnamed: U1.2, U11.1 (1OE), U11.19 (2OE)
unnamed: U4.11, U12.2, U12.5, U12.10
O0: U7.3 (D0); also elsewhere on the board
O1: U7.4 (D1); also elsewhere on the board
O2: U7.7 (D2); also elsewhere on the board
O3: U7.8 (D3); also elsewhere on the board
O4: U7.13 (D4); also elsewhere on the board
O5: U7.14 (D5); also elsewhere on the board
O6: U7.17 (D6); also elsewhere on the board
O7: U7.18 (D7); also elsewhere on the board
OWN: U4.12, U8.1
PC0: U10.3 (I1a); also elsewhere on the board
PC1: U10.6 (I1b); also elsewhere on the board
PC2: U10.13 (I1c); also elsewhere on the board
PC3: U10.10 (I1d); also elsewhere on the board
PC4: U9.3 (I1a); also elsewhere on the board
PC5: U9.6 (I1b); also elsewhere on the board
PC6: U9.13 (I1c); also elsewhere on the board
PC7: U9.10 (I1d); also elsewhere on the board
RET: U4.13, U8.2; also elsewhere on the board
~RES: U7.1 (~Mr); also elsewhere on the board

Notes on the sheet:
Register at CLOSE (MO is a valid instruction, and O is the implied offset of Mx instructions)
Hard-wire so that OWN and RET reference L7 ("Owner")
IB 0-2 are the immediate offset for GET-PUT operations
Storage


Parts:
J1001, J1002, J1004, J1005, J1008, J1010, J1011, J1012, J1013, J1014, J1015, J1016, J1017, J1018, J1019, J1020: Conn_01x08_Pin; PinHeader_1x08_P2.54mm_Vertical

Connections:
+5V: J1008.1; also elsewhere on the board
DB0: J1001.1; also elsewhere on the board
DB1: J1001.2; also elsewhere on the board
DB2: J1001.3; also elsewhere on the board
DB3: J1001.4; also elsewhere on the board
DB4: J1001.5; also elsewhere on the board
DB5: J1001.6; also elsewhere on the board
DB6: J1001.7; also elsewhere on the board
DB7: J1001.8; also elsewhere on the board
DPH: J1008.7
EXIT: J1005.1
FETCH: J1004.7; also elsewhere on the board
FREE: J1010.2
GET: J1010.6; also elsewhere on the board
GETPUT: J1010.8; also elsewhere on the board
GND: J1008.2; also elsewhere on the board
HI0: J1012.1; also elsewhere on the board
HI1: J1012.2; also elsewhere on the board
HI2: J1012.3; also elsewhere on the board
HI3: J1012.4; also elsewhere on the board
HI4: J1012.5; also elsewhere on the board
HI5: J1012.6; also elsewhere on the board
HI6: J1012.7; also elsewhere on the board
HI7: J1012.8; also elsewhere on the board
IB0: J1002.1; also elsewhere on the board
IB1: J1002.2; also elsewhere on the board
IB2: J1002.3; also elsewhere on the board
IB3: J1002.4
IB4: J1002.5
IB5: J1002.6
IB6: J1002.7
IB7: J1002.8
IPH: J1011.5; also elsewhere on the board
JUMP: J1011.4
Lx_pre: J1005.4
MISO: J1004.5
MOSI: J1004.6
Mx_pre: J1005.7
NZFLAG_I: J1011.1
NZFLAG_R: J1011.2
Nx_pre_clean: J1005.5
O0: J1013.1; also elsewhere on the board
O1: J1013.2; also elsewhere on the board
O2: J1013.3; also elsewhere on the board
O3: J1013.4; also elsewhere on the board
O4: J1013.5; also elsewhere on the board
O5: J1013.6; also elsewhere on the board
O6: J1013.7; also elsewhere on the board
O7: J1013.8; also elsewhere on the board
PC0: J1014.1; also elsewhere on the board
PC1: J1014.2; also elsewhere on the board
PC2: J1014.3; also elsewhere on the board
PC3: J1014.4; also elsewhere on the board
PC4: J1014.5; also elsewhere on the board
PC5: J1014.6; also elsewhere on the board
PC6: J1014.7; also elsewhere on the board
PC7: J1014.8; also elsewhere on the board
PH0: J1008.4
PH1: J1008.5
PH2: J1011.6
PUT: J1010.7
RES: J1004.2
SCLK: J1004.3
SCROUNGE: J1010.4
ZFLAG_R: J1011.3
xA: J1016.2
xA_CARRY_OUT: J1011.7
xB: J1016.3
xC: J1016.8
xE: J1016.1
xF: J1016.7
xJ: J1016.4
xL_pre: J1005.3
xM_pre: J1005.6
xT: J1016.6
xW: J1016.5
xW_pre: J1005.8
~CLOSE: J1010.1
~COR: J1019.7
~DPH: J1008.6
~Dx: J1017.4
~GETD: J1020.1
~GETI: J1020.2
~GETO: J1020.4
~GETR: J1020.3
~IRQ: J1004.1
~Ix: J1017.6
~Lx: J1017.3
~Mx: J1017.2
~NOP: J1019.1
~Nx: J1017.1
~OWN: J1019.8; also elsewhere on the board
~PH0: J1008.3
~PH3: J1008.8; also elsewhere on the board
~PUTD: J1020.5
~PUTI: J1020.6
~PUTO: J1020.8
~PUTR: J1020.7
~Px: J1017.8
~RCOPY: J1010.3
~RES_DIRTY: J1004.8
~RES: J1004.4; also elsewhere on the board
~RET: J1019.6
~Rx: J1017.5
~SCH: J1019.5
~SCL: J1019.4
~SSI: J1019.2
~SSO: J1019.3
~SUBR: J1005.2
~Sx: J1017.7
~TRAP: J1010.5
~opc_ALU: J1018.3
~opc_DIRO: J1018.5
~opc_FIX: J1018.2
~opc_PAIR: J1018.6
~opc_SYS: J1018.1
~opc_TRAP: J1018.4
~xA_CARRY: J1011.8
~xD: J1015.4
~xI: J1015.6
~xL: J1015.3; also elsewhere on the board
~xM: J1015.2; also elsewhere on the board
~xO: J1015.1
~xP: J1015.8
~xR: J1015.5
~xS: J1015.7

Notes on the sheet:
Used in COUNTERS module and MEMORY module
Used in CDL module and in MEMORY module
Used in ALU module and in MEMORY module

Board: 2 copper layers, 38 parts (0 on the bottom side), 75 nets, no tracks yet.

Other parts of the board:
U2: KM62256CLP; DIP-28_W15.24mm_LongPads

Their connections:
+5V: U2.28 (VCC); also elsewhere on the board
/LO0: U2.10 (A0); also elsewhere on the board
/LO1: U2.9 (A1); also elsewhere on the board
/LO2: U2.8 (A2); also elsewhere on the board
/LO3: U2.7 (A3); also elsewhere on the board
/LO4: U2.6 (A4); also elsewhere on the board
/LO5: U2.5 (A5); also elsewhere on the board
/LO6: U2.4 (A6); also elsewhere on the board
/LO7: U2.3 (A7); also elsewhere on the board
/~IN_RAM: U2.20 (~CS); also elsewhere on the board
DB0: U2.11 (Q0); also elsewhere on the board
DB1: U2.12 (Q1); also elsewhere on the board
DB2: U2.13 (Q2); also elsewhere on the board
DB3: U2.15 (Q3); also elsewhere on the board
DB4: U2.16 (Q4); also elsewhere on the board
DB5: U2.17 (Q5); also elsewhere on the board
DB6: U2.18 (Q6); also elsewhere on the board
DB7: U2.19 (Q7); also elsewhere on the board
GND: U2.14 (GND); also elsewhere on the board
HI0: U2.25 (A8); also elsewhere on the board
HI1: U2.24 (A9); also elsewhere on the board
HI2: U2.21 (A10); also elsewhere on the board
HI3: U2.23 (A11); also elsewhere on the board
HI4: U2.2 (A12); also elsewhere on the board
HI5: U2.26 (A13); also elsewhere on the board
HI6: U2.1 (A14); also elsewhere on the board
unnamed 55: U2.22 (~OE); also elsewhere on the board
unnamed 56: U2.27 (~WE); also elsewhere on the board

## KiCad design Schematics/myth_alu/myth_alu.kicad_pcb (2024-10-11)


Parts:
C1003: C 100nF; C_Disc_D5.0mm_W2.5mm_P2.50mm
C1004: CP 10μF; CP_Radial_D6.3mm_P2.50mm
U1, U2: 74AHC273; DIP-20_W7.62mm_Socket_LongPads
U3, U5: SST39SF040; DIP-32_W15.24mm_Socket_LongPads
U4: 74HC04; DIP-14_W7.62mm_Socket_LongPads

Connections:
+5V: C1003.1, C1004.1, U1.20 (VCC), U2.20 (VCC), U3.31 (PGM), U3.32 (VCC), U5.31 (PGM), U5.32 (VCC); also elsewhere on the board
/ODEFER0: U2.2 (Q0), U3.27 (A8), U5.27 (A8)
/ODEFER1: U2.5 (Q1), U3.26 (A9), U5.26 (A9)
/ODEFER2: U2.6 (Q2), U3.23 (A10), U5.23 (A10)
/ODEFER3: U2.9 (Q3), U3.25 (A11), U5.25 (A11)
/ODEFER4: U2.12 (Q4), U3.4 (A12), U5.4 (A12)
/ODEFER5: U2.15 (Q5), U3.28 (A13), U5.28 (A13)
/ODEFER6: U2.16 (Q6), U3.29 (A14), U5.29 (A14)
/ODEFER7: U2.19 (Q7), U3.3 (A15), U5.3 (A15)
/RDEFER0: U1.2 (Q0), U3.12 (A0), U5.12 (A0)
/RDEFER1: U1.5 (Q1), U3.11 (A1), U5.11 (A1)
/RDEFER2: U1.6 (Q2), U3.10 (A2), U5.10 (A2)
/RDEFER3: U1.9 (Q3), U3.9 (A3), U5.9 (A3)
/RDEFER4: U1.12 (Q4), U3.8 (A4), U5.8 (A4)
/RDEFER5: U1.15 (Q5), U3.7 (A5), U5.7 (A5)
/RDEFER6: U1.16 (Q6), U3.6 (A6), U5.6 (A6)
/RDEFER7: U1.19 (Q7), U3.5 (A7), U5.5 (A7)
CLOSE: U1.11 (Cp), U2.11 (Cp)
DB0: U3.13 (D0), U5.13 (D0); also elsewhere on the board
DB1: U3.14 (D1), U5.14 (D1); also elsewhere on the board
DB2: U3.15 (D2), U5.15 (D2); also elsewhere on the board
DB3: U3.17 (D3), U5.17 (D3); also elsewhere on the board
DB4: U3.18 (D4), U5.18 (D4); also elsewhere on the board
DB5: U3.19 (D5), U5.19 (D5); also elsewhere on the board
DB6: U3.20 (D6), U5.20 (D6); also elsewhere on the board
DB7: U3.21 (D7), U5.21 (D7); also elsewhere on the board
GND: C1003.2, C1004.2, U1.10 (GND), U2.10 (GND), U3.16 (GND), U5.16 (GND); also elsewhere on the board
IB0: U3.2 (A16), U5.2 (A16); also elsewhere on the board
IB1: U3.30 (A17), U5.30 (A17); also elsewhere on the board
IB2: U3.1 (A18), U5.1 (A18); also elsewhere on the board
IB3: U3.22 (CE), U4.1; also elsewhere on the board
O0: U2.3 (D0); also elsewhere on the board
O1: U2.4 (D1); also elsewhere on the board
O2: U2.7 (D2); also elsewhere on the board
O3: U2.8 (D3); also elsewhere on the board
O4: U2.13 (D4); also elsewhere on the board
O5: U2.14 (D5); also elsewhere on the board
O6: U2.17 (D6); also elsewhere on the board
O7: U2.18 (D7); also elsewhere on the board
R0: U1.3 (D0); also elsewhere on the board
R1: U1.4 (D1); also elsewhere on the board
R2: U1.7 (D2); also elsewhere on the board
R3: U1.8 (D3); also elsewhere on the board
R4: U1.13 (D4); also elsewhere on the board
R5: U1.14 (D5); also elsewhere on the board
R6: U1.17 (D6); also elsewhere on the board
R7: U1.18 (D7); also elsewhere on the board
~IB3: U4.2, U5.22 (CE)
~RES: U1.1 (~Mr), U2.1 (~Mr); also elsewhere on the board
~opc_ALU: U3.24 (OE), U5.24 (OE); also elsewhere on the board

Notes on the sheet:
BLUR3 LUT ROM layout: 2x8 maps @256x256
ALU opcode
NOTE: After resetting annotations, redo an additional annotation step in the "Pin headers" sheet, renumbering ("current sheet only") from 1000 onwards. This ensures that the Pin Headers sheet, which is shared between the individual boards, has consistent unit-labels in them.
0 CLR ("Clear" / R:=0) 1 IDO ("Identity O" / R:=O) 2 OCR ("Ones Complement R" / R:=~R) 3 OCO ("Ones Complement O" / R:=~O) 4 SLR ("Shift left R" / R:=R<<1) 5 SLO ("Shift left O" / R:=O<<1) 6 SRR ("Shift right R" / R:=R>>1) 7 SRO ("Shift right O" / R:=O>>1) 8 AND (R:=R&O) 9 IOR (R:=R|O) 10 EOR (R:=R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
ALU
ROM1
ALU Instructions
ROM2


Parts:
C1011: C 100nF; C_Disc_D5.0mm_W2.5mm_P2.50mm
C1012: CP 10μF; CP_Radial_D6.3mm_P2.50mm
U6: 74LS21; DIP-14_W7.62mm_Socket_LongPads
U7: 74LS08; DIP-14_W7.62mm_Socket_LongPads
U8: 74AHC273; DIP-20_W7.62mm_Socket_LongPads
U9: 4078; DIP-14_W7.62mm_Socket_LongPads
U10: 74AHC244; DIP-20_W7.62mm_Socket_LongPads

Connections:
+5V: C1011.1, C1012.1, U8.20 (VCC), U9.14 (Vdd), U10.20 (VCC); also elsewhere on the board
DB0: U8.3 (D0), U10.18 (1Y0); also elsewhere on the board
DB1: U8.4 (D1), U10.16 (1Y1); also elsewhere on the board
DB2: U8.7 (D2), U10.14 (1Y2); also elsewhere on the board
DB3: U8.8 (D3), U10.12 (1Y3); also elsewhere on the board
DB4: U8.13 (D4), U10.3 (2Y0); also elsewhere on the board
DB5: U8.14 (D5), U10.5 (2Y1); also elsewhere on the board
DB6: U8.17 (D6), U10.7 (2Y2); also elsewhere on the board
DB7: U8.18 (D7), U10.9 (2Y3); also elsewhere on the board
GND: C1011.2, C1012.2, U8.10 (GND), U9.7 (Vss), U10.10 (GND); also elsewhere on the board
NZFLAG_R: U9.1; also elsewhere on the board
unnamed: U6.6, U7.4
unnamed: U7.6, U8.11 (Cp)
unnamed: U7.3, U10.1 (1OE), U10.19 (2OE)
PH3: U7.5
R0: U8.2 (Q0), U9.2, U10.2 (1A0); also elsewhere on the board
R1: U8.5 (Q1), U9.3, U10.4 (1A1); also elsewhere on the board
R2: U8.6 (Q2), U9.4, U10.6 (1A2); also elsewhere on the board
R3: U8.9 (Q3), U9.5, U10.8 (1A3); also elsewhere on the board
R4: U8.12 (Q4), U9.9, U10.17 (2A0); also elsewhere on the board
R5: U8.15 (Q5), U9.10, U10.15 (2A1); also elsewhere on the board
R6: U8.16 (Q6), U9.11, U10.13 (2A2); also elsewhere on the board
R7: U8.19 (Q7), U9.12, U10.11 (2A3); also elsewhere on the board
ZFLAG_R: U9.13; also elsewhere on the board
~GETR: U6.2; also elsewhere on the board
~PUTR: U7.1; also elsewhere on the board
~RES: U8.1 (~Mr); also elsewhere on the board
~Rx: U7.2; also elsewhere on the board
~opc_ALU: U6.1; also elsewhere on the board
~opc_FIX: U6.4; also elsewhere on the board
~xR: U6.5; also elsewhere on the board

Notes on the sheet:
Zero detection
R(esult) Register
PIN 1 (non-inverted output) was missing in KiCAD symbol
All delayed to PH3


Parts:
C1001: C 100nF; C_Disc_D5.0mm_W2.5mm_P2.50mm
C1002: CP 10μF; CP_Radial_D6.3mm_P2.50mm
U11, U12: 74HC283; DIP-16_W7.62mm_Socket_LongPads
U13, U14: 74HC157; DIP-16_W7.62mm_Socket_LongPads
U15: 74LS32; DIP-14_W7.62mm_Socket_LongPads
U16: 74AHC273; DIP-20_W7.62mm_Socket_LongPads
U17: 74AHC244; DIP-20_W7.62mm_Socket_LongPads

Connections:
+5V: C1001.1, C1002.1, U11.16 (VCC), U12.16 (VCC), U13.16 (VCC), U14.16 (VCC), U16.20 (VCC), U17.20 (VCC); also elsewhere on the board
DB0: U11.6 (B1), U13.2 (I0a), U17.18 (1Y0); also elsewhere on the board
DB1: U11.2 (B2), U13.5 (I0b), U17.16 (1Y1); also elsewhere on the board
DB2: U11.15 (B3), U13.11 (I0c), U17.14 (1Y2); also elsewhere on the board
DB3: U11.11 (B4), U13.14 (I0d), U17.12 (1Y3); also elsewhere on the board
DB4: U12.6 (B1), U14.2 (I0a), U17.3 (2Y0); also elsewhere on the board
DB5: U12.2 (B2), U14.5 (I0b), U17.5 (2Y1); also elsewhere on the board
DB6: U12.15 (B3), U14.11 (I0c), U17.7 (2Y2); also elsewhere on the board
DB7: U12.11 (B4), U14.14 (I0d), U17.9 (2Y3); also elsewhere on the board
GETO: U15.2
GND: C1001.2, C1002.2, U11.7 (C0), U11.8 (GND), U12.8 (GND), U13.8 (GND), U13.15 (E), U14.8 (GND), U14.15 (E), U16.10 (GND), U17.10 (GND); also elsewhere on the board
unnamed: U11.9 (C4), U12.7 (C0)
unnamed: U11.4 (S1), U13.3 (I1a)
unnamed: U11.1 (S2), U13.6 (I1b)
unnamed: U11.13 (S3), U13.10 (I1c)
unnamed: U11.10 (S4), U13.13 (I1d)
unnamed: U12.4 (S1), U14.3 (I1a)
unnamed: U12.1 (S2), U14.6 (I1b)
unnamed: U12.13 (S3), U14.10 (I1c)
unnamed: U12.10 (S4), U14.13 (I1d)
unnamed: U13.4 (Za), U16.3 (D0)
unnamed: U13.7 (Zb), U16.4 (D1)
unnamed: U13.9 (Zc), U16.7 (D2)
unnamed: U13.12 (Zd), U16.8 (D3)
unnamed: U14.4 (Za), U16.13 (D4)
unnamed: U14.7 (Zb), U16.14 (D5)
unnamed: U14.9 (Zc), U16.17 (D6)
unnamed: U14.12 (Zd), U16.18 (D7)
unnamed: U15.3, U15.5
unnamed: U15.6, U16.11 (Cp)
O0: U16.2 (Q0), U17.2 (1A0); also elsewhere on the board
O1: U16.5 (Q1), U17.4 (1A1); also elsewhere on the board
O2: U16.6 (Q2), U17.6 (1A2); also elsewhere on the board
O3: U16.9 (Q3), U17.8 (1A3); also elsewhere on the board
O4: U16.12 (Q4), U17.17 (2A0); also elsewhere on the board
O5: U16.15 (Q5), U17.15 (2A1); also elsewhere on the board
O6: U16.16 (Q6), U17.13 (2A2); also elsewhere on the board
O7: U16.19 (Q7), U17.11 (2A3); also elsewhere on the board
ODEFER0: U11.5 (A1)
ODEFER1: U11.3 (A2)
ODEFER2: U11.14 (A3)
ODEFER3: U11.12 (A4)
ODEFER4: U12.5 (A1)
ODEFER5: U12.3 (A2)
ODEFER6: U12.14 (A3)
ODEFER7: U12.12 (A4)
xA: U13.1 (S), U14.1 (S), U15.1; also elsewhere on the board
xA_CARRY_OUT: U12.9 (C4); also elsewhere on the board
xO: U15.4
~PUTO: U17.1 (1OE), U17.19 (2OE); also elsewhere on the board
~RES: U16.1 (~Mr); also elsewhere on the board

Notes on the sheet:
xA adds DB val to O and carries over into D
ADDER
(OFFSET) Register

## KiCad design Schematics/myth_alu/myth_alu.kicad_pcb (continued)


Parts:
J1001, J1002, J1004, J1005, J1008, J1010, J1011, J1012, J1013, J1014, J1015, J1016, J1017, J1018, J1019, J1020: Conn_01x08_Pin; PinHeader_1x08_P2.54mm_Vertical

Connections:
+5V: J1008.1; also elsewhere on the board
DB0: J1001.1; also elsewhere on the board
DB1: J1001.2; also elsewhere on the board
DB2: J1001.3; also elsewhere on the board
DB3: J1001.4; also elsewhere on the board
DB4: J1001.5; also elsewhere on the board
DB5: J1001.6; also elsewhere on the board
DB6: J1001.7; also elsewhere on the board
DB7: J1001.8; also elsewhere on the board
DPH: J1008.7
EXIT: J1005.1
FETCH: J1004.7
FREE: J1010.2
GET: J1010.6
GETPUT: J1010.8
GND: J1008.2; also elsewhere on the board
HI0: J1012.1
HI1: J1012.2
HI2: J1012.3
HI3: J1012.4
HI4: J1012.5
HI5: J1012.6
HI6: J1012.7
HI7: J1012.8
IB0: J1002.1; also elsewhere on the board
IB1: J1002.2; also elsewhere on the board
IB2: J1002.3; also elsewhere on the board
IB3: J1002.4; also elsewhere on the board
IB4: J1002.5
IB5: J1002.6
IB6: J1002.7
IB7: J1002.8
IPH: J1011.5
JUMP: J1011.4
Lx_pre: J1005.4
MISO: J1004.5
MOSI: J1004.6
Mx_pre: J1005.7
NZFLAG_I: J1011.1
NZFLAG_R: J1011.2; also elsewhere on the board
Nx_pre_clean: J1005.5
O0: J1013.1; also elsewhere on the board
O1: J1013.2; also elsewhere on the board
O2: J1013.3; also elsewhere on the board
O3: J1013.4; also elsewhere on the board
O4: J1013.5; also elsewhere on the board
O5: J1013.6; also elsewhere on the board
O6: J1013.7; also elsewhere on the board
O7: J1013.8; also elsewhere on the board
PC0: J1014.1
PC1: J1014.2
PC2: J1014.3
PC3: J1014.4
PC4: J1014.5
PC5: J1014.6
PC6: J1014.7
PC7: J1014.8
PH0: J1008.4
PH1: J1008.5
PH2: J1011.6
PUT: J1010.7
RES: J1004.2
SCLK: J1004.3
SCROUNGE: J1010.4
ZFLAG_R: J1011.3; also elsewhere on the board
xA: J1016.2; also elsewhere on the board
xA_CARRY_OUT: J1011.7; also elsewhere on the board
xB: J1016.3
xC: J1016.8
xE: J1016.1
xF: J1016.7
xJ: J1016.4
xL_pre: J1005.3
xM_pre: J1005.6
xT: J1016.6
xW: J1016.5
xW_pre: J1005.8
~CLOSE: J1010.1
~COR: J1019.7
~DPH: J1008.6
~Dx: J1017.4
~GETD: J1020.1
~GETI: J1020.2
~GETO: J1020.4
~GETR: J1020.3; also elsewhere on the board
~IRQ: J1004.1
~Ix: J1017.6
~Lx: J1017.3
~Mx: J1017.2
~NOP: J1019.1
~Nx: J1017.1
~OWN: J1019.8
~PH0: J1008.3
~PH3: J1008.8
~PUTD: J1020.5
~PUTI: J1020.6
~PUTO: J1020.8; also elsewhere on the board
~PUTR: J1020.7; also elsewhere on the board
~Px: J1017.8
~RCOPY: J1010.3
~RES_DIRTY: J1004.8
~RES: J1004.4; also elsewhere on the board
~RET: J1019.6
~Rx: J1017.5; also elsewhere on the board
~SCH: J1019.5
~SCL: J1019.4
~SSI: J1019.2
~SSO: J1019.3
~SUBR: J1005.2
~Sx: J1017.7
~TRAP: J1010.5
~opc_ALU: J1018.3; also elsewhere on the board
~opc_DIRO: J1018.5
~opc_FIX: J1018.2; also elsewhere on the board
~opc_PAIR: J1018.6
~opc_SYS: J1018.1
~opc_TRAP: J1018.4
~xA_CARRY: J1011.8
~xD: J1015.4
~xI: J1015.6
~xL: J1015.3
~xM: J1015.2
~xO: J1015.1
~xP: J1015.8
~xR: J1015.5; also elsewhere on the board
~xS: J1015.7

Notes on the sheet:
Used in COUNTERS module and MEMORY module
Used in CDL module and in MEMORY module
Used in ALU module and in MEMORY module


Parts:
C1005, C1007, C1008, C1009, C1013: C 100nF; C_Disc_D5.0mm_W2.5mm_P2.50mm
C1006: CP 10μF; CP_Radial_D6.3mm_P2.50mm
U4: 74HC04; DIP-14_W7.62mm_Socket_LongPads
U6: 74LS21; DIP-14_W7.62mm_Socket_LongPads
U7: 74LS08; DIP-14_W7.62mm_Socket_LongPads
U15: 74LS32; DIP-14_W7.62mm_Socket_LongPads
U18: 4075; DIP-14_W7.62mm_Socket_LongPads

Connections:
+5V: C1005.1, C1006.1, C1007.1, C1008.1, C1009.1, C1013.1, U4.14 (VCC), U6.14 (VCC), U7.14 (VCC), U15.14 (VCC), U18.14 (VDD); also elsewhere on the board
GND: C1005.2, C1006.2, C1007.2, C1008.2, C1009.2, C1013.2, U4.3, U4.5, U4.7 (GND), U4.9, U4.11, U4.13, U6.7 (GND), U6.9, U6.10, U6.12, U6.13, U7.7 (GND), U7.9, U7.10, U7.12, U7.13, U15.7 (GND), U15.9, U15.10, U15.12, U15.13, U18.3, U18.4, U18.5, U18.7 (VSS), U18.11, U18.12, U18.13; also elsewhere on the board


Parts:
C1010: C 100nF; C_Disc_D5.0mm_W2.5mm_P2.50mm
C1014: CP 10μF; CP_Radial_D6.3mm_P2.50mm
U18: 4075; DIP-14_W7.62mm_Socket_LongPads
U19: 74HC157; DIP-16_W7.62mm_Socket_LongPads
U20, U21: 74HC283; DIP-16_W7.62mm_Socket_LongPads
U22: 74AHC574; DIP-20_W7.62mm_Socket_LongPads

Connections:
+5V: C1010.1, C1014.1, U19.11 (I0c), U19.16 (VCC), U20.16 (VCC), U21.16 (VCC), U22.20 (VCC); also elsewhere on the board
DB0: U22.19 (Q0); also elsewhere on the board
DB1: U22.18 (Q1); also elsewhere on the board
DB2: U22.17 (Q2); also elsewhere on the board
DB3: U22.16 (Q3); also elsewhere on the board
DB4: U22.15 (Q4); also elsewhere on the board
DB5: U22.14 (Q5); also elsewhere on the board
DB6: U22.13 (Q6); also elsewhere on the board
DB7: U22.12 (Q7); also elsewhere on the board
GND: C1010.2, C1014.2, U19.2 (I0a), U19.5 (I0b), U19.8 (GND), U19.14 (I0d), U19.15 (E), U20.7 (C0), U20.8 (GND), U21.8 (GND), U22.10 (GND); also elsewhere on the board
IB0: U18.1, U19.3 (I1a); also elsewhere on the board
IB1: U18.2, U19.6 (I1b); also elsewhere on the board
IB2: U18.8, U19.10 (I1c), U19.13 (I1d); also elsewhere on the board
unnamed: U18.9, U19.1 (S)
unnamed: U19.4 (Za), U20.5 (A1)
unnamed: U19.7 (Zb), U20.3 (A2)
unnamed: U19.9 (Zc), U20.14 (A3)
unnamed: U19.12 (Zd), U20.12 (A4), U21.3 (A2), U21.5 (A1), U21.12 (A4), U21.14 (A3)
unnamed: U20.9 (C4), U21.7 (C0)
unnamed: U20.4 (S1), U22.2 (D0)
unnamed: U20.1 (S2), U22.3 (D1)
unnamed: U20.13 (S3), U22.4 (D2)
unnamed: U20.10 (S4), U22.5 (D3)
unnamed: U21.4 (S1), U22.6 (D4)
unnamed: U21.1 (S2), U22.7 (D5)
unnamed: U21.13 (S3), U22.8 (D6)
unnamed: U21.10 (S4), U22.9 (D7)
R0: U20.6 (B1); also elsewhere on the board
R1: U20.2 (B2); also elsewhere on the board
R2: U20.15 (B3); also elsewhere on the board
R3: U20.11 (B4); also elsewhere on the board
R4: U21.6 (B1); also elsewhere on the board
R5: U21.2 (B2); also elsewhere on the board
R6: U21.15 (B3); also elsewhere on the board
R7: U21.11 (B4); also elsewhere on the board
opc_FIX: U22.11 (Cp)
~opc_FIX: U22.1 (OE); also elsewhere on the board

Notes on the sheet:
ADDER
Edge triggered, PHA1 / DPH!
Else sign extend bit 2
R-Fix
Hard-coded: if bits 0-2 all 0 replace by 4
0000 => 0100 +4 P4 (R PLUS 4) 0001 +1 P1 0010 +2 P2 0011 +3 P3 1100 -4 M4 (R MINUS 4) 1101 -3 M3 1110 -2 M2 1111 -1 M1

Board: 2 copper layers, 52 parts (0 on the bottom side), 96 nets, no tracks yet.

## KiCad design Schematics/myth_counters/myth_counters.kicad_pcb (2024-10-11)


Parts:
C1001: C 100nF; C_Disc_D5.0mm_W2.5mm_P2.50mm
C1002: CP 10μF; CP_Radial_D6.3mm_P2.50mm
U1, U2: 74LS08; DIP-14_W7.62mm_LongPads
U3: 4072; DIP-14_W7.62mm_LongPads
U4: 74HC74; DIP-14_W7.62mm_LongPads
U5: 74HC02; DIP-14_W7.62mm_LongPads
U6: 74HC00; DIP-14_W7.62mm_LongPads
U7: 74LS32; DIP-14_W7.62mm_LongPads
U8, U9: 74HC193; DIP-16_W7.62mm_Socket_LongPads

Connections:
+5V: C1001.1, C1002.1, U4.2 (D), U8.4 (DOWN), U8.16 (VCC), U9.4 (DOWN), U9.16 (VCC); also elsewhere on the board
CLOSE: U2.4, U5.8
GND: C1001.2, C1002.2, U4.3 (C), U8.8 (GND), U9.8 (GND); also elsewhere on the board
JIN0: U8.15 (A); also elsewhere on the board
JIN1: U8.1 (B); also elsewhere on the board
JIN2: U8.10 (C); also elsewhere on the board
JIN3: U8.9 (D); also elsewhere on the board
JIN4: U9.15 (A); also elsewhere on the board
JIN5: U9.1 (B); also elsewhere on the board
JIN6: U9.10 (C); also elsewhere on the board
JIN7: U9.9 (D); also elsewhere on the board
JUMP: U2.13, U3.1; also elsewhere on the board
LFETCH: U5.9
NZFLAG_I: U1.1; also elsewhere on the board
NZFLAG_R: U1.4; also elsewhere on the board
unnamed: U1.3, U3.2
unnamed: U1.6, U3.4
unnamed: U2.2, U6.3
unnamed: U2.6, U7.4
unnamed: U2.8, U3.5
unnamed: U2.11, U6.1
unnamed: U2.5, U4.5 (Q)
unnamed: U7.6, U8.14 (CLR), U9.14 (CLR)
unnamed: U5.10, U8.5 (UP)
unnamed: U8.12 (~CO), U9.5 (UP)
unnamed: U2.3, U8.11 (~LOAD), U9.11 (~LOAD)
PC0: U8.3 (QA); also elsewhere on the board
PC1: U8.2 (QB); also elsewhere on the board
PC2: U8.6 (QC); also elsewhere on the board
PC3: U8.7 (QD); also elsewhere on the board
PC4: U9.3 (QA); also elsewhere on the board
PC5: U9.2 (QB); also elsewhere on the board
PC6: U9.6 (QC); also elsewhere on the board
PC7: U9.7 (QD); also elsewhere on the board
PH3: U6.2
RES: U7.5; also elsewhere on the board
ZFLAG_R: U2.9; also elsewhere on the board
xB: U2.12; also elsewhere on the board
xF: U2.10; also elsewhere on the board
xJ: U3.3; also elsewhere on the board
xT: U1.5; also elsewhere on the board
xW_pre: U1.2; also elsewhere on the board
~COR: U2.1; also elsewhere on the board
~PH0: U4.1 (~R); also elsewhere on the board
~SUBR: U4.4 (~S); also elsewhere on the board

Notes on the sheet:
Jump always
(PC Program Counter)
Branching
Jump if R zero
J (the program counter) is cleared/set to 0 during TRAP or CALL. Execution starts at offset zero, the "head" of the destination page.
NOTE: After resetting annotations, redo an additional annotation step in the "Pin headers" sheet, renumbering ("current sheet only") from 1000 onwards. This ensures that the Pin Headers sheet, which is shared between the individual boards, has consistent unit-labels in them.
Delay ~{SUBR} until CLOSE
Jump if R not zero
Jump while loop counter register I not zero (decrements I)


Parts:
U16, U17: 74HC283; DIP-16_W7.62mm_Socket_LongPads
U18, U19, U20, U21: 74HC157; DIP-16_W7.62mm_Socket_LongPads
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

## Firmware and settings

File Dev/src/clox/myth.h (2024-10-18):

#ifndef __MYTH_H__
#define __MYTH_H__ 1


/* Emulation routines for Sonne 8 micro-controller Rev. Myth/LOX
   Author: mim@ok-schalter.de (Michael/Dosflange@github)
    */

#include <u.h>
#include <libc.h>

struct myth_vm /*Complete machine state including all RAM*/
{
        uchar ram[256][256]; /*MemoryByte[page][offset]*/

        uchar e_old; /*Device ENABLE register previous value - set by VM */
        uchar e_new; /*Device ENABLE register current value - set by VM */

        uchar sclk; /*Serial clock state bit - set by VM*/
        uchar miso; /*Serial input line state bit - set by PERIPHERY*/
        uchar mosi; /*Serial output line state bit - set by VM*/
        uchar sir;  /*Serial input register - set by VM*/
        uchar sor;  /*Serial output register - set by VM*/

        uchar pir;  /*Parallel input register - set by PERIPHERY*/
        uchar por;  /*Parallel output register - set by VM*/

        uchar r;    /*Result*/
        uchar o;    /*Offset*/
        uchar i;    /*Inner Counter*/
        uchar pc;   /*Program Counter*/

        uchar co;   /*Coroutine Latch*/
        uchar c;    /*Code Page Index*/
        uchar g;    /*Global Page Index*/
        uchar l;    /*Local Page Index*/

        uchar scrounge; /*Set by VM if scrounge opcode executed, else zero*/
};

/*
  RAM[][] is organised as [page][offset];
  
  E is the enable register. The low-order nybble is called
  the low-order selector, and it encodes device select
  signals LS0-15. Device LS0 is the null device.
  The high-order nybble is called the high-order selector,
  and it encodes device select signals HS0-15.
  Device HS0 is the null device.

  SCLK is the CPU driven serial clock state bit.
  MISO is the device driven serial data input bit.
  MOSI is the CPU driven serial data output bit.
  SIR is the serialisation byte input register.
  SOR is the serialisation byte output register.
  PIR is the parallel bus input register.
  POR is the parallel bus output register.
  
  R is the result register receiving ALU results and
  this register is also one of the two ALU input operands.
  
  O is the implied offset register for all memory operations
  outside of instruction or literal fetching, and this
  register is also one of the two ALU input operands.

  I is the inner counter register. It can function as
  a hardware loop counter but is also used for storing
  the return address during function calls.

  PC is the program counter, which for this CPU means
  that it contains the offset within the current code page.
  This register is hidden.

  CO is the coroutine register. It contains a copy of the
  code page index that is strategically updated.
  This register is hidden.

  C contains the code page index. Instruction fetch always
  occurs at RAM[C][PC].

  G is the global page index register.
  It contains the implied
  page index for memory operations using the M-prefix.

  L is the local page index register.
  It contains the implied
  page index for memory operations using the L-prefix.
  This page index represents the stack frame during
  function calls. This register is hidden.
*/


void myth_reset(struct myth_vm *vm);
void myth_step(struct myth_vm *vm);

static uchar fetch(struct myth_vm *vm);
static uchar srcval(struct myth_vm *vm, uchar srcreg);
static int scrounge(uchar opcode);
static void pair(struct myth_vm *vm, uchar opcode);
static void giro(struct myth_vm *vm, uchar opcode);
static void trap(struct myth_vm *vm, uchar opcode);
static void alu(struct myth_vm *vm, uchar opcode);
static void fix(struct myth_vm *vm, uchar opcode);
static void sys(struct myth_vm *vm, uchar opcode);
static void call(struct myth_vm *vm, uchar dstpage);


/* The 'REGx' notation means: REG into (something)
   i.e. REG is a source
*/

#define FETCHx 0 /*from code literal (NUMBER)*/
#define MGx 1 /*from MEMORY via DATA page index*/
#define MLx 2 /*from MEMORY via LOCAL page index*/
#define Gx 3 /*from GLOBAL register*/
#define Rx 4 /*from RESULT register*/
#define Ix 5 /*from DATA page register*/
#define Sx 6 /*from SERIAL input*/
#define Px 7 /*from PARALLEL input*/


/* The 'xREG' notation means: (something) into REG
   i.e. REG is a destination
*/

#define xO 0 /*to OFFSET register*/
#define xMG 1 /*to MEMORY via DATA page index*/
#define xML 2 /*to MEMORY via LOCAL page index*/
#define xG 3 /*to GLOBAL register*/
#define xR 4 /*to RESULT register*/
#define xI 5 /*to INNER register*/
#define xS 6 /*to SERIAL output*/
#define xP 7 /*to PARALLEL output*/

#define xE 8 /*to ENABLE register*/
#define xSKIP 9 /*to O and D (ADD byte to 16-bit register pair)*/
#define xNEAR 10 /*to DATA page register*/
#define xJUMP 11 /*write JUMP program counter*/
#define xJITD 12 /*write JUMP WHILE I not zero, decrement I*/
#define xJRT 13 /*write JUMP if R not zero*/
#define xJRF 14 /*write JUMP if R zero*/
#define xCALL 15 /*write CALL page index*/


/*ALU Instructions
*/

#define CLR 0 /*Clear (value 0)*/
#define IDO 1 /*Identity O*/
#define OCR 2 /*Ones' complement of R*/
#define OCO 3 /*Ones' complement of O*/
#define SLR 4 /*Shift left R*/
#define SLO 5 /*Shift left O*/
#define SRR 6 /*Shift right R*/
#define SRO 7 /*Shift right O*/
#define AND 8 /*R AND O*/
#define IOR 9 /*R OR O*/
#define EOR 10 /*R XOR O*/
#define ADD 11 /*R + O*/
#define CAR 12 /*Carry of R + O (0 or 1)*/
#define RLO 13 /*255 if R<O else 0*/
#define REO 14 /*255 if R=O else 0*/
#define RGO 15 /*255 if R>O else 0*/


/*SYS Instructions
*/

#define NOP 0 /*No Operation*/
#define SSI 1 /*Serial Shift In*/
#define SSO 2 /*Serial Shift Out*/
#define SCL 3 /*Set serial Clock Low*/
#define SCH 4 /*Set serial Clock High*/
#define RET 5 /*Return to L7:I from nested call*/
#define COR 6 /*Coroutine jump to G:I*/
#define OWN 7 /*Save code page index in L7*/


/*FIX Instructions
*/

#define P4 0 /*R PLUS 4*/
#define P1 1
#define P2 2
#define P3 3
#define M4 4 /*R MINUS 4*/
#define M3 5
#define M2 6
#define M1 7

#define GIRO_BASE_OFFSET 0xF8 /*Local-page offset used by DIRO instructions*/

void
myth_reset(struct myth_vm *vm) /*Initialise machine state*/
{
        memset(vm->ram, 0, 256*256);

        vm->e_old = 0; /*Clear signal edges*/
        vm->e_new = 0; /*Deselect all devices*/

        vm->sclk = 0;
        vm->miso = 0;
        vm->mosi = 0;
        vm->sir = 0;
        vm->sor = 0;

        vm->pir = 0;
        vm->por = 0;

        vm->r = 0;
        vm->o = 0;
        vm->i = 0;
        vm->pc = 0;

        vm->co = 0;
        vm->c = 0;
        vm->g = 0;
        vm->l = 0;

        vm->scrounge = 0;
}
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

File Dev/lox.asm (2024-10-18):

(LOX Bootstrap Firmware for Myth micro-controller)
(Author: mim@ok-schalter.de - Michael/Dosflange@github)

;******* ********************************************************************
P[COLD]0 (Instruction-fetch on RESET and on IRQ begins here)
;******* ********************************************************************

 (Lox has copied its null-separated command line arguments into 7F80h-7FEFh.)

      O[callArgs] nc Interpret
                  nc NextArg
                  nt <callArgs  (Repeat until R zero - end of list)

        END (Application specific opcode END exits LOX.)


;************** *************************************************************
P[DemoCode]1Fh (User code, invoke with command line argument 'demo')
;************** *************************************************************

        (Write your code below here, assemble this file as described
         in the README.1st, and then run 'lox demo' at the
         command line.)

        (How does this code get invoked?
         In your editor, search this file for 'VTOPPAGE'. This will
         take you to the last entry of the 'dictionary'. You will
         see that the last entry contains the string 'demo' and a
         pointer to this code here.
         The 'Interpret' function called at the top of the file
         matches the 'dictionary' entries against the command line
         arguments received from 'lox'.
         When it finds a matching entry, it jumps to the address
         encoded in the dictionary.)

         C[StrDemo]6  (Example of a defined constant)
   
         nr StrDemo   (Print message 6 - 'Demo')
         nc PrMsg

         ; Your code here

         6i RET

;************** *************************************************************
P[Interpret]20h (Look up a command name string in the dictionary and run it)
;************** *************************************************************

         OWN, i6
         ng LOXBASE     (Page where the argument strings are stored)
         no LOXBASE.ARG (Offset of variable which points to the current one)
         mo
         nc VSrch       (Load offset of search string and look it up)
         nt >InterpSucc

         (Look-up failed)
         nr 1, nc PrMsg   (Prints 'not found')
         6i, RET

      O[InterpSucc]

         (Look-up succeeded, check correct type of entry)

         o0    (Save target offset)
         no 2  (Compare to type 2 - CMD)
         REO   (Target type still in R)

         nf >InterpRFail (Skip if type byte didn't match)

         (Jump to CMD)
         0i    (Restore target offset)
         gr
         COR

      O[InterpRFail]

         nr 2, nc PrMsg  (Prints 'not a command')
         6i, RET


;****** *********************************************************************
P[Mul8]+  (Multiplies R by O result in R and O)
;****** *********************************************************************

         OWN i6        (Save return pointer in L7/L6)
         o1            (Multiplicand into L1, turns into low order result)
         r0            (Multiplier into L0)
         CLR r2        (Clear high-order result, copy to L2)
         ni 07h        (Initilise loop counter, 8 bits)

      O[Mul8Loop]
      
         no 01h           (Bit mask for LSB)
         1r AND           (Check if multiplicand has LSB set)
         nf >Mul8Skip     (Skip if not)
         0r 2o ADD r2     (Add multiplier to high order result)

      O[Mul8Skip]

         no 01h           (Bit mask for LSB)
         2r AND r3        (Flag whether high order LSB is set)
         1r SRR r1        (Shift low-order result right)
         2r SRR r2        (Shift high-order result right)

         3r nf >Mul8Done  (Check flag from earlier - HO LSB set?)
         nr 80h           (Bit mask for MSB)
         1o IOR r1        (Handle shift-result carry bit into MSB)

      O[Mul8Done]

         nw <Mul8Loop
         1o               (Result low-order)
         2r               (Result high-order)
         6i RET           (Restore return pointer from L7/L6)


;********* ******************************************************************
P[DivMod8]+  (Divide R by G, return quotient in R, remainder in G)
;********* ******************************************************************

         OWN i6
         r0                  (Save dividend)
         o1                  (Save divisor)
         ni 00h              (Initialise shift counter to number of positions
                              of first 1-bit)

         nr 00h r3           (Initialise quotient to zero)
         1r nf >DivMod8Quit  (Skip if divisor is zero)
         nr 80h r5           (Set MSB mask)

      O[DivMod8Sh]

         5r                  (Shift divisor left until
                              first 1 bit at MSB position)
         1o AND              (Compare to mask)
         nt >DivMod8Div      (Exit shift loop once MSB set)
         SLO                 (Shift divisor)
         r1                  (Store result)
         ir P1 ri            (Increment shift counter)
         nj <DivMod8Sh

      O[DivMod8Div]

         3o SLO              (Shift quotient left)
         r3                  (Store shifted quotient for latter)
         1r OCR P1 r4        (Negate divisor and save it)
         0o CAR              (Get dividend and see if adding
                              the negated divisor produces a borrow bit)
         
         nf >DivMod8Rep      (If not, don't accept the subtraction)
         
         4r ADD r0           (Accept subtraction result, store to dividend)
         3r P1 r3            (Increment quotient)

      O[DivMod8Rep]

         1r SRR r1           (Shift divisor right for next subtraction)
         nw <DivMod8Div      (Branch back if not zero, decrement I counter)

      O[DivMod8Quit]

         3r 0o           (Save quotient and remainder)
         6i RET


;************ ***************************************************************
P[SkipToNULL]+
;************ ***************************************************************

         OWN i6  (Advance string pointer G/O to next NULL char)

      O[SkipNFind0]
      
         mr              (G:O points to char, load it into R)
         nf >SkipNAt0    (If char zero, done)
         na 1            (Else increment G/O and check again)
         nj <SkipNFind0

      O[SkipNAt0] 6i RET
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

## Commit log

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2022-10-19 Add files via upload
    KiCad files for the CPU, PCB has been produced and tested
    [sonne-controller.kicad_pcb, sonne-controller.kicad_sch]
2022-10-19 Add files via upload
    KiCad files for the IO module, PCB has been produced and tested with CPU module
    [sonne-io.kicad_pcb, sonne-io.kicad_sch]
2022-10-19 Add files via upload
    EPROM ROM image file with ALU operations, created by blurgen.c
    [blur3.obj]
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2022-10-19 Add files via upload
    Bootstrap code for the NOR Flash. Sideloads your app from SPI EEPROM.
2022-10-20 Add files via upload
    KiCad files with schematics and routed PCB for the CPU, the PCB has been produced and is working fine
    [sonne-controller.kicad_pcb, sonne-controller.kicad_sch]
2022-11-02 Add files via upload
    This is a cross assembler that generates Sonne object code.
2023-07-18 Add files via upload
    This is the NOR-Flash ROM image for the IO board, it generates the bit patterns for the 7-segment display.
2023-07-20 Add KiCad project files for new (tested) IO board
    [sonne-io.kicad_pcb, sonne-io.kicad_sch]
2023-07-20 Add zip of final plan for simpler architecture
    This schematic seems to have a bug. The PCB has been fabricated and needs debugging!
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2023-09-27 Add KiCad design files
    [sonne-controller.kicad_pcb, sonne-controller.kicad_sch]
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2024-08-12 Check in WIP files
    [myth.kicad_sch]
2024-08-12 Fix KiCad files
    [myth.kicad_sch]
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2024-08-13 Add relative JUMPs and add decoders to E register
    [myth.kicad_sch]
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2024-08-13 Add folder structure move files
    [myth.kicad_sch]
2024-08-14 Identify xMx with O
    [myth.kicad_sch]
2024-08-14 Identify R register and B accumulator
    [myth.kicad_sch]
2024-08-14 Change GETPUT, add Q register
    [myth.kicad_sch]
2024-08-14 Add CALLER to SYS group
    [myth.kicad_sch]
2024-08-14 Revert Q reg to D
    [myth.kicad_sch]
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2024-08-15 Remove A, try R new/old
    [myth.kicad_sch]
2024-08-15 Rework everything
    [myth.kicad_sch]
2024-08-16 Remove offset-mapped segmentation
    [myth.kicad_sch]
2024-08-16 Fix the schematics
    [myth.kicad_sch]
2024-08-16 Add B register
    [myth.kicad_sch]
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2024-08-16 Fix bug in two adder instances
    [myth.kicad_sch]
2024-08-17 Change design using xB(ase) xA(dd) pair
    [myth.kicad_sch]
2024-08-17 WIP Edit single-stepper to reflect new KiCad model
    [myth.kicad_sch]
2024-08-17 Change folder structure
    [blur3.obj, sonne-controller.kicad_pcb, sonne-controller.kicad_sch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]
2024-08-18 Clean up the schematics
    [myth.kicad_sch]
2024-08-18 Add schematics
    [myth.kicad_sch]
2024-08-18 Rename BRA opcode FAR
    [myth.kicad_sch]
2024-08-21 Rename B register, change functionality of it
    [myth.kicad_sch]
2024-08-21 Add groff doc source
    [myth.kicad_sch]
2024-08-22 Rename A register to GI
    [myth.kicad_sch]
2024-08-22 Rename WTF to JW, JT, JF for clarity
    [myth.kicad_sch]
2024-08-24 Add INO/DEO scrounge opcodes
    [myth.kicad_sch]
2024-08-25 Change GETPUT opcode encoding
    [myth.kicad_sch]
2024-08-25 Update schematics file
    [myth.kicad_sch]
2024-08-26 Switch back to absolute addressing
    [myth.kicad_sch]
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2024-08-30 Fix missing break; bug in GETPUT switch statement
    [myth.h]
2024-08-31 Fix names re. J, adjust opcodes and fix scrounger section in schematics
    [myth.kicad_sch]
2024-08-31 Add native division routine
    [myth.kicad_sch]
2024-09-01 Implement changed semantics of xA in KiCad and myth[...].h
    [myth.kicad_sch]
2024-09-01 Replace ALU opcode IDR with CLR (set R to zero)
    [myth.kicad_sch]
2024-09-02 Shorten ADJUST to FIX, rename FIX type opcodes
    [myth.kicad_sch]
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2024-09-04 Initial WIP exchanging DO register pair for GI register pair during CALL/RET
    [myth.kicad_sch]
2024-09-04 Finish changes in KiCad file
    [myth.kicad_sch]
2024-09-04 Change Ix to Dx globally
    [myth.kicad_sch]
2024-09-04 Finish hardware changes
    [myth.kicad_sch]
2024-09-04 Work on regression bugs due to design changes
    [myth.kicad_sch]
2024-09-04 Fix naming of roid vs. giro
    [myth.h]
2024-09-04 Swap xI with xD in pair decoder, KiCad only
    [myth.kicad_sch]
2024-09-05 Simplify the design for nicer programming: Remove G register, re-introduce ENTER and LEAVE, add relative addressing
    [myth.kicad_sch]
2024-09-05 Fix KiCad schematics and POC native code
    [myth.kicad_sch]
2024-09-05 Rename G to D as before (D for Data)
    [myth.kicad_sch]
2024-09-06 Relocate pre-built symbol table
    [myth.kicad_sch]
2024-09-06 Fix native assembler source
2024-09-06 Write native SkipNULL function (advance to next NULL byte)
    [myth.h]
2024-09-07 Change mnemonic for NEW to OWN and reorder VM struct
    [myth.kicad_sch]
2024-09-07 Create JSON file with info on each instruction
    [myth.kicad_sch]
2024-09-08 Add hardware interrupt system
    [myth.kicad_sch]
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2024-09-09 Add work on automatically generating HTML docs
    [myth.kicad_sch]
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2024-09-11 Fix/add docs for scrounge opcodes
    [myth.kicad_sch]
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2024-09-13 Add slightly revised schematics
    [myth.kicad_sch]
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2024-09-14 Fix lid overflow bug, add symbol table source to asm file
    [lox.asm]
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2024-09-14 Fix avoid string-context in comments and vice versa
    [lox.asm]
2024-09-15 Fix image, add schematics update
    [myth.kicad_sch]
2024-09-15 Make various pending updates
    [myth.kicad_sch]
2024-09-15 Fix bug in handling of string literals
    [lox.asm]
2024-09-15 Fix bug in handling of parens in string runs
    [lox.asm]
2024-09-16 Fix bugs in firmware code
    [lox.asm]
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2024-09-17 Add virtual smem device and signal handling
    [myth.kicad_sch]
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2024-09-21 Fix bug in schematics
    [myth.kicad_sch]
2024-09-26 Fix bugs in schematics
    [myth.kicad_sch]
2024-09-26 Break monolithic schematics into six boards with shared pin-headers
    [clock.kicad_sch, creg.kicad_sch, dreg.kicad_sch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]
2024-09-26 Reduce number of shared headers
    [myth.kicad_sch, myth_alu.kicad_sch, myth_cdl.kicad_sch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]
2024-09-27 Improve schematics for readability
    [low.kicad_sch, myth_alu.kicad_sch, myth_cdl.kicad_sch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]
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2024-10-11 Change d to g
    [creg.kicad_sch, dreg.kicad_sch, fix.kicad_sch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]
2024-10-11 Fix bugs in vtable.c
    [myth.kicad_sch]
2024-10-11 Change E register semantics
    [myth.kicad_sch]
2024-10-12 Change CO do D
    [creg.kicad_sch, dreg.kicad_sch, enable.kicad_sch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]
2024-10-14 Change COR to use R
    [glue.kicad_sch, greg.kicad_sch, myth.kicad_sch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]
2024-10-17 Fix documentation re: change d->g
    [glue.kicad_sch, myth.kicad_sch, myth_io.kicad_sch]
2024-10-18 Update pencoder image
    [preselect.kicad_sch]
2024-10-18 Change website landing
    [myth_alu.kicad_sch, rreg.kicad_sch]
2024-10-18 Change semantics of xB
    [addr.kicad_sch, creg.kicad_sch, greg.kicad_sch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]
2024-10-18 Change signal names
    [glue.kicad_sch, ireg.kicad_sch, myth.kicad_sch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]
2024-10-18 Let defines/labels diverge from assembler mnemonics
    [glue.kicad_sch, into.kicad_sch, myth.kicad_sch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]
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
